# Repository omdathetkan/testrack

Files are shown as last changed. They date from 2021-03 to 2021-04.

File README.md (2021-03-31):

# Introduction
This repository contains design files and documentation for a modular test equipment rack. It was designed internally by Hiber to improve the efficiency around various test setups. It's targetted to the following use cases:
- Hardware bring-up and firmware development
- CI with Hardware in the Loop testing
- Integration testing of large / distributed systems

The key aspects on which it attempts to improve on are:
- Accessibility: Have every piece of hardware available on the network (and thus remotely)
- Portability: Make it easy to move components around or take them home.
- Repeatability: Make sure you always get the same results by having reproducable setups.
- Scaleability: The system should scale from develop desks (at home) ro large scale automated test racks.
- Low-Code: Where possible embedded firmware should be avoided so users not end up testing the test system. 

This work has been inspired by other great projects like these:
- [EasyPhi](http://www.easy-phi.ch/)
- [ARM Hardware Build Farm](https://www.collabora.com/about-us/blog/2013/04/26/collabora-custom-arm-hardware-build-farm/)
- [Raspberry Pi FM Stream Rack](https://medium.com/artica/fm-stream-tech-report-30b23c098bdb)

## License
The design has been made open source hoping that others can benifit from it. There is a lot of potential for adding additional modules (Like a configurable power supply, additional interfaces and various measurement equipment). All designs provided in this repository are released under [Apache 2.0 License](/LICENSE).

## Used Software
Boards have been made in Altium Designer, Mechanical assemblies have been done in CATIA. Neutral exports file formats are provided.

## Status
The Backplane and Breadboard module initial prototypes are finished. The Raspberri Pi Host module still have to be made for the system to start being practical (unless used for Ethernet Only applications). 

# System overview
The system is based on the very commonly used Eurocard Subrack formfactor. It is commonly used by modular test equipment like the PXI chassis and many others. The individual mechanical components are relatively low cost and widely available from multiple vendors. This design is baselined on the Schroff europacPro series and their Plug-In units, but others can be used if preferred.

A typical 19" rack is 3U high and 84HP wide (1 Horizontal Pitch = 5.08mm). In this housing the user can slide in Eurocard size PCBs or Modules with a 4HP wide pitch. The modules can either consist of instrumentation equipment or the Device Under Test itself. A generic backplane PCB provides connectivity and power to modules that are hot-swappable. By splitting the backplane into 3 identical 28HP segments the system can be scaled down to partial racks and benchtop housings.

It is highly recommended to scroll through Schroff's [catalog](https://schroff.nvent.com/sites/g/files/hdkjer281/files/acquiadam/2020-11/06_e_subracks.pdf) to get an idea about the possibilities. For example an 6U enclosure could also be used to support larger modules or double the capacity (or a combination of both).

## Enclosures

### Benchtop
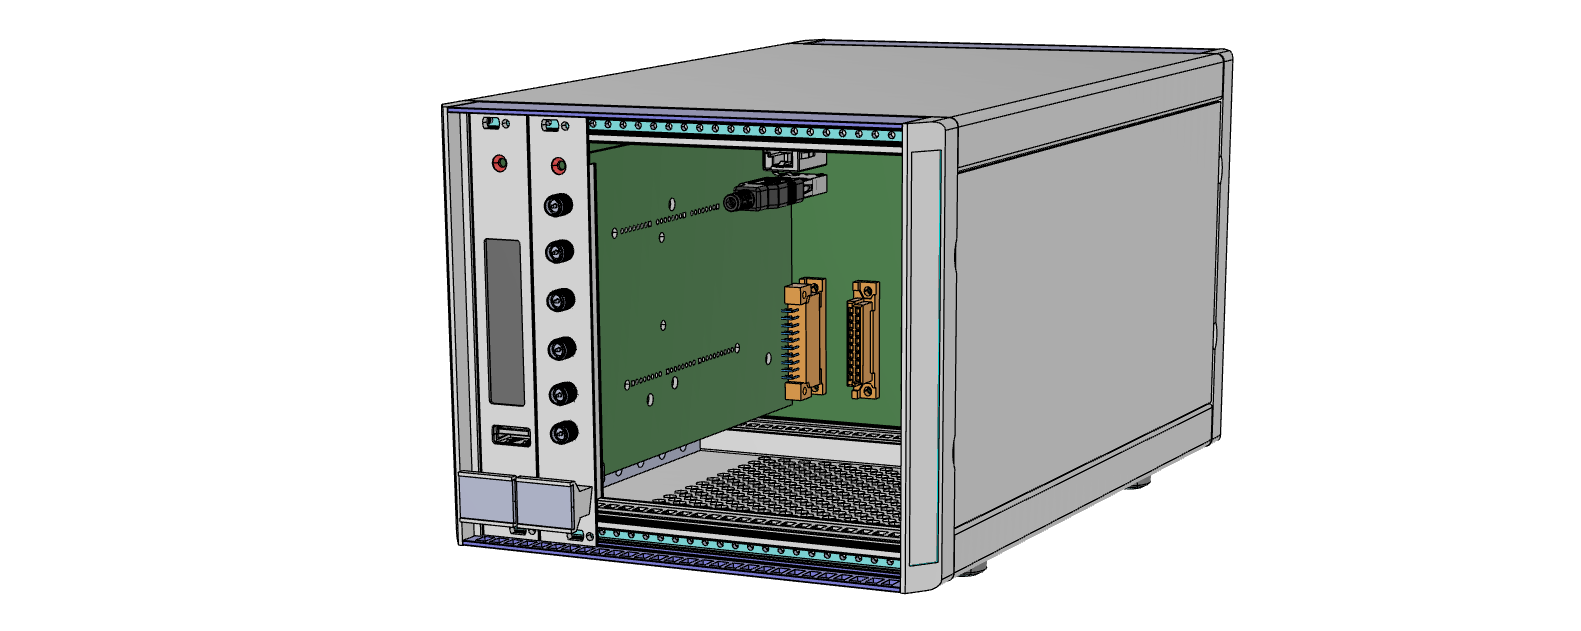
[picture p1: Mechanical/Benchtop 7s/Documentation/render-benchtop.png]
Benchtop Assembly Render


For small setups or engineering workbenches a compact form factor is available. A 28HP housing can house a single backplane with an internal AC power supply. Bill of Material and Assembly instructions can be found in it's [directory](./Mechanical/Benchtop%207s)

### 19" Rack
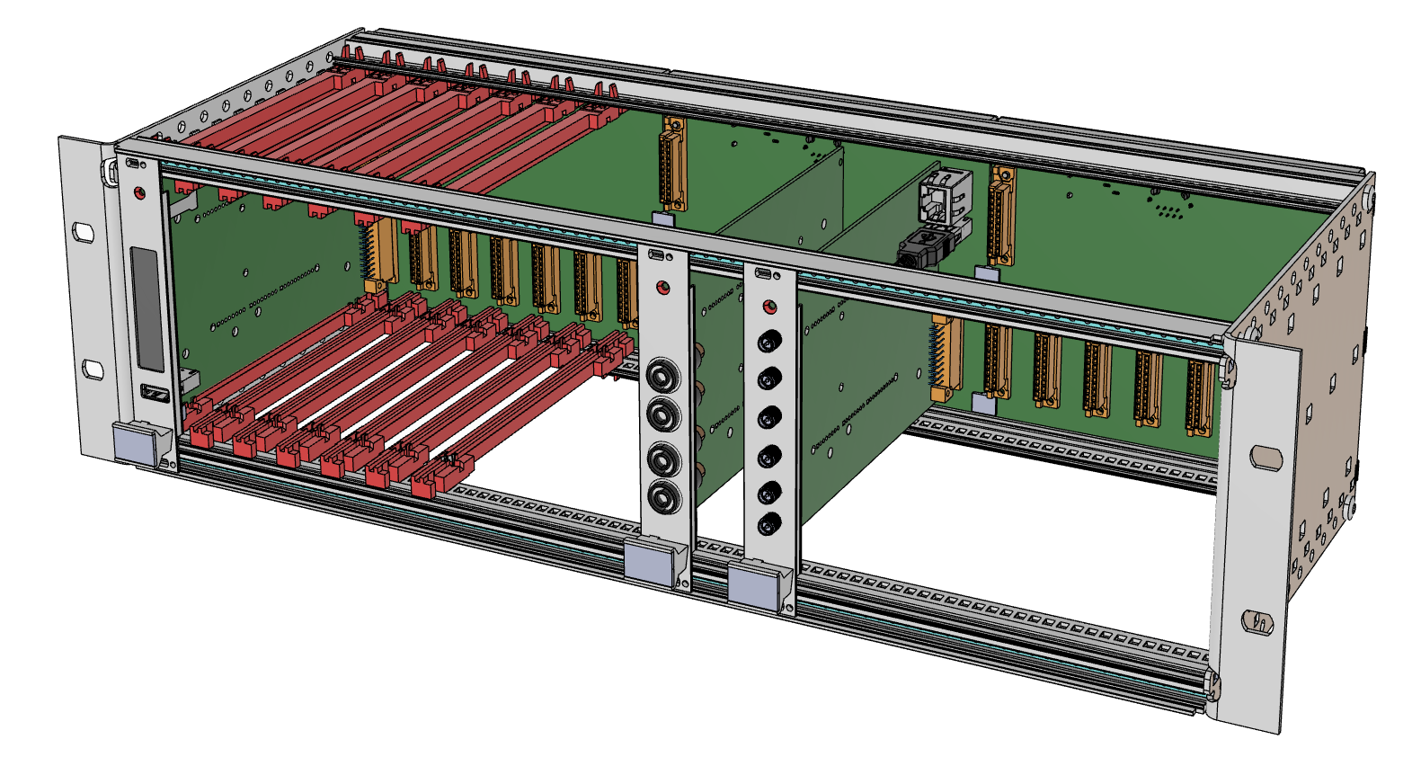
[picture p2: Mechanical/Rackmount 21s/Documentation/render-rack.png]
19" Rack Assembly Render


For larger scale setups a full 19" Rack can hold up to 21 modules. Bill of Material and Assembly instructions can be found in it's [directory](./Mechanical/Rackmount%2021s)

### Stand-alone Adapter
To be Designed... Mostly used for troubleshooting. Similar to [this](http://easy-phi.unige.ch/index.php/products/racks-and-adapter/stand-alone-adapter). PoE? USB-C? Alternatively a 20-pin extension cable could potentially be used?

## Backplane
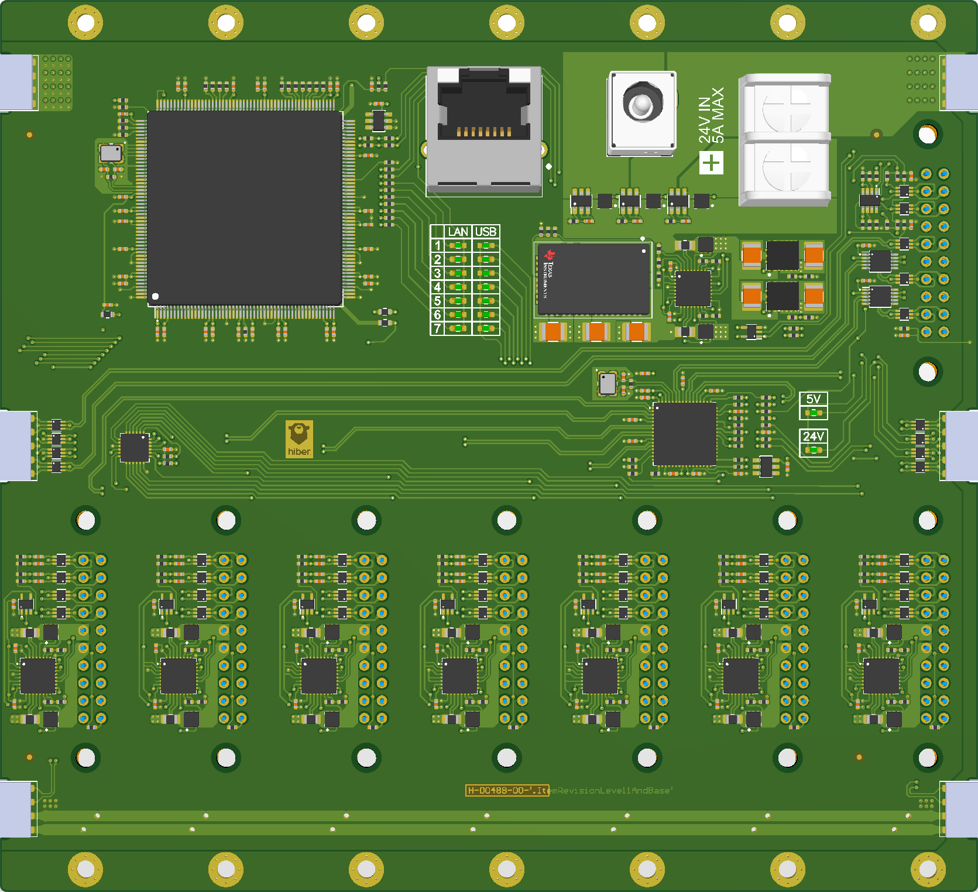
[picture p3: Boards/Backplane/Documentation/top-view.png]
Top view of backplane board


The core of the system is a 3U / 28HP backplane PCB that can be mounted in various mechanical configuations. The main functionality is:
- 24V Powered (5A Max)
- 7 Slots, of which 1 can be used as host (USB+I2C)
- Daisy-chainable up to three boards to fill a full rack
- 24V and 5V power distribution, protection and monitoring to modules (2A Max)
- 100Mbps Ethernet Switch (KSZ8999: 7 Slots + Uplink)
- USB 2.0 Hi-Speed 7-Port Hub Controller (USB2517)
- I2C Mux

More details (including pinouts) and design files can be found in it's [directory](./Boards/Backplane/).

## Modules

### Template
TBD

### CM4 Host
In Progress...

### Generic Carrier
A Generic plug-in card that contains a breakout connector for Ethernet and USB, as well as pads for the various other signals. It contains an EEPROM with UID for identification, and a MCP... port expander that can be used to drive distrete equipment.

It can be used to carry dev boards, boards to test or any other equipment.

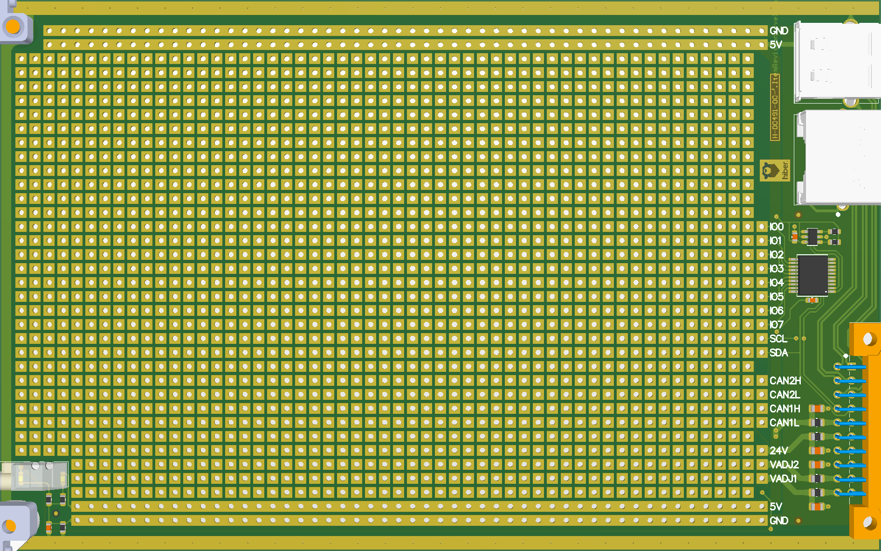
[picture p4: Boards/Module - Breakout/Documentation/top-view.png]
Top view of generic carrier board


Design files can be found in it's [directory](./Boards/Module%20-%20Breakout/).

## Ideas
- 6x Micromod carrier (Using USB2517) for testing wireless netwoks?

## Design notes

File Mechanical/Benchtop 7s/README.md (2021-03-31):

# Benchtop Enclosure
For smaller setups, or engineering workbenches a smaller form factor can be desirable. An 28HP housing can host a single backplane, as well as an internal AC power supply.

19" Rack Render
(TODO: Update render with guides and ESD clips)

The STEP model of the assembly is available [here](./Benchtop%20Assembly.stp)
(TODO: Add STEP Model)

# Bill of Materials

| Qty | Description | Manufacturer | Partnumber |
|-----|---|---|---|
| 1 | RatiopacPRO, Complete Case, Desktop, Unshielded, Front Trim, 3U, 28 HP | Schroff | 24572-001 |
| 14  | Guide Rail Standard Type, Groove Width 2 mm, 160 mm, Red, SPQ 50 | Schroff | 64560-001 |
| 7 | Guide Rail ESD Clip | Schroff | 24560-255 |
| 1 | AC-DC Single output Open frame power supply; output 24Vdc at 5.9A | Meanwell | EPP-200-24 |
| 1 | AC Power Entry Modules 15A WIRE-LEADED | TE | 15SRBX8-R |
| 1 | RJ-45 Ethernet Round Panel Mount Extension Cable - 30cm | Adafruit | 4215 |
| 1 | Connector Housing 3POS 3.96MM | JST | VHR-3N |
| 1 | Connector Housing 6POS 3.96MM | JST | VHR-6N |
| 6 | Pre-Crimped Jumper wire VH Series 16 AWG - 100mm* | JST | ASVHSVH16K102  |
| 4 | A2 s/steel cross pan head screw, M3 x 6mm | RS PRO | 528-738 |
| 14  | A2 s/steel cross pan head screw, M2.5 x 16mm | RS PRO | 914-1484 |
| 1 | Rear Panel with mount for Power supply and Connectors (CNC Machined) | | |
| 1 | Backplane PCB assembly (with protective cover) | | |

# Rear Panel
A customized rear panel is used instead of the one included with the kit. It can be ordered through Frontpanel Designer (US: [Frontpanel Express](https://www.frontpanelexpress.com/), EU: [Schaeffer](https://www.schaeffer-ag.de)).

Design files for Frontpanel Express are included in the [Rear Panel subfolder](./Rear%20Panel/). DXF and STEP files are also included.

# Assembly Instructions

## Rear Panel
- Install Ethernet Extension Cable and fasten ring nut.
- Insert power entry module (snaps into place)
- Mount Power supply on rear panel standoffs using M3-L6 Screws (Allign Line voltage on power entry side)
- Cut power entry wires to [xxx]mm, crimp terminals?
- Insert Pre-crimped wires into 6-way housing, cut to [xxx]mm length and strip around 5mm.

(TODO: Use pre-crimped wires or crimp on Power Entry Leads?)

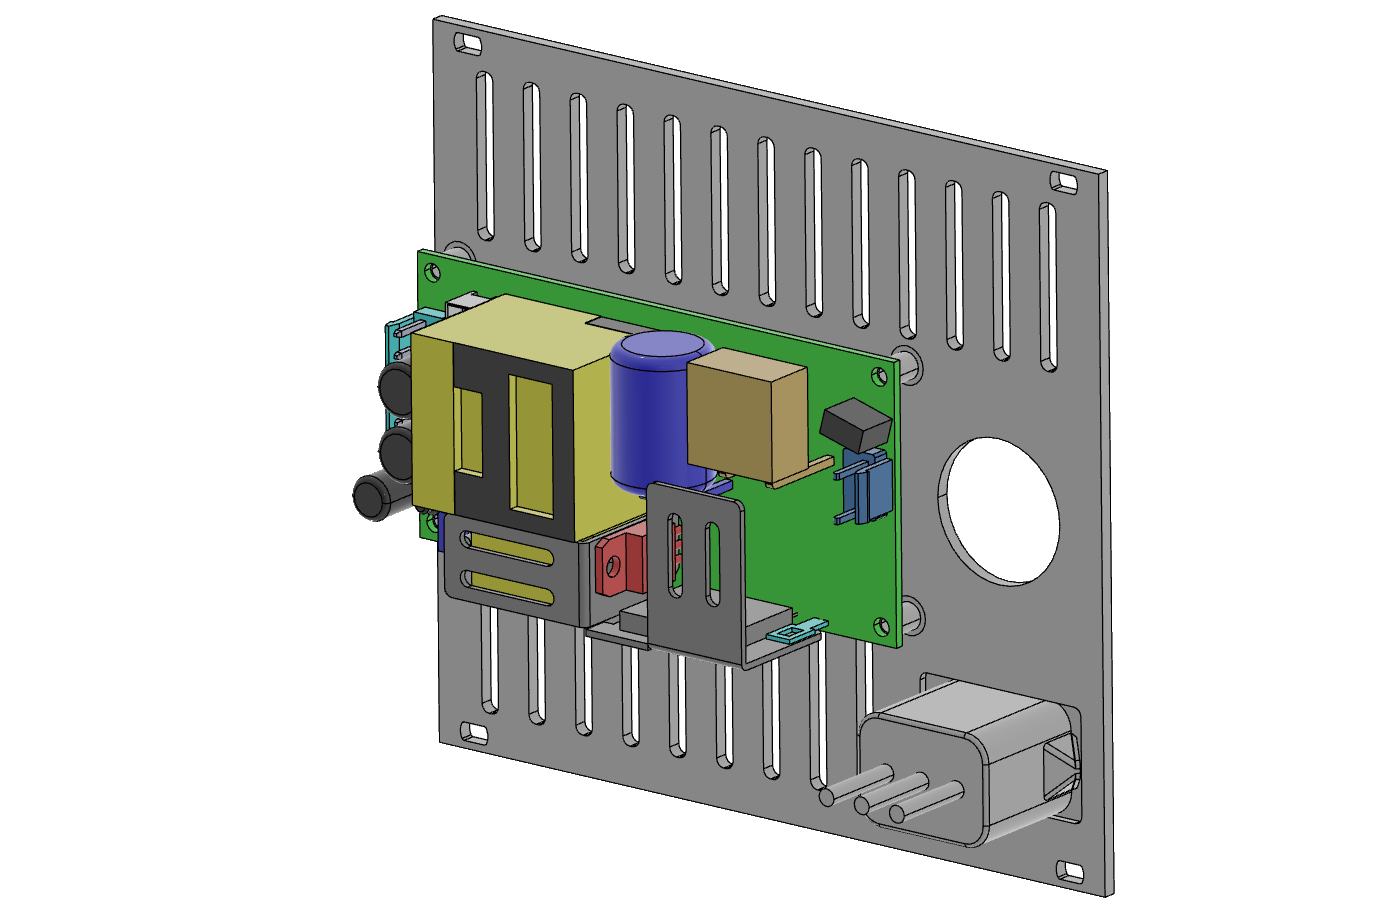
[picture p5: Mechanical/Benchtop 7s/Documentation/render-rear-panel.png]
Rear Panel Render


## Assemble Case Frame
- Partially assembly case frame according to Schroff instructions:

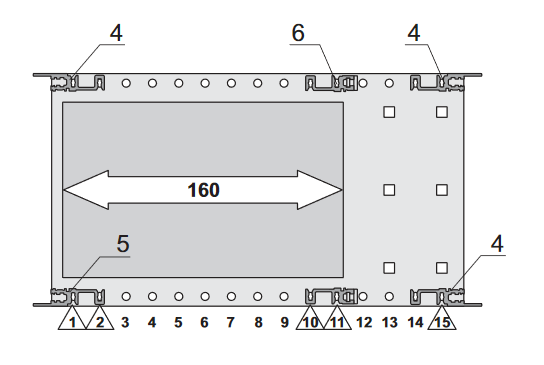
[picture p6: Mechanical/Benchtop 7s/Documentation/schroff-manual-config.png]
Schroff assembly configuration


- Note that it is easier to mount the backplane PCB before placing the rear rails:

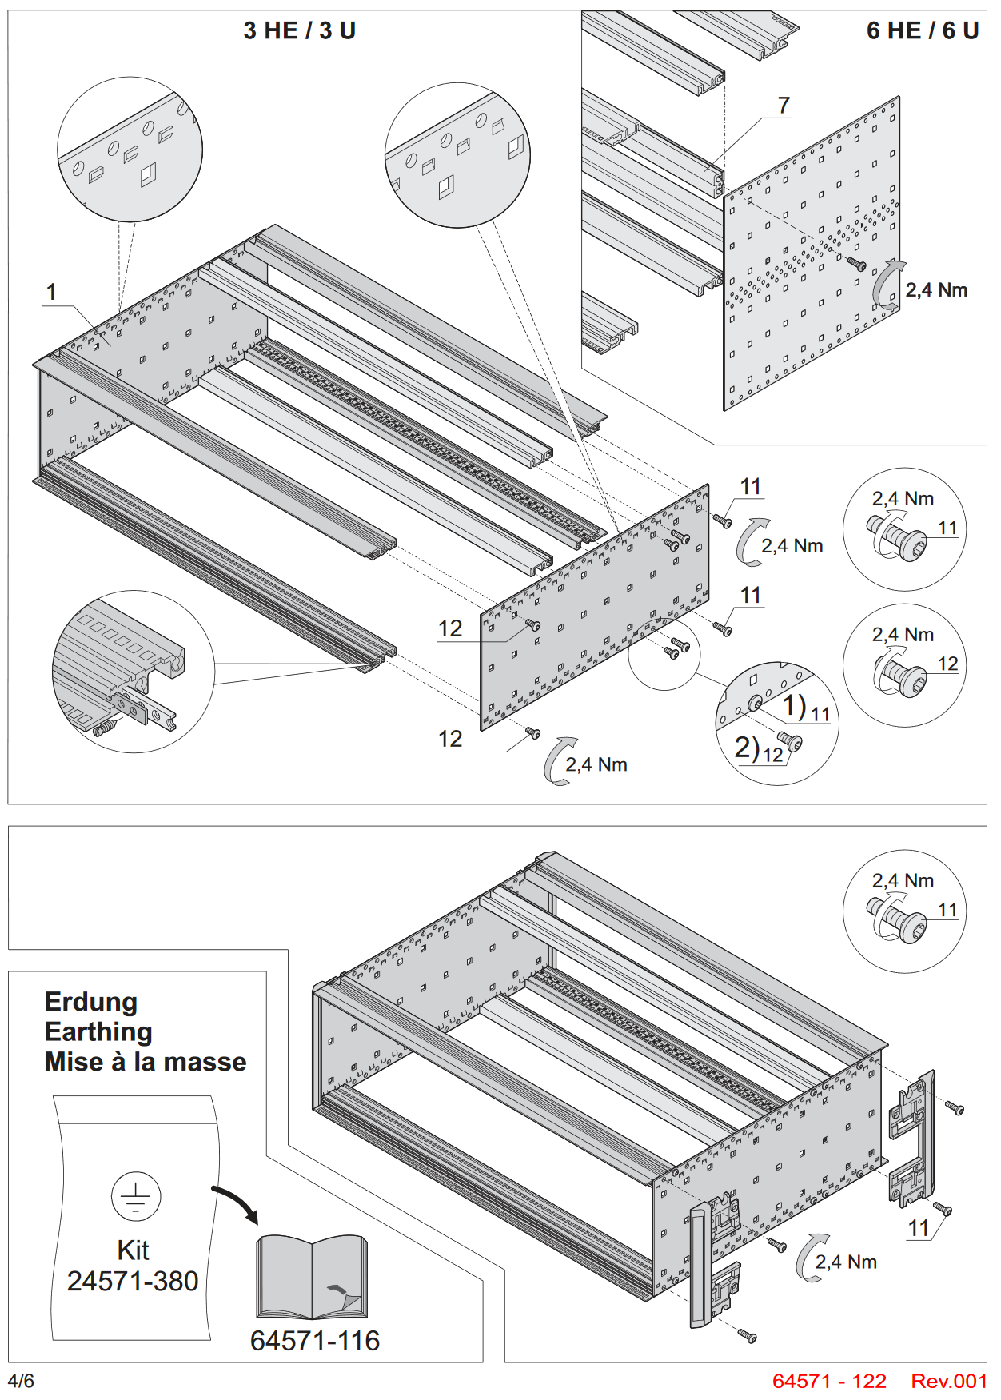
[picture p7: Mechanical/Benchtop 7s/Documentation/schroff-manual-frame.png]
Schroff frame assembly instructions


- Place backplane to frame (Check alignment?) and fasten using M2.5 screws.
- Insert Rails with ESD clips on bottom side with 4HP spacing (2 free holes in between each rail)
- Insert Rails without ESD clips on top side
- Install Ground wiring (TODO)
- Plug Ethernet Cable in
- Connect 24V Leads to wire terminals (TODO)
- Power on, verify functionality
- Snap on outer panels according to Schroff instructions:

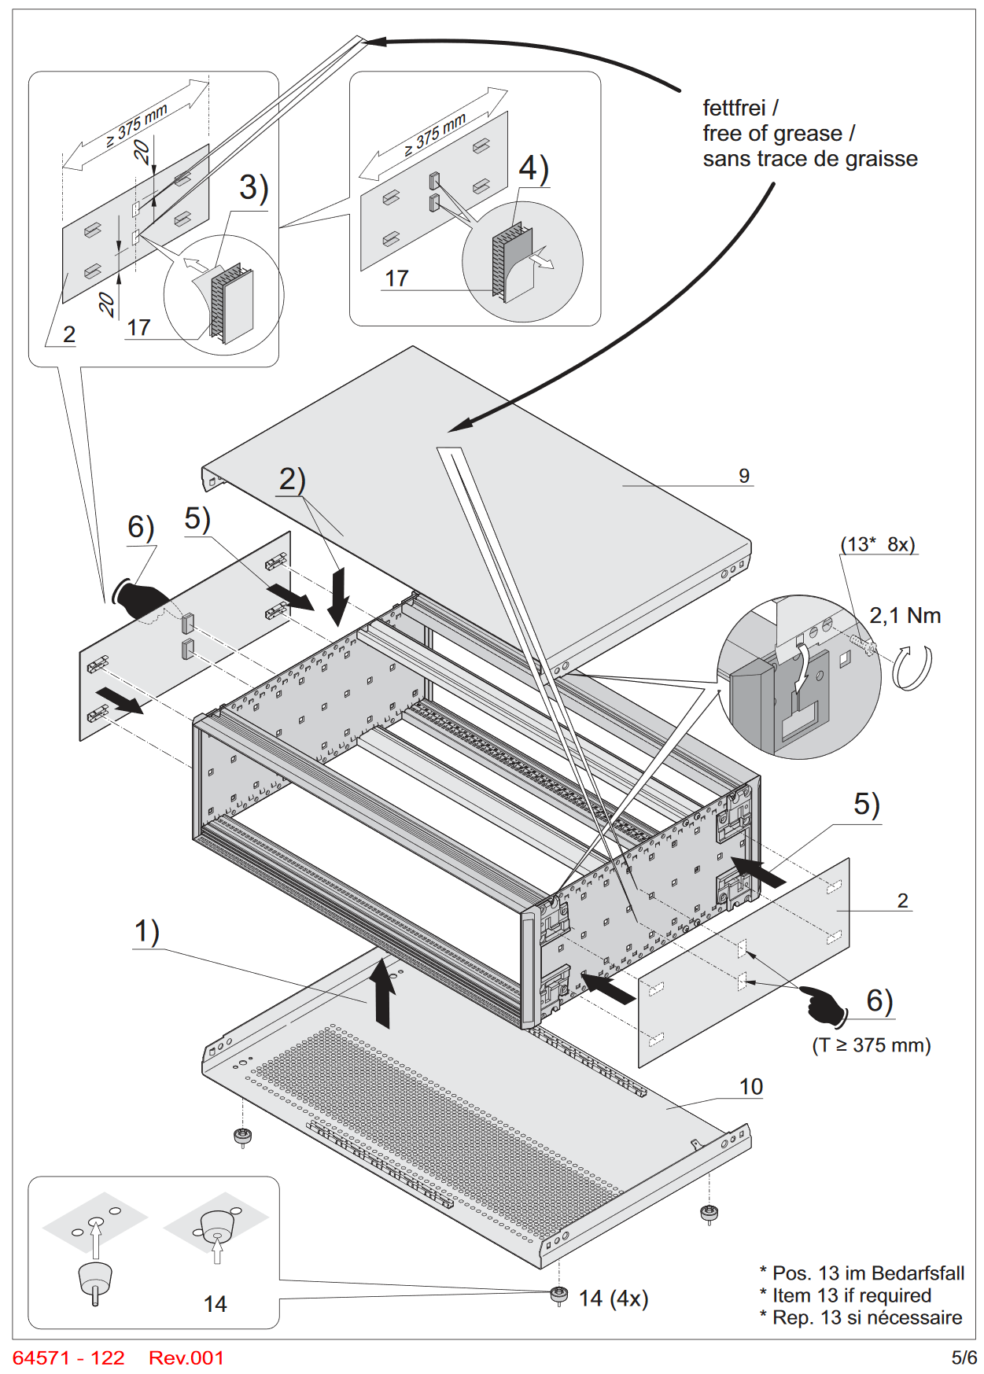
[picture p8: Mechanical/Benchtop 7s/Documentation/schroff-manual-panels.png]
Schroff panel assembly instructions


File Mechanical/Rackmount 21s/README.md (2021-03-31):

# 19" Rack
For larger scale setups a full 19" Rack can hold up to 21 modules. 

19" Rack Render
(TODO: Update render with guides and ESD clips)

The STEP model of the assembly is available [here](./Rack%20Assembly.stp)
(TODO: Add STEP Model)

# Bill of Materials

| Qty | Description | Manufacturer | Partnumber |
|-----|---|---|---|
| 1 | EuropacPRO 19" Subrack Kit for DIN Connector, Retrofit Shielding, 3U | Schroff | 24563-192 |
| 42  | Guide Rail Standard Type, Groove Width 2 mm, 160 mm, Red, SPQ 50 | Schroff | 64560-001 |
| 21  | Guide Rail ESD Clip | Schroff | 24560-255 |
| 42  | A2 s/steel cross pan head screw, M2.5 x 16mm | RS PRO | 914-1484 |
| 4 | CONN SSL BRIDGE 8POS 2MM | AVX | 009159008061916 |
| 2 | CONN SSL BRIDGE 10POS 2MM | AVX | 009159010061916 |
| 3 | Backplane PCB assembly (with protective cover) | | |

# Assembly Instructions

- Assembly frame according to Schroff Instructions

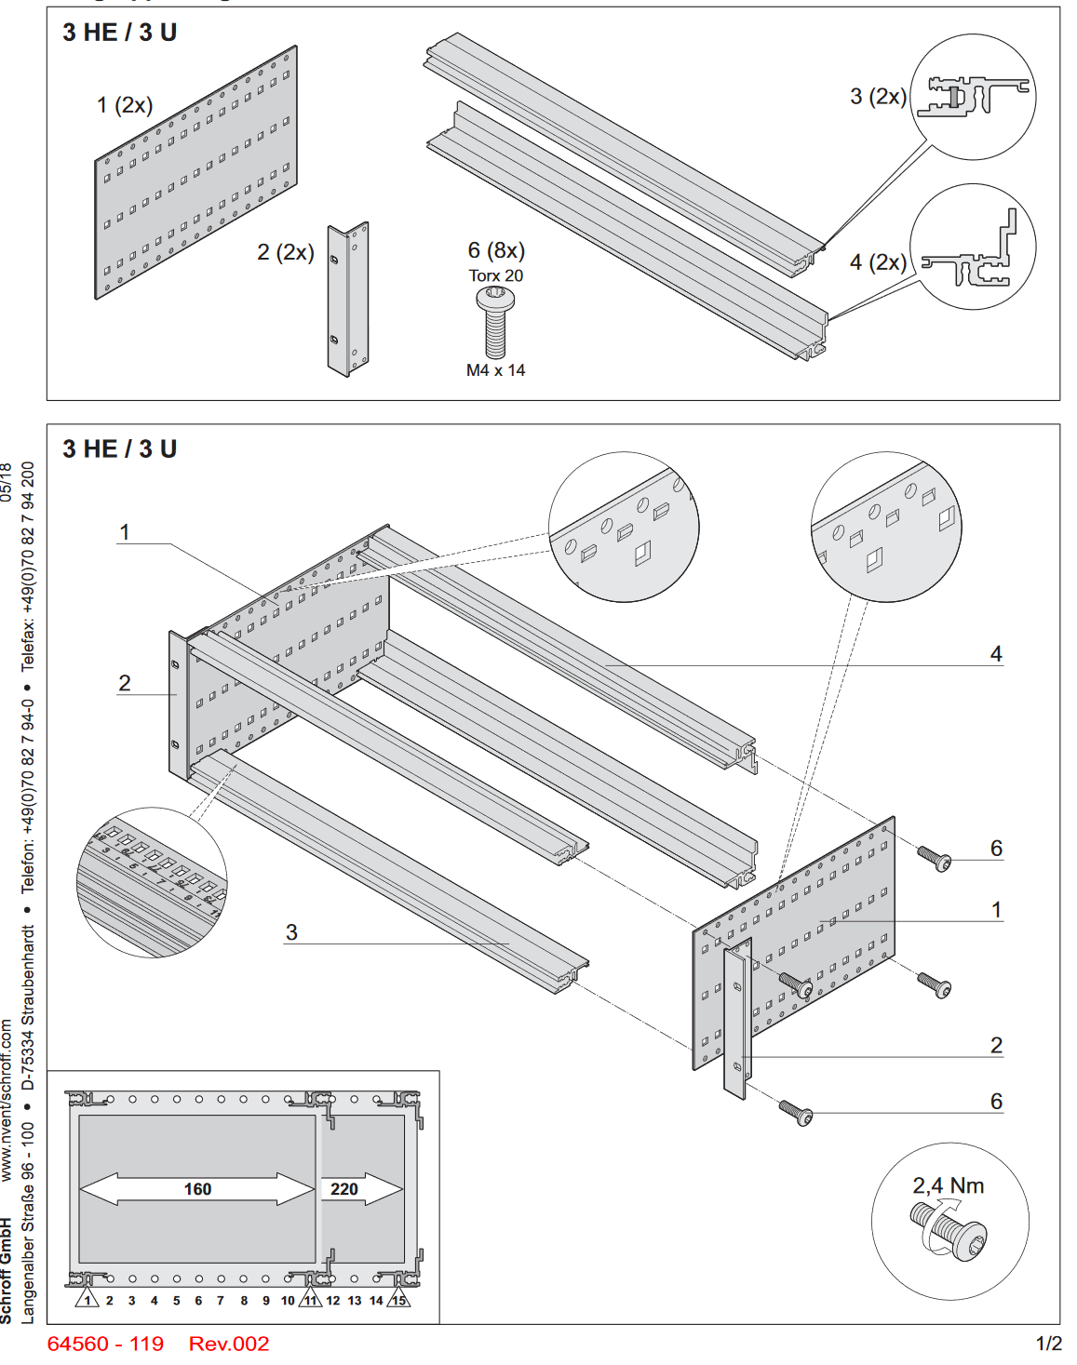
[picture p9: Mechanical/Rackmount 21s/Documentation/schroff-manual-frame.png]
Schroff frame assembly instructions


- Mount Single backplane using M2.5 Screws
- Slide in Bridge Connectors
- Mount Slide in second backplane and fasten.
- Repeat for last backplane

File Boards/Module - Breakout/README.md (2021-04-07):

# Breakout Module
Top view of backplane board
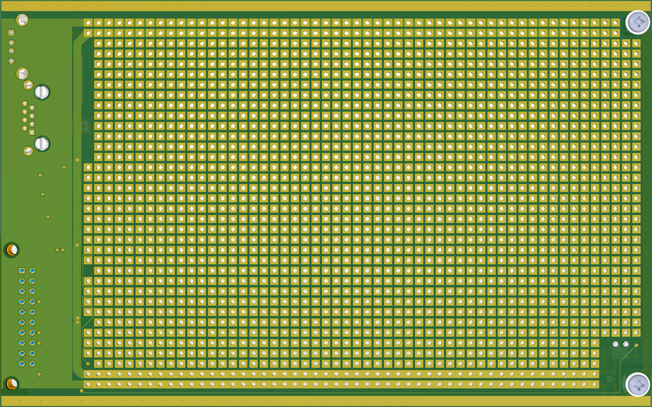
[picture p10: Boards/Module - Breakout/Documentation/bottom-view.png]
Bottom view of backplane board


This module can be used integrate any existing board or other hardware to the system.

One way is by using solderable thread inserts, like the ones from [Wurth](https://www.we-online.com/web/en/electronic_components/produkte_pb/produktinnovationen/smtspacer.php).

For larger boards a (short) Right-Angle usb cable might be needed, for example: Startech Male USB A to Male USB Micro B USB Cable, USB 2.0, 300mm, USB A, USB Micro B UUSBHAUB1LA

To install a board:
- Identify the appropriate standoff height (ideally make sure nothing extends over the frontpanel).
- Attach the spacers to the board and place the board on the desired location.
- Solder down a corner of each spacer and remove the board.
- Strengthen solder joints.
- Re-install board (plug in cables)

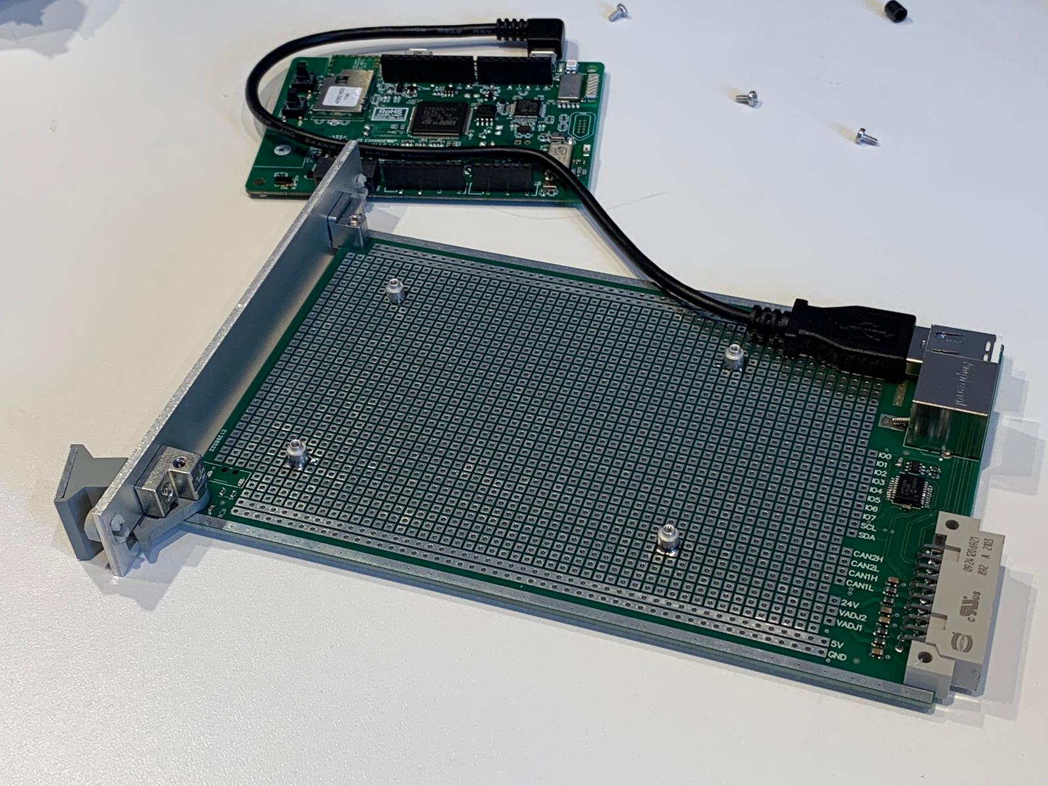
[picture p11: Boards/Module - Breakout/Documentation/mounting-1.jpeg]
Picture of spacers soldered to board


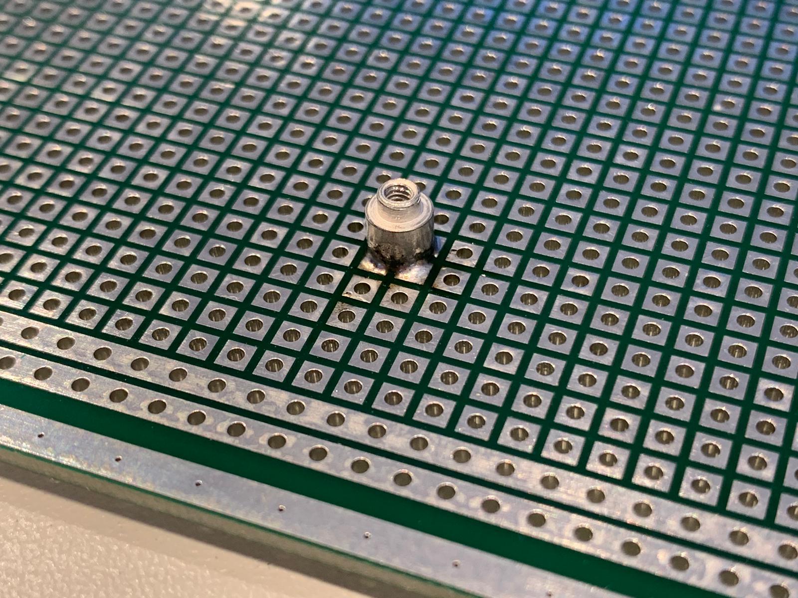
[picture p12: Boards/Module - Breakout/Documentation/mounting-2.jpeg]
Close-up of spacer soldered to board


Picture of board mounted on spacers

nVent-SCHROFF, 3U Plug-in Unit

RS-stocknr.:
    258-2920
Fabrikantnummer:
    20817443
Fabrikant:
    nVent-SCHROFF

# Version History

## A.3
First Release

### Known Issues
- Missing Pin-1 Indicator on U10
- Increase solder mask sliver between ESD Cap/Res
- USB D+/D- Swapped

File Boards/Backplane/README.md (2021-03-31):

# Backplane
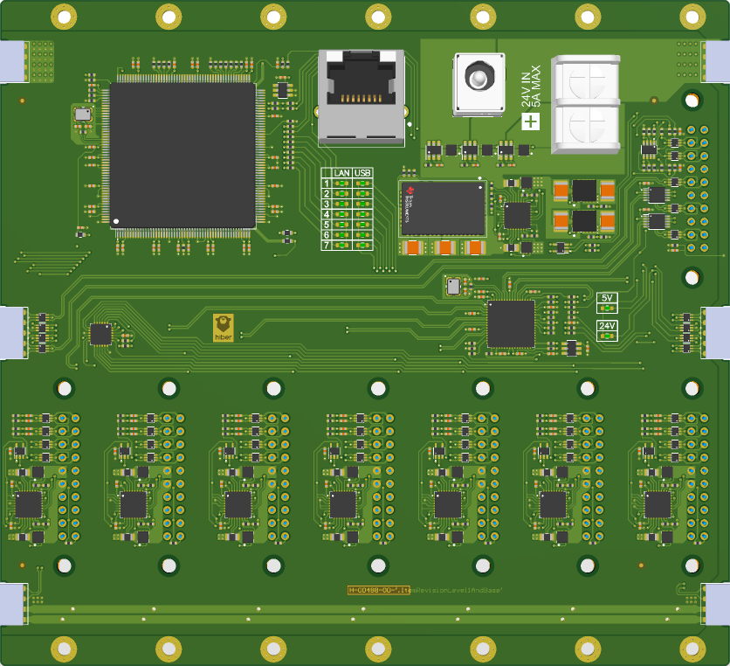
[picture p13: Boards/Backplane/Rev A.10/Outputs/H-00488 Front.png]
Top view of backplane board

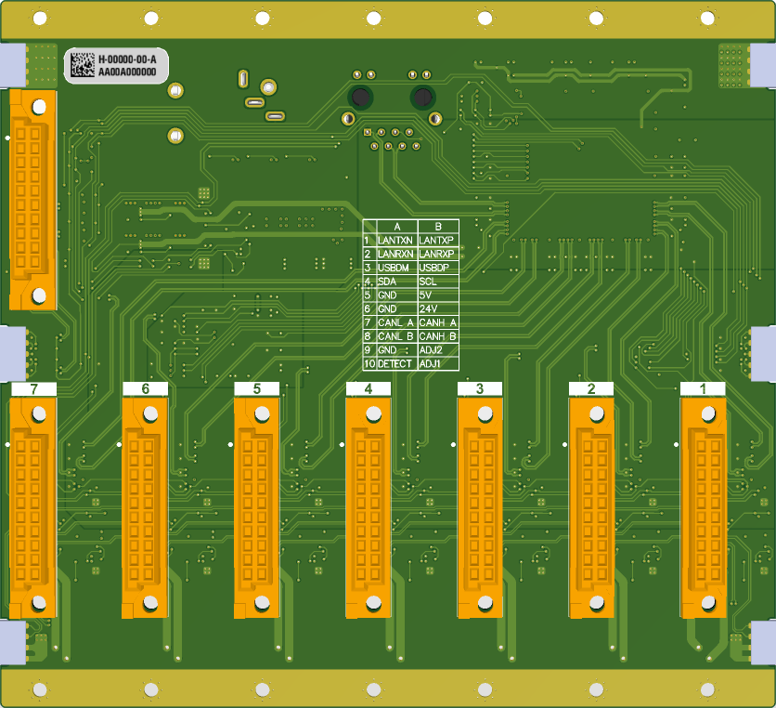
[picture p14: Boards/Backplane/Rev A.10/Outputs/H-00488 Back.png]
Bottom view of backplane board


The core of the system is a 3U / 28HP backplane PCB that can be mounted in various mechanical configuations. The main functionality is:
- 24V Powered (5A Max)
- 7 Slots, of which 1 can be used as host (USB+I2C)
- Daisy-chainable up to three boards to fill a full rack
- 24V and 5V power distribution, protection and monitoring to modules (2A Max)
- 100Mbps Ethernet Switch (KSZ8999: 7 Slots + Uplink)
- USB 2.0 Hi-Speed 7-Port Hub Controller (USB2517)
- I2C Mux (Dedicated channel for each module)
- 2 Additional voltage rails and 2 differential pairs (CAN) - passively connected between slots

Image of backplane pcb topology

It uses [DIN 41612](https://en.wikipedia.org/wiki/DIN_41612) connectors for the plug-in modules, for examaple the [Harting 09241206921](https://b2b.harting.com/ebusiness/nl/DIN-Signal-3B020MS-30C1-2/09241206921), but since it's a standard other vendors are also available.

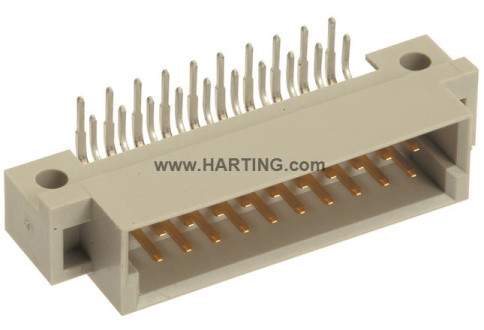
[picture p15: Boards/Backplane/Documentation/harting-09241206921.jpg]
Picture of a Harting 09241206921


Optionally the rear can be covered using 2-layer laser-cut acrylic sheets for protection against bumps and shorts. Details can be found [here](./Protective%20Cover).

Mating Connector for Power Jack: PP3-002B (2.5mm Pin / 5.5mm Diameter)

### Slot Interface
Each slot has a 20-pin connector (3B, Bottom-aligned) connector with the following pinout:

| | A | B |
|----|---|---|
| 1  | LAN RX- | LAN RX+ |
| 2  | LAN TX- | LAN TX+ |
| 3  | USB D-  | USB D+  |
| 4  | SDA | SCL |
| 5  | GND | +5V |
| 6  | GND | +24V |
| 7  | CANA L  | CANA H  |
| 8  | CANB L  | CANB H  |
| 9  | GND | VADJ2 |
| 10 | DETECT  | VADJ1 |

Modules are hot-swappable. By grounding the detect pin is on the plug-in module the Hot-Swap controller will enable power. 
Note that Ethernet is capacitively coupled - use of additonal magnetics might be advised depending on the application.

## Host Interface
There is a special host slot which has a second 20-pin connector which is used for USB-Host and I2C Master functionality. For Ethernet based functionality the use of this is optional.

It has the following pinout:

| | A | B |
|----|---|---|
| 1  | NC | NC |
| 2  | SDA_HOST  | SCL_HOST  |
| 3  | DETECT | RESET_HOST|
| 4  | GND | GND |
| 5  | USB3 D- | USB3 D+ |
| 6  | GND | GND |
| 7  | USB2 D- | USB2 D+ |
| 8  | GND | GND |
| 9  | USB1 D+ | USB1 D+ |
| 10 | GND | GND |

Note that USB 1 is from the backplane itself, USB 2 and 3 are from daisy chained backplanes if present. When there is no host card present, USB 1 and 2 are routed to the daisy chain connector (to be come USB 2 and 3 on the next board).

Image showing USB daisy chain topology

For a typical setup this slot contains something like a Raspberry Pi to control the rest of the system and/or bridge it to the network.

# Version History

## B.X
Scheduled - to fix known issues on version A.10

### Changes
LTC4222 optional? LAN/USB optional?

## A.10
First Release

### Known Issues
- LTC4222 generates INTVCC from VDD2, which is 5V, which is gated by itself, 5V/24V need to be swapped
    - Rework: Bypassed primary 24V Hot Swap controller output with a jumper wire
- I2C Mux messed up pinout ([excel table](./Documentation/rework-reva-i2cmux.md))
    - Rework: Swapped some nets to fix I2CM and I2C0 ([picture](./Documentation/rework-reva-i2cmux.png))
- I2C A0/A1 missing pull-up (or push/pull output (Both NC/NC)
    - Rework: Added A0/A1 pull-up 4k7 ([picture](./Documentation/rework-reva-address-pullup.png))
- Bad US_REF value (Also update table)
    - Rework: Swapped R199/R200
- Edge connector slots are too short and flipped between left/right
    - Rework: Cut material using scalpel
- I2C LTC4222 Address overlap with SLOT2/Main power
    - Rework: Connected PWR_ADR0 to GND
- 24V/5V PGOOD has some issues, might be due to under/overcurrent config
    - *TODO*
- RJ45 Jack LED Polarity is reversed
- Silkscreen indicating upstream/downstram direction is missing
- 24/5V LED silkscreen is swapped
- USB/LAN EEPROMs should be depopulated?
- Wash after hand solder (Eurocircuits)
- Missing EEPROM/Serial chip for identification

### TODO
- Validate power rail stability/noise
- Validate overcurrent protection (board / module level)
- Measure current consumption for USB/LAN
v Test I2C Address Daisy chain
- Validate thermal performance with and without plastic cover (especialy on buck converters)
- Validate hot-swapping behavior
v Validate USB daisy chaning
- Check weird sounds

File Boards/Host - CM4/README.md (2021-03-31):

# Raspberry Pi CM4 Host Module

## Notes

- USB Connector : 2169890001 / KUSBX-SL-CS1N14-B

https://github.com/QWaveSystems/QWAVE_Raspberry-Pi-CM4-Altium-Library

https://datasheets.raspberrypi.org/cm4io/cm4io-datasheet.pdf#page=11
USB2514B-I/M2
FSUSB42MUX

2x CAN-FD

24V-5V?
24V-VLCD

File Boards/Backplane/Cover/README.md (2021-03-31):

# Protective Cover
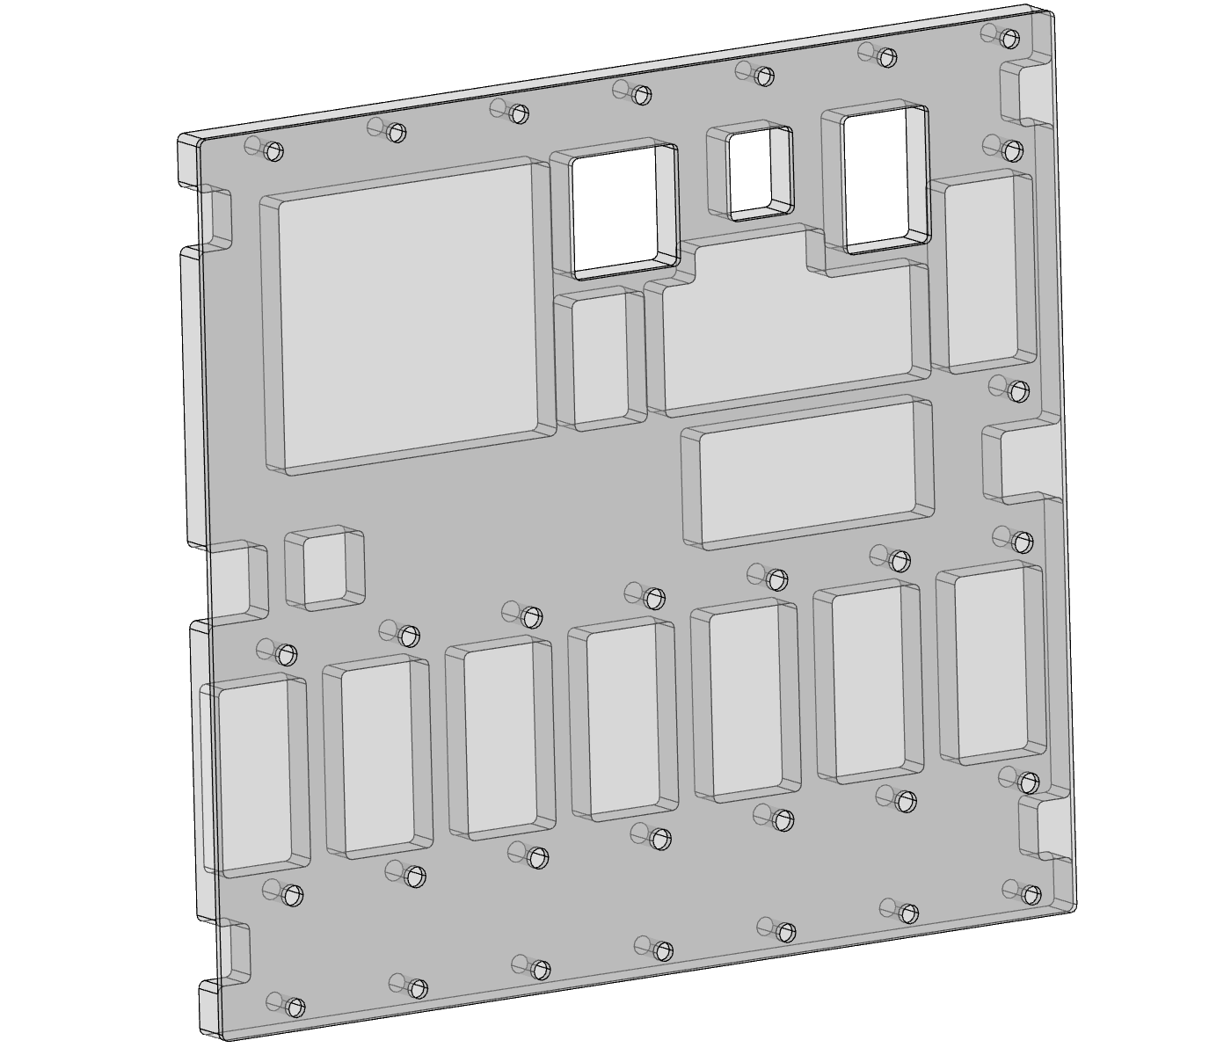
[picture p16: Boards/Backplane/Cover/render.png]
Isometric view of backplane cover render


A Protective cover made of two laser cut acrylic sheets that can be mounted on the back of the backplane board. It provides some extra protection against mechanical abuse or accidental shorts. Design files can be found in this folder.

The 2 layers can be laser cut from many materials. Transparant Acrylic is an option. The spacer needs to be 5mm think to accomodate component height.

# Bill of Materials

| Qty | Description | Manufacturer | Partnumber |
|-----|---|---|---|
| 14  | A2 s/steel cross pan head screw, M2.5 x 12mm | RS PRO | 528-722 |
| 14  | A2 S/Steel Locking Half Nut, DIN 439, M2.5 | RS PRO | 122-4399 |
| 1 | Backplane PCB assembly | | |
| 1 | Protective Spacer | | |
| 1 | Protective Cover | | |

# Assembly Instructions

Note: Removing protective liner on acrylic sheets creates significant charge. Make sure this is dissipated before installation!

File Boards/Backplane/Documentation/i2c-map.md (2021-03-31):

# Board global address nets

A is made from A0 and A1 using N-Fet?

| Board  | A0 | A1 | A |
|---|----|----|-----|
| Left | H  | H  | L |
| Middle | L  | H  | NC  |
| Right  | H  | L  | H |

# I2C Mux - TCA9548

| A2 | A1 | A0 | Address | Binary | Position |
|----|----|----|---|---|---|
| L  | L  | L  | 0x70 | 0b1110000 | Board 0 |
| L  | L  | H  | 0x71 | 0b1110001 | Board 1 |
| L  | H  | L  | 0x72 | 0b1110010 | Board 2 |
| L  | H  | H  | 0x73 | 0b1110011 | |
| H  | L  | L  | 0x74 | 0b1110100 | |
| H  | L  | H  | 0x75 | 0b1110101 | |
| H  | H  | L  | 0x76 | 0b1110110 | |
| H  | H  | H  | 0x77 | 0b1110111 | |

# Hot Swap Controllers - LTC4222

| A2 | A1 | A0 | Address | Binary | Position |
|----|----|----|---|---|---|
| X  | X  | X  | C6 | 0b1100011 | |
| X  | X  | X  | 19 | 0b0001100 | |
| L  | NC | L  | 88 | 0b1000100 | Board 0 - In |
| L  | H  | NC | 8A | 0b1000101 | Board 0 - Slot 1 |
| L  | NC | NC | 8C | 0b1000110 | Board 0 - Slot 2 |
| L  | NC | H  | 8E | 0b1000111 | Board 0 - Slot 3 |
| L  | L  | L  | 98 | 0b1001100 | Board 0 - Slot 4 |
| L  | H  | H  | 9A | 0b1001101 | Board 0 - Slot 5 |
| L  | L  | NC | 9C | 0b1001110 | Board 0 - Slot 6 |
| L  | L  | H  | 9E | 0b1001111 | Board 0 - Slot 7 |
| NC | NC | L  | A8 | 0b1010100 | Board 1 - In |
| NC | H  | NC | AA | 0b1010101 | Board 1 - Slot 1 |
| NC | NC | NC | AC | 0b1010110 | Board 1 - Slot 2 |
| NC | NC | H  | AE | 0b1010111 | Board 1 - Slot 3 |
| NC | L  | L  | B8 | 0b1011100 | Board 1 - Slot 4 |
| NC | H  | H  | BA | 0b1011101 | Board 1 - Slot 5 |
| NC | L  | NC | BC | 0b1011110 | Board 1 - Slot 6 |
| NC | L  | H  | BE | 0b1011111 | Board 1 - Slot 7 |
| H  | NC | L  | C8 | 0b1100100 | Board 1 - In |
| H  | H  | NC | CA | 0b1100101 | Board 1 - Slot 1 |
| H  | NC | NC | CC | 0b1100110 | Board 1 - Slot 2 |
| H  | NC | H  | CE | 0b1100111 | Board 1 - Slot 3 |
| H  | L  | L  | D8 | 0b1101100 | Board 1 - Slot 4 |
| H  | H  | H  | DA | 0b1101101 | Board 1 - Slot 5 |
| H  | L  | NC | DC | 0b1101110 | Board 1 - Slot 6 |
| H  | L  | H  | DE | 0b1101111 | Board 1 - Slot 7 |
| L  | H  | L  | E8 | 0b1110100 | |
| NC | H  | L  | EA | 0b1110101 | |
| H  | H  | L  | EC | 0b1110110 | |

# UID

| A2 | A1 | A0 | Address | Binary | Device |
|----|----|----|---|---|---|
| -  | H  | L  | C8 | 0b1010000 | Board 1 |
| -  | H  | L  | C8 | 0b1010000 | Board 2 |
| -  | H  | L  | C8 | 0b1010000 | Board 3 |

# USB Hub

| A2 | A1 | A0 | Address | Binary | Device |
|----|----|----|---|---|---|
| -  | -  | -  | C6 | 0b1010000 | EEPROM |
| -  | -  | -  | 19 | 0b0101100 | Hub |

# Ethernet Switch

| A2 | A1 | A0 | Address | Binary | Device |
|----|----|----|---|---|---|
| -  | -  | -  | C6 | 0b1010000 | EEPROM |
| -  | -  | -  | 19 | 0b0101100 | Switch |

https://www.tablesgenerator.com/markdown_tables

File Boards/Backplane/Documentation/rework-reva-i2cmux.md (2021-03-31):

| QFN (RGE) | PCB NET | NAME  | TYPE  | DESCRIPTION |
|---|---|---|---|---|
| 1 | SC0 X | SD0 |  I/O  | Serial data 0. Connect to VDPU0(1) through a pull-up resistor |
| 2 | SC1 X | SC0 |  I/O  | Serial clock 0. Connect to VDPU0(1) through a pull-up resistor |
| 3 | SC2 X | SD1 |  I/O  | Serial data 1. Connect to VDPU1(1) through a pull-up resistor |
| 4 | SC3 X | SC1 |  I/O  | Serial clock 1. Connect to VDPU1(1) through a pull-up resistor |
| 5 | SC4 X | SD2 |  I/O  | Serial data 2. Connect to VDPU2(1) through a pull-up resistor |
| 6 | SC5 X | SC2 |  I/O  | Serial clock 2. Connect to VDPU2(1) through a pull-up resistor |
| 7 | SC6 X | SD3 |  I/O  | Serial data 3. Connect to VDPU3(1) through a pull-up resistor |
| 8 | SC7 X | SC3 |  I/O  | Serial clock 3. Connect to VDPU3(1) through a pull-up resistor |
| 9 | GND | GND | — | Ground |
| 10 | SCL X | SD4 |  I/O  | Serial data 4. Connect to VDPU4(1) through a pull-up resistor |
| 11 | SD0 X | SC4 |  I/O  | Serial clock 4. Connect to VDPU4(1) through a pull-up resistor |
| 12 | SD1 X | SD5 |  I/O  | Serial data 5. Connect to VDPU5(1) through a pull-up resistor |
| 13 | SD2 X | SC5 |  I/O  | Serial clock 5. Connect to VDPU5(1) through a pull-up resistor |
| 14 | SD3 X | SD6 |  I/O  | Serial data 6. Connect to VDPU6(1) through a pull-up resistor |
| 15 | SD4 X | SC6 |  I/O  | Serial clock 6. Connect to VDPU6(1) through a pull-up resistor |
| 16 | SD5 X | SD7 |  I/O  | Serial data 7. Connect to VDPU7(1) through a pull-up resistor |
| 17 | SD6 X | SC7 |  I/O  | Serial clock 7. Connect to VDPU7(1) through a pull-up resistor |
| 18 | A2 | A2 | I | Address input 2. Connect directly to VCC or ground |
| 19 | SD7 X | SCL |  I/O  | Serial clock bus. Connect to VDPUM(1) through a pull-up resistor |
| 20 | SDA | SDA |  I/O  | Serial data bus. Connect to VDPUM(1) through a pull-up resistor |
| 21 | VCC | VCC | Power | Supply voltage |
| 22 | A0 | A0 | I | Address input 0. Connect directly to VCC or ground |
| 23 | A1 | A1 | I | Address input 1. Connect directly to VCC or ground |
| 24 | RESET | RESET | I | Active-low reset input. Connect to VCC or VDPUM(1) through a pull-up resistor, if not used |

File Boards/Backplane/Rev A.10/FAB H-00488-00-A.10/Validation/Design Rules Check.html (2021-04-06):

Altium

# Design Rule Verification Report

Date: | | 1-2-2021
Time: | | 20:55:23
Elapsed Time: | | 00:00:15
Filename: | | C:\Users\Joris\AppData\Local\TempReleases\Snapshot\1\H-00488.PcbDoc

Warnings: | | 0
Rule Violations: | | 0

## Summary

Warnings | Count
Total | 0

Rule Violations | Count
Clearance Constraint (Gap=0.15mm) (All),(All) | 0
Clearance Constraint (Gap=0.3mm) (OnLayer('Ground Plane') or OnLayer('Power Plane')),(All) | 0
Short-Circuit Constraint (Allowed=No) (All),(All) | 0
Un-Routed Net Constraint ( (All) ) | 0
Modified Polygon (Allow modified: No), (Allow shelved: No) | 0
Width Constraint (Min=0.15mm) (Max=2mm) (Preferred=0.2mm) (All) | 0
SMD To Corner (Distance=0.1mm) (Not InNet('*SENSE*') And Not InNet('V_24P0') And Not InNet('V_5P0') And Not InNet('V_IN_24P0') And Not InNet('V_REG_5P0')) | 0
SMD Entry (Side = Allowed) (Corner = Not Allowed) (Any Angle = Not Allowed) (Ignore First Corner = Allowed) | 0
Power Plane Connect Rule(Direct Connect )(Expansion=0.175mm) (Conductor Width=0.2mm) (Air Gap=0.2mm) (Entries=4) (All) | 0
Minimum Annular Ring (Minimum=0.174mm) (((ObjectKind = 'Pad') OR (ObjectKind = 'Via')) And (Layer = 'MultiLayer') And (HoleDiameter <= AsMM(0.45))) | 0
Minimum Annular Ring (Minimum=0.174mm) (((ObjectKind = 'Pad') OR (ObjectKind = 'Via')) And (Layer = 'MultiLayer') And (HoleDiameter > AsMM(0.45))) | 0
Hole Size Constraint (Min=0.25mm) (Max=3.5mm) (All) | 0
Hole To Hole Clearance (Gap=0.35mm) (All),(All) | 0
Hole To Hole Clearance (Gap=0.2mm) (Not PadIsPlated),(Not PadIsPlated) | 0
Minimum Solder Mask Sliver (Gap=0.08mm) (All),(All) | 0
Silk To Solder Mask (Clearance=0.1mm) (IsPad),(All) | 0
Silk to Silk (Clearance=0.2mm) (All),(All) | 0
Net Antennae (Tolerance=0mm) (All) | 0
Board Clearance Constraint (Gap=0mm) (Not OnSilkscreen) | 0
Room SLOT1 (Bounding Region = (21.48mm, 68.45mm, 41.8mm, 110.36mm) (InComponentClass('SLOT1')) | 0
Room I2C (Bounding Region = (32.2mm, 112.795mm, 49.1mm, 120.695mm) (InComponentClass('I2C')) | 0
Room MASTER (Bounding Region = (139.3mm, 122.72mm, 172.5mm, 166.995mm) (InComponentClass('MASTER')) | 0
Room POWER (Bounding Region = (97.3mm, 114.995mm, 142.1mm, 156.475mm) (InComponentClass('POWER')) | 0
Room CONNECTORS (Bounding Region = (81.7mm, 150.095mm, 143.6mm, 172.495mm) (InComponentClass('CONNECTORS')) | 0
Room USB (Bounding Region = (90.1mm, 111.995mm, 138.1mm, 149.395mm) (InComponentClass('USB')) | 0
Room LAN (Bounding Region = (22.9mm, 96.395mm, 148.9mm, 171.595mm) (InComponentClass('LAN')) | 0
Room DOWNSTREAM (Bounding Region = (14.825mm, 55.75mm, 33.6mm, 175.75mm) (InComponentClass('DOWNSTREAM')) | 0
Room ADDR (Bounding Region = (142.4mm, 147.195mm, 157.8mm, 161.495mm) (InComponentClass('ADDR')) | 0
Room SLOT3 (Bounding Region = (62.12mm, 68.45mm, 82.44mm, 110.36mm) (InComponentClass('SLOT3')) | 0
Room SLOT2 (Bounding Region = (41.8mm, 68.45mm, 62.12mm, 110.36mm) (InComponentClass('SLOT2')) | 0
Room SLOT6 (Bounding Region = (123.08mm, 68.45mm, 143.4mm, 110.36mm) (InComponentClass('SLOT6')) | 0
Room SLOT4 (Bounding Region = (82.44mm, 68.45mm, 102.76mm, 110.36mm) (InComponentClass('SLOT4')) | 0
Room SLOT7 (Bounding Region = (143.4mm, 68.45mm, 163.72mm, 110.36mm) (InComponentClass('SLOT7')) | 0
Room UPSTREAM (Bounding Region = (151.6mm, 55.75mm, 170.075mm, 175.75mm) (InComponentClass('UPSTREAM')) | 0
Room SLOT5 (Bounding Region = (102.76mm, 68.45mm, 123.08mm, 110.36mm) (InComponentClass('SLOT5')) | 0
Height Constraint (Min=0mm) (Max=25mm) (Prefered=12.5mm) (All) | 0
Total | 0

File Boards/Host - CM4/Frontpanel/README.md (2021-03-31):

# Frontpanel for ELW2106AA with USB-C

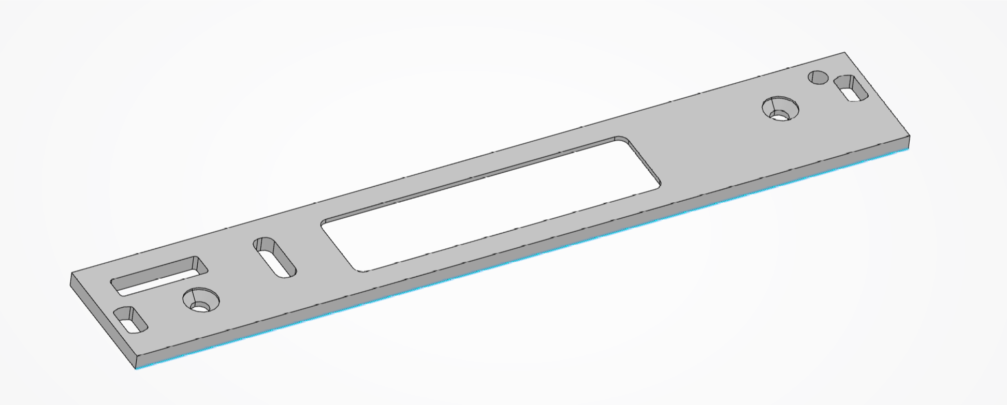
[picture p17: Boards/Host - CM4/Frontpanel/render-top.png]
Isometric view of frontpanel

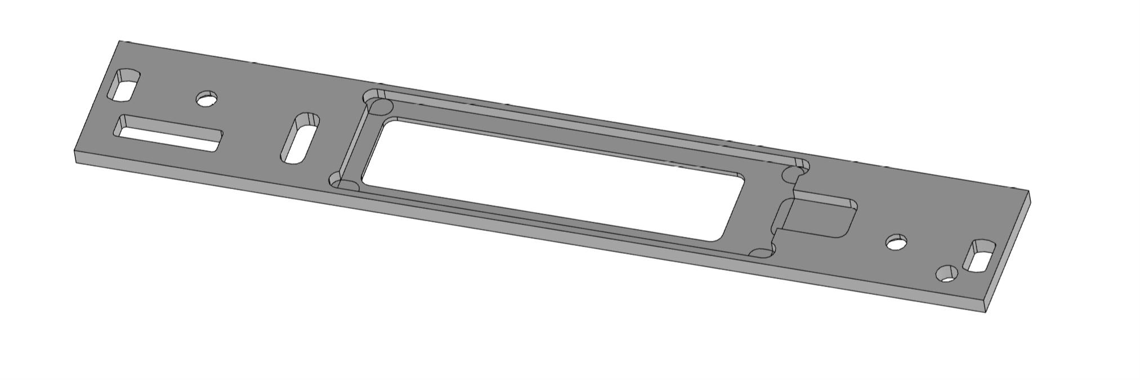
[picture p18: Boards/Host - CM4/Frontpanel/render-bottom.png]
Isometric view of frontpanel


LCD: [ELW2106AA](https://nl.mouser.com/datasheet/2/921/Futaba-04-14-2020-ELW2106AA_E_SHORT-1830779.pdf)
USB-C Connector: [Molex 2169890001](https://www.molex.com/molex/products/part-detail/io_connectors/2169890001) / [Kycon KUSBX-SL-CS1N14-B](http://www.kycon.com/Pub_Eng_Draw/KUSBX-SL-CS1N14-B.pdf)

Can be ordered through Front Panel Express, approx price 30 Euro

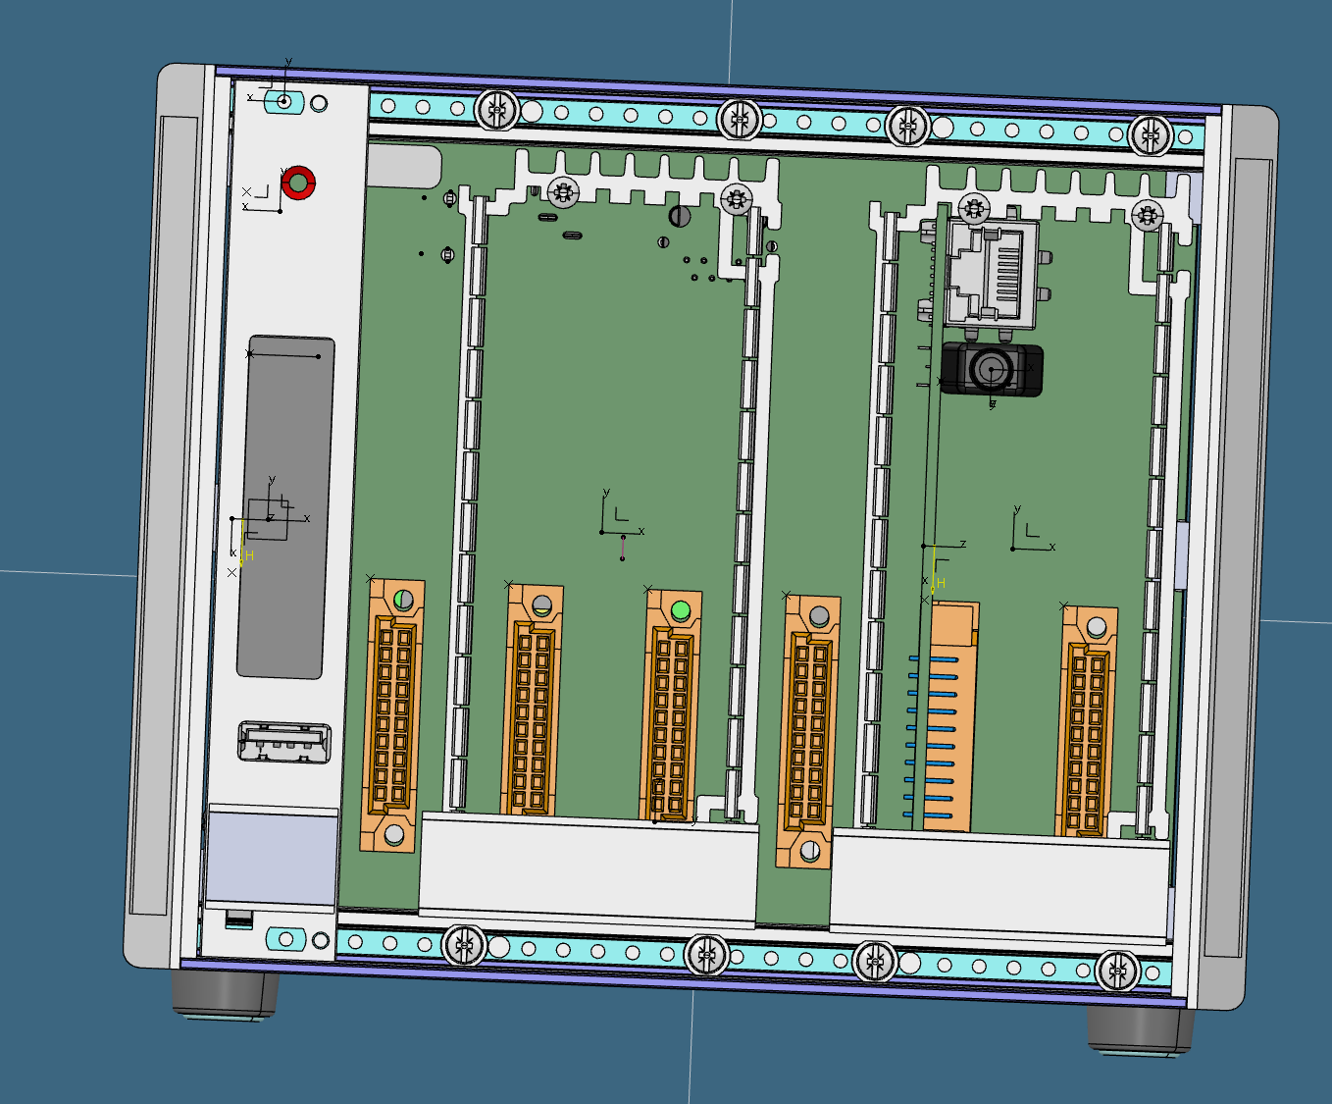
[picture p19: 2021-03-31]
Mechanical/Shielded Module 2s/Crappy Render.png

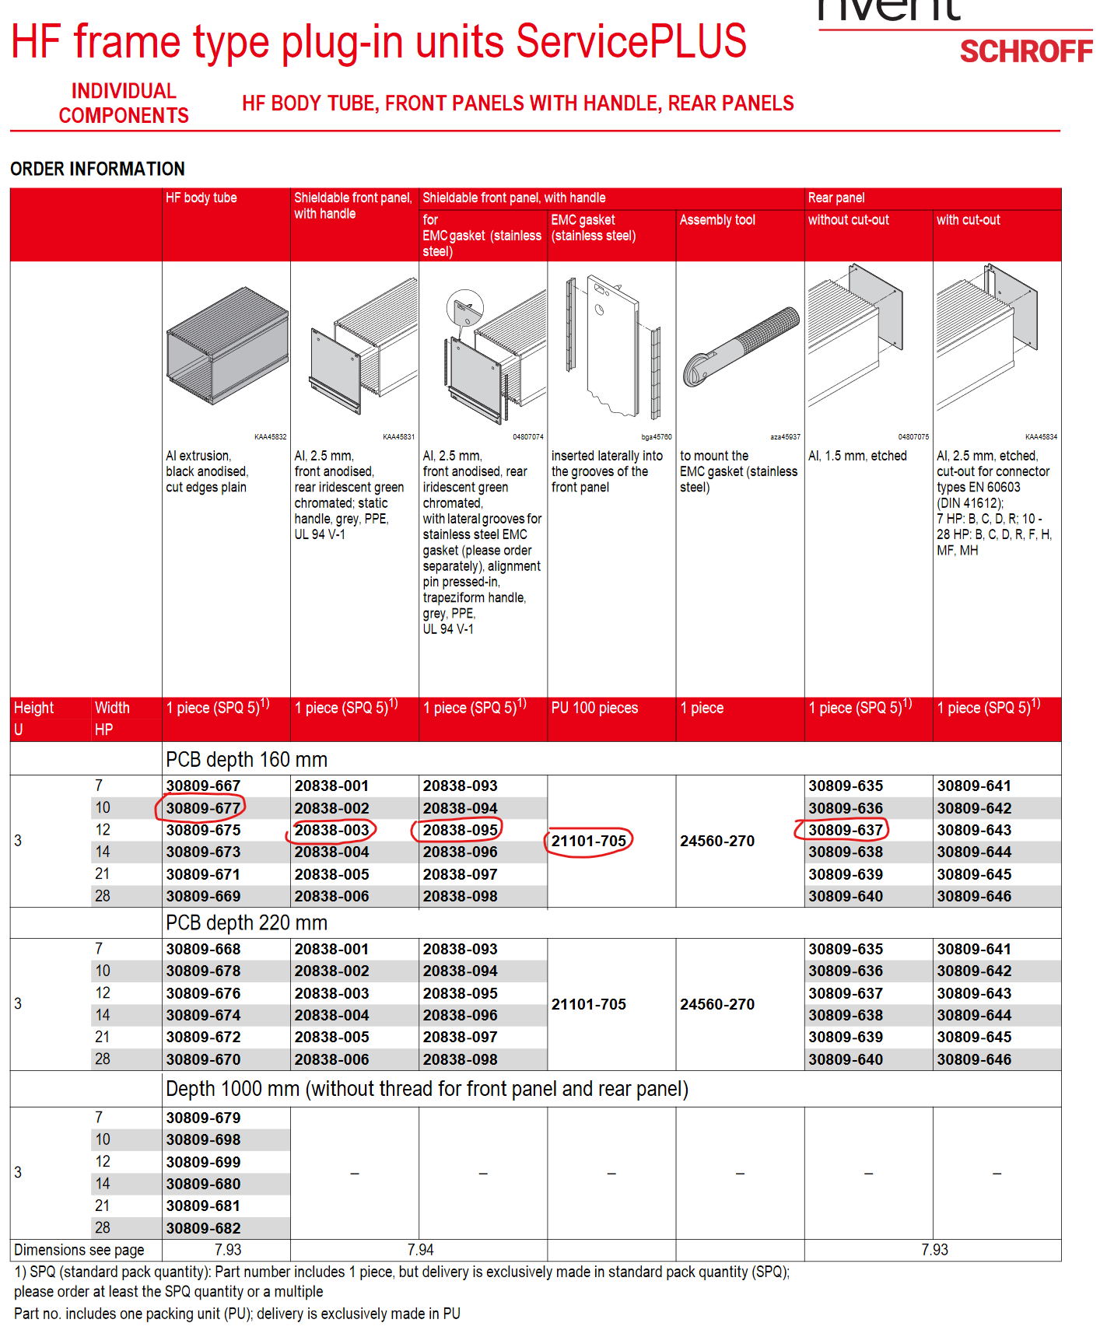
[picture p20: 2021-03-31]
Mechanical/Shielded Module 2s/Partnumbers.png

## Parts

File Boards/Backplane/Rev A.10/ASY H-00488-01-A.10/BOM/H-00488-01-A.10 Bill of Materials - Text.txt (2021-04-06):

Line #	Quantity	Designator	Name	Description	Manufacturer Part Number 1	Manufacturer 1

"204"	"99"	"C100, C101, C102, C103, C104, C105, C106, C107, C108, C109, C110, C111, C112, C113, C114, C115, C116, C117, C118, C119, C120, C121, C122, C123, C124, C125, C126, C127, C128, C129, C130, C131, C132, C135_1, C135_2, C135_3, C135_4, C135_5, C135_6, C135_7, C136_1, C136_2, C136_3, C136_4, C136_5, C136_6, C136_7, C137_1, C137_2, C137_3, C137_4, C137_5, C137_6, C137_7, C138_1, C138_2, C138_3, C138_4, C138_5, C138_6, C138_7, C139_1, C139_2, C139_3, C139_4, C139_5, C139_6, C139_7, C140_1, C140_2, C140_3, C140_4, C140_5, C140_6, C140_7, C141_1, C141_2, C141_3, C141_4, C141_5, C141_6, C141_7, C143, C144, C146, C149, C150, C151, C152, C153, C154, C157, C158, C159, C160, C161, C172, C173, C174"	"C0402C104K8RACTU"	"CAP Standard 0402 (1005) 100,0nF 10V X7R (Standard)"	"C0402C104K8RACTU"	"KEMET"
""	"4"	"C133, C134, C155, C156"	"C0402C180J5GACTU"	"CAP Standard 0402 (1005) 18,0pF 50V C0G (Standard)"	"C0402C180J5GACTU"	"KEMET"
"202"	"4"	"C142, C145, C147, C148"	"C0402C105K4PACTU"	"CAP Standard 0402 (1005) 1,0uF 16V X5R (Standard)"	"C0402C105K4PACTU"	"KEMET"
"201"	"3"	"C162, C163, C164"	"C1210C106K5RACTU"	"CAP Standard 1210 (3225) 10,0uF 50V X7R (Standard)"	"C1210C106K5RACTU"	"KEMET"
""	"3"	"C165, C167, C169"	"C0402C223K5RACTU"	"CAP Standard 0402 (1005) 22,0nF 50V X7R (Standard)"	"C0402C223K5RACTU"	"KEMET"
"203"	"4"	"C166, C168, C170, C171"	"C1210C476M8RACTU"	"CAP Standard 1210 (3225) 47,0uF 10V X7R (Standard)"	"C1210C476M8RACTU"	"KEMET"
"301"	"16"	"D100, D101, D102, D103, D104, D105, D106, D119, D120, D121, D122, D123, D124, D125, D131, D132"	"SML-E12P8W"	"LED Green Diffused 0603 SMD"	"SML-E12P8WT86"	"Rohm"
"302"	"41"	"D107, D108, D109, D110, D111_1, D111_2, D111_3, D111_4, D111_5, D111_6, D111_7, D112_1, D112_2, D112_3, D112_4, D112_5, D112_6, D112_7, D113_1, D113_2, D113_3, D113_4, D113_5, D113_6, D113_7, D114_1, D114_2, D114_3, D114_4, D114_5, D114_6, D114_7, D115, D116, D117, D118, D126, D127, D128, D129, D130"	"USBLC6-2P6"	"TVS DIODE 5.25VWM 17VC SOT666"	"USBLC6-2P6"	"STMicroelectronics"
"806"	"8"	"J103_1, J103_2, J103_3, J103_4, J103_5, J103_6, J103_7, J107"	"09242206824"	"Board Euro Connector"	"09242206824"	"HARTING Technology"
"802"	"1"	"J108"	"74990101241"	"Datacom Transformer"	"74990101241"	"Wurth Electronics"
"801"	"1"	"J109"	"38700-7502"	"Barrier Strip Terminal Block, 1 Row(s), 1 Deck(s)"	"38700-7502"	"Molex"
"803"	"1"	"J110"	"PJ-090BH"	"Circular DC Power Connector"	"PJ-090BH"	"CUI"
"401"	"3"	"L100, L101, L102"	"BLM18PG121SN1D"	"IND, Automotive, Chip Ferrite Bead, Power Lines, 0603, 120R, 2A"	"BLM18PG121SN1D"	"Murata"
"100"	"1"	"MP100"	"LABEL-190x65"	"Label Placeholder 0.75" x 0.25" (Zebra 10015764)"	""	""
"100"	"1"	"PCB100"	"TITLE-BLOCK"	"Title Block and PCB BOM Line Item"	""	""
"601"	"19"	"Q100_1, Q100_2, Q100_3, Q100_4, Q100_5, Q100_6, Q100_7, Q101_1, Q101_2, Q101_3, Q101_4, Q101_5, Q101_6, Q101_7, Q102, Q103, Q104, Q105, Q106"	"BUK7D25-40EX"	"BUK7D25 Series 40V Surface-Mounted N-channel Trench MOSFET - SOT1118"	"BUK7D25-40EX"	"Nexperia"
""	"45"	"R100, R102, R104, R105, R106, R107, R108, R109, R110, R111, R115, R116, R117, R118, R119, R120, R121, R122, R123, R124, R125, R126, R127, R128, R129, R144_1, R144_2, R144_3, R144_4, R144_5, R144_6, R144_7, R147, R148, R149, R152, R153, R158, R159, R171, R172, R179, R180, R191, R192"	"CRCW04021K20FKED"	"RES Standard Thick Film 0402 1K20 ±1% 0,063W"	"CRCW04021K20FKED"	"Vishay"
""	"10"	"R101, R143_1, R143_2, R143_3, R143_4, R143_5, R143_6, R143_7, R177, R193"	"CRCW040220K0FKED"	"RES Standard Thick Film 0402 20K0 ±1% 0,063W"	"CRCW040220K0FKED"	"Vishay"
"104"	"28"	"R112, R113, R114, R140_1, R140_2, R140_3, R140_4, R140_5, R140_6, R140_7, R150, R155, R156, R157, R160, R161, R169, R170, R181, R182, R186, R189, R194, R195, R196, R198, R199, R201"	"CRCW040210K0FKED"	"RES Standard Thick Film 0402 10K0 ±1% 0,063W"	"CRCW040210K0FKED"	"Vishay"
"102"	"2"	"R130, R165"	"CRCW04021M00FKED"	"RES Standard Thick Film 0402 1M00 ±1% 0,063W"	"CRCW04021M00FKED"	"Vishay"
"103"	"1"	"R134"	"CRCW04023K00FKED"	"RES Standard Thick Film 0402 3K00 ±1% 0,063W"	"CRCW04023K00FKED"	"Vishay"
"106"	"38"	"R135_1, R135_2, R135_3, R135_4, R135_5, R135_6, R135_7, R136_1, R136_2, R136_3, R136_4, R136_5, R136_6, R136_7, R137_1, R137_2, R137_3, R137_4, R137_5, R137_6, R137_7, R138_1, R138_2, R138_3, R138_4, R138_5, R138_6, R138_7, R145_1, R145_2, R145_3, R145_4, R145_5, R145_6, R145_7, R178, R183, R185"	"CRCW040247R0FKED"	"RES Standard Thick Film 0402 47R0 ±1% 0,063W"	"CRCW040247R0FKED"	"Vishay"
"109"	"14"	"R139_1, R139_2, R139_3, R139_4, R139_5, R139_6, R139_7, R142_1, R142_2, R142_3, R142_4, R142_5, R142_6, R142_7"	"WSL0805R0250FEA18"	"RES Power Metal Strip 0805 0R025 ±1% 0,125W"	"WSL0805R0250FEA18"	"Vishay Dale"
""	"13"	"R141_1, R141_2, R141_3, R141_4, R141_5, R141_6, R141_7, R167, R168, R173, R174, R187, R190"	"CRCW04023K90FKED"	"RES Standard Thick Film 0402 3K90 ±1% 0,063W"	"CRCW04023K90FKED"	"Vishay"
"108"	"1"	"R146"	"CRCW04020000Z0ED"	"RES Standard Thick Film 0402 0R00 ±1% 0,063W"	"CRCW04020000Z0ED"	"Vishay"
"105"	"1"	"R166"	"CRCW040212K0FKED"	"RES Standard Thick Film 0402 12K0 ±1% 0,063W"	"CRCW040212K0FKED"	"Vishay"
"110"	"2"	"R175, R188"	"WSLP0805R0100FEA"	"RES Power Metal Strip 0805 0R01 ±1% 0,5W"	"WSLP0805R0100FEA"	"Vishay"
""	"1"	"R176"	"CRCW0402200KFKED"	"RES Standard Thick Film 0402 200K ±1% 0,063W"	"CRCW0402200KFKED"	"Vishay"
""	"3"	"R184, R197, R200"	"CRCW04022K20FKED"	"RES Standard Thick Film 0402 2K20 ±1% 0,063W"	"CRCW04022K20FKED"	"Vishay"
"701"	"1"	"U100"	"KSZ8999I"	"LAN Switching Circuit, PQFP208"	"KSZ8999I"	"Microchip"
"706"	"2"	"U101, U105"	"24AA025E64T-I/OT"	"EEPROM, 256X8, Serial, CMOS, PDSO5"	"24AA025E64T-I/OT"	"Microchip"
"711"	"8"	"U102_1, U102_2, U102_3, U102_4, U102_5, U102_6, U102_7, U109"	"LTC4222IUH#PBF"	"Power Supply Support Circuit, Adjustable, 2 Channel, CMOS, PQCC32"	"LTC4222IUH#PBF"	"Analog Devices / Linear Technology"
"704"	"8"	"U103_1, U103_2, U103_3, U103_4, U103_5, U103_6, U103_7, U116"	"SN74LVC1G125DCKR"	"Bus Driver, LVC/LCX/Z Series, 1-Func, 1-Bit, True Output, CMOS, PDSO5"	"SN74LVC1G125DCKR"	"Texas Instruments"
"705"	"1"	"U104"	"USB2517I-JZX"	"USB Bus Controller, CMOS"	"USB2517I-JZX"	"Microchip"
"707"	"2"	"U106, U107"	"FSUSB42MUX"	"IC USB SWITCH DPDT 10MSOP"	"FSUSB42MUX"	"ON Semiconductor / Fairchild"
"703"	"1"	"U108"	"TCA9548AMRGER"	"Multiplexer, 9548 Series, 1-Func, 1 Line Input, 8 Line Output, True Output, PQCC24"	"TCA9548AMRGER"	"Texas Instruments"
"709"	"3"	"U110, U112, U114"	"LM5050Q1MK-1/NOPB"	"Half Bridge Based MOSFET Driver, PDSO6"	"LM5050Q1MK-1/NOPB"	"Texas Instruments"
"708"	"2"	"U111, U113"	"TPSM84209RKHR"	"Switching Regulator, 2.5A, 923kHz Switching Freq-Max, PQCC9"	"TPSM84209RKHR"	"Texas Instruments"
""	"1"	"U115"	"LMZM33606RLXR"	"Switching Regulator, 6A, 2200kHz Switching Freq-Max, PQMA41"	"LMZM33606RLXR"	"Texas Instruments"
"712"	"1"	"U117"	"TLV7022DDFR"	"Micropower small size comparator (dual, open-drain output) 8-SOT-23-THIN -40 to 125"	"TLV7022DDFR"	"Texas Instruments"
""	"1"	"Y100"	"TSX-3225 25.0000MF10P-C0"	"Crystal 25MHz ±10ppm (Tol) ±10ppm (Stability) 18pF FUND 40Ohm 4-Pin SMD T/R"	"TSX-3225 25.0000MF10P-C0"	"Epson"
""	"1"	"Y101"	"TSX-322524.0000MF15X-AC3"	"Parallel - Fundamental Quartz Crystal, 24MHz Nom"	"TSX-322524.0000MF15X-AC3"	"Epson"

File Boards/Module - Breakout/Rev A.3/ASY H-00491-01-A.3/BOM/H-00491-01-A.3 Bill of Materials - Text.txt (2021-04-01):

Line #	Quantity	Designator	Name	Description	Manufacturer Part Number 1	Manufacturer 1

"106"	"4"	"C1, C2, C4, C5"	"C0805C474K5RACTU"	"CAP Standard 0805 (2012) 470,0nF 50V X7R (Standard)"	"C0805C474K5RACTU"	"KEMET"
"104"	"1"	"C3"	"C0603W102KDRACAUTO"	"CAP Automotive 0603 (1608) 1,0nF 1kV X7R (ArcShield with Flexible Termination)"	"C0603W102KDRACAUTO"	"KEMET"
"105"	"2"	"C10, C11"	"C0603C104K5RACTU"	"CAP Standard 0603 (1608) 100,0nF 50V X7R (Standard)"	"C0603C104K5RACTU"	"KEMET"
"113"	"2"	"D10, D11"	"SML-E12M8W"	"LED Yellowish green Diffused 0603 SMD"	"SML-E12M8WT86"	"Rohm"
"109"	"1"	"J10"	"67643-3910"	"USB Connector, 4 Contact(s), Female, Right Angle, Solder Terminal, Locking, Receptacle"	"67643-3910"	"Molex"
"108"	"1"	"J11"	"RJHSE5E80"	"Modular Connectors / Ethernet Connectors High Speed RJ w/no LEDs or Shield"	"RJHSE5E80"	"Amphenol Commercial"
"110"	"4"	"L1, L2, L3, L4"	"BLM21SP700SH1D"	"IND, Automotive, Chip Ferrite Bead, Power Lines, 0805, 70R, 6A"	"BLM21SP700SH1D"	"Murata"
"100"	"1"	"MH1"	"EUROCARD_160X100"	"Eurocard board outline 100x160mm"	""	""
"102"	"1"	"MP10"	"20817-443"	"SCHROFF         20817-443             MODULE, PLUG-IN, 3U, 4HP"	"20817-443"	"Pentair Schroff"
"101"	"1"	"MP11"	"5151094F"	"Optical Pipe"	"515-1094F"	"Dialight"
"107"	"1"	"P1"	"09241206921"	"Headers and Edge Type Connector"	"09241206921"	"HARTING Technology"
"103"	"1"	"PCB10"	"TITLE-BLOCK"	"Title Block and PCB BOM Line Item"	""	""
"114"	"1"	"R1"	"TNPW060310K0BEEA"	"RES High Stability Thin Film 0603 10K0 ±0.1% 0,1W"	"TNPW060310K0BEEA"	"Vishay Dale"
"115"	"4"	"R10, R11, R12, R13"	"CRCW06034K70FKEA"	"RES Standard Thick Film 0603 4K70 ±1% 0,1W"	"CRCW06034K70FKEA"	"Vishay"
"112"	"1"	"U10"	"MCP23008-E/SS"	"Parallel I/O Port, 8-Bit, 8 I/O, CMOS, PDSO20"	"MCP23008-E/SS"	"Microchip"
"111"	"1"	"U11"	"24AA025E64T-I/OT"	"EEPROM, 256X8, Serial, CMOS, PDSO5"	"24AA025E64T-I/OT"	"Microchip"

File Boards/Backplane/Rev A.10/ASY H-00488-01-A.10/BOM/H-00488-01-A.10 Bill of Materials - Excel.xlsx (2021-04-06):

Line # | Hiber Part Number | Quantity | Designator | Name | Description | Manufacturer 1 | Manufacturer Part Number 1 | Supplier 1 | Supplier Part Number 1
 |  | 1 | R176 | CRCW0402200KFKED | RES Standard Thick Film 0402 200K ±1% 0,063W | Vishay | CRCW0402200KFKED | Future Electronics | 3377678
 |  | 1 | U115 | LMZM33606RLXR | Switching Regulator, 6A, 2200kHz Switching Freq-Max, PQMA41 | Texas Instruments | LMZM33606RLXR | Arrow Electronics | LMZM33606RLXR
 |  | 1 | Y100 | TSX-3225 25.0000MF10P-C0 | Crystal 25MHz ±10ppm (Tol) ±10ppm (Stability) 18pF FUND 40Ohm 4-Pin SMD T/R | Epson | TSX-3225 25.0000MF10P-C0 | Digi-Key | SER4211DKR-ND
 |  | 1 | Y101 | TSX-322524.0000MF15X-AC3 | Parallel - Fundamental Quartz Crystal, 24MHz Nom | Epson | TSX-322524.0000MF15X-AC3 | Digi-Key | SER3635DKR-ND
 |  | 3 | C165, C167, C169 | C0402C223K5RACTU | CAP Standard 0402 (1005) 22,0nF 50V X7R (Standard) | KEMET | C0402C223K5RACTU | Avnet | 86K0563
 |  | 3 | R184, R197, R200 | CRCW04022K20FKED | RES Standard Thick Film 0402 2K20 ±1% 0,063W | Vishay | CRCW04022K20FKED | Arrow Electronics | CRCW04022K20FKED
 |  | 4 | C133, C134, C155, C156 | C0402C180J5GACTU | CAP Standard 0402 (1005) 18,0pF 50V C0G (Standard) | KEMET | C0402C180J5GACTU | Arrow Electronics | C0402C180J5GACTU
 |  | 10 | R101, R143_1, R143_2, R143_3, R143_4, R143_5, R143_6, R143_7, R177, R193 | CRCW040220K0FKED | RES Standard Thick Film 0402 20K0 ±1% 0,063W | Vishay | CRCW040220K0FKED | Avnet | 52K6818
 |  | 13 | R141_1, R141_2, R141_3, R141_4, R141_5, R141_6, R141_7, R167, R168, R173, R174, R187, R190 | CRCW04023K90FKED | RES Standard Thick Film 0402 3K90 ±1% 0,063W | Vishay | CRCW04023K90FKED | Digi-Key | 541-3.90KLDKR-ND
 |  | 45 | R100, R102, R104, R105, R106, R107, R108, R109, R110, R111, R115, R116, R117, R118, R119, R120, R121, R122, R123, R124, R125, R126, R127, R128, R129, R144_1, R144_2, R144_3, R144_4, R144_5, R144_6, R144_7, R147, R148, R149, R152, R153, R158, R159, R171, R172, R179, R180, R191, R192 | CRCW04021K20FKED | RES Standard Thick Film 0402 1K20 ±1% 0,063W | Vishay | CRCW04021K20FKED | Newark | 89M6589
100 |  | 1 | MP100 | LABEL-190x65 | Label Placeholder 0.75" x 0.25" (Zebra 10015764)
100 |  | 1 | PCB100 | TITLE-BLOCK | Title Block and PCB BOM Line Item
102 |  | 2 | R130, R165 | CRCW04021M00FKED | RES Standard Thick Film 0402 1M00 ±1% 0,063W | Vishay | CRCW04021M00FKED | Future Electronics | 1032901
103 |  | 1 | R134 | CRCW04023K00FKED | RES Standard Thick Film 0402 3K00 ±1% 0,063W | Vishay | CRCW04023K00FKED | Newark | 52K6934
104 |  | 28 | R112, R113, R114, R140_1, R140_2, R140_3, R140_4, R140_5, R140_6, R140_7, R150, R155, R156, R157, R160, R161, R169, R170, R181, R182, R186, R189, R194, R195, R196, R198, R199, R201 | CRCW040210K0FKED | RES Standard Thick Film 0402 10K0 ±1% 0,063W | Vishay | CRCW040210K0FKED | Digi-Key | 541-10.0KLCT-ND
105 |  | 1 | R166 | CRCW040212K0FKED | RES Standard Thick Film 0402 12K0 ±1% 0,063W | Vishay | CRCW040212K0FKED | Newark | 52K6646
106 |  | 38 | R135_1, R135_2, R135_3, R135_4, R135_5, R135_6, R135_7, R136_1, R136_2, R136_3, R136_4, R136_5, R136_6, R136_7, R137_1, R137_2, R137_3, R137_4, R137_5, R137_6, R137_7, R138_1, R138_2, R138_3, R138_4, R138_5, R138_6, R138_7, R145_1, R145_2, R145_3, R145_4, R145_5, R145_6, R145_7, R178, R183, R185 | CRCW040247R0FKED | RES Standard Thick Film 0402 47R0 ±1% 0,063W | Vishay | CRCW040247R0FKED | Newark | 72M6794
108 |  | 1 | R146 | CRCW04020000Z0ED | RES Standard Thick Film 0402 0R00 ±1% 0,063W | Vishay | CRCW04020000Z0ED | Future Electronics | 1095116
109 |  | 14 | R139_1, R139_2, R139_3, R139_4, R139_5, R139_6, R139_7, R142_1, R142_2, R142_3, R142_4, R142_5, R142_6, R142_7 | WSL0805R0250FEA18 | RES Power Metal Strip 0805 0R025 ±1% 0,125W | Vishay Dale | WSL0805R0250FEA18 | RSComponents | 6836066P
110 |  | 2 | R175, R188 | WSLP0805R0100FEA | RES Power Metal Strip 0805 0R01 ±1% 0,5W | Vishay | WSLP0805R0100FEA
201 |  | 3 | C162, C163, C164 | C1210C106K5RACTU | CAP Standard 1210 (3225) 10,0uF 50V X7R (Standard) | KEMET | C1210C106K5RACTU | Mouser | 80-C1210C106K5R
202 |  | 4 | C142, C145, C147, C148 | C0402C105K4PACTU | CAP Standard 0402 (1005) 1,0uF 16V X5R (Standard) | KEMET | C0402C105K4PACTU | Mouser | 80-C0402C105K4P
203 |  | 4 | C166, C168, C170, C171 | C1210C476M8RACTU | CAP Standard 1210 (3225) 47,0uF 10V X7R (Standard) | KEMET | C1210C476M8RACTU | Allied Electronics | 70747455
204 |  | 99 | C100, C101, C102, C103, C104, C105, C106, C107, C108, C109, C110, C111, C112, C113, C114, C115, C116, C117, C118, C119, C120, C121, C122, C123, C124, C125, C126, C127, C128, C129, C130, C131, C132, C135_1, C135_2, C135_3, C135_4, C135_5, C135_6, C135_7, C136_1, C136_2, C136_3, C136_4, C136_5, C136_6, C136_7, C137_1, C137_2, C137_3, C137_4, C137_5, C137_6, C137_7, C138_1, C138_2, C138_3, C138_4, C138_5, C138_6, C138_7, C139_1, C139_2, C139_3, C139_4, C139_5, C139_6, C139_7, C140_1, C140_2, C140_3, C140_4, C140_5, C140_6, C140_7, C141_1, C141_2, C141_3, C141_4, C141_5, C141_6, C141_7, C143, C144, C146, C149, C150, C151, C152, C153, C154, C157, C158, C159, C160, C161, C172, C173, C174 | C0402C104K8RACTU | CAP Standard 0402 (1005) 100,0nF 10V X7R (Standard) | KEMET | C0402C104K8RACTU | Newark | 14N2167
301 |  | 16 | D100, D101, D102, D103, D104, D105, D106, D119, D120, D121, D122, D123, D124, D125, D131, D132 | SML-E12P8W | LED Green Diffused 0603 SMD | Rohm | SML-E12P8WT86 | Newark | 18AC7716
302 |  | 41 | D107, D108, D109, D110, D111_1, D111_2, D111_3, D111_4, D111_5, D111_6, D111_7, D112_1, D112_2, D112_3, D112_4, D112_5, D112_6, D112_7, D113_1, D113_2, D113_3, D113_4, D113_5, D113_6, D113_7, D114_1, D114_2, D114_3, D114_4, D114_5, D114_6, D114_7, D115, D116, D117, D118, D126, D127, D128, D129, D130 | USBLC6-2P6 | TVS DIODE 5.25VWM 17VC SOT666 | STMicroelectronics | USBLC6-2P6 | Mouser | 511-USBLC6-2P6
401 |  | 3 | L100, L101, L102 | BLM18PG121SN1D | IND, Automotive, Chip Ferrite Bead, Power Lines, 0603, 120R, 2A | Murata | BLM18PG121SN1D | Future Electronics | 4072850
601 |  | 19 | Q100_1, Q100_2, Q100_3, Q100_4, Q100_5, Q100_6, Q100_7, Q101_1, Q101_2, Q101_3, Q101_4, Q101_5, Q101_6, Q101_7, Q102, Q103, Q104, Q105, Q106 | BUK7D25-40EX | BUK7D25 Series 40V Surface-Mounted N-channel Trench MOSFET - SOT1118 | Nexperia | BUK7D25-40EX | Arrow Electronics | BUK7D25-40EX
701 |  | 1 | U100 | KSZ8999I | LAN Switching Circuit, PQFP208 | Microchip | KSZ8999I | Arrow Electronics | KSZ8999I
703 |  | 1 | U108 | TCA9548AMRGER | Multiplexer, 9548 Series, 1-Func, 1 Line Input, 8 Line Output, True Output, PQCC24 | Texas Instruments | TCA9548AMRGER | Arrow Electronics | TCA9548AMRGER
704 |  | 8 | U103_1, U103_2, U103_3, U103_4, U103_5, U103_6, U103_7, U116 | SN74LVC1G125DCKR | Bus Driver, LVC/LCX/Z Series, 1-Func, 1-Bit, True Output, CMOS, PDSO5 | Texas Instruments | SN74LVC1G125DCKR | Newark | 76C4082
705 |  | 1 | U104 | USB2517I-JZX | USB Bus Controller, CMOS | Microchip | USB2517I-JZX | RSComponents | 7729474
706 |  | 2 | U101, U105 | 24AA025E64T-I/OT | EEPROM, 256X8, Serial, CMOS, PDSO5 | Microchip | 24AA025E64T-I/OT | Avnet | 99W1951
707 |  | 2 | U106, U107 | FSUSB42MUX | IC USB SWITCH DPDT 10MSOP | ON Semiconductor / Fairchild | FSUSB42MUX | Arrow Electronics | FSUSB42MUX
708 |  | 2 | U111, U113 | TPSM84209RKHR | Switching Regulator, 2.5A, 923kHz Switching Freq-Max, PQCC9 | Texas Instruments | TPSM84209RKHR | Mouser | 595-TPSM84209RKHR
709 |  | 3 | U110, U112, U114 | LM5050Q1MK-1/NOPB | Half Bridge Based MOSFET Driver, PDSO6 | Texas Instruments | LM5050Q1MK-1/NOPB | Digi-Key | 296-40232-6-ND
711 |  | 8 | U102_1, U102_2, U102_3, U102_4, U102_5, U102_6, U102_7, U109 | LTC4222IUH#PBF | Power Supply Support Circuit, Adjustable, 2 Channel, CMOS, PQCC32 | Analog Devices / Linear Technology | LTC4222IUH#PBF | Digi-Key | LTC4222IUH#PBF-ND
712 |  | 1 | U117 | TLV7022DDFR | Micropower small size comparator (dual, open-drain output) 8-SOT-23-THIN -40 to 125 | Texas Instruments | TLV7022DDFR
801 |  | 1 | J109 | 38700-7502 | Barrier Strip Terminal Block, 1 Row(s), 1 Deck(s) | Molex | 38700-7502 | Newark | 01AH1076
802 |  | 1 | J108 | 74990101241 | Datacom Transformer | Wurth Electronics | 74990101241 | Digi-Key | 732-10834-ND
803 |  | 1 | J110 | PJ-090BH | Circular DC Power Connector | CUI | PJ-090BH | Arrow Electronics | PJ-090BH
806 |  | 8 | J103_1, J103_2, J103_3, J103_4, J103_5, J103_6, J103_7, J107 | 09242206824 | Board Euro Connector | HARTING Technology | 09242206824 | Mouser | 617-09-24-220-6824

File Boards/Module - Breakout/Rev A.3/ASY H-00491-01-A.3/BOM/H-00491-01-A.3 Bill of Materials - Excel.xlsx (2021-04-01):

Line # | Hiber Part Number | Quantity | Designator | Name | Description | Manufacturer 1 | Manufacturer Part Number 1 | Supplier 1 | Supplier Part Number 1
100 |  | 1 | MH1 | EUROCARD_160X100 | Eurocard board outline 100x160mm
101 |  | 1 | MP11 | 5151094F | Optical Pipe | Dialight | 515-1094F | Future Electronics | 9415605
102 |  | 1 | MP10 | 20817-443 | SCHROFF 20817-443 MODULE, PLUG-IN, 3U, 4HP | Pentair Schroff | 20817-443 | Digi-Key | 1439-1052-ND
103 |  | 1 | PCB10 | TITLE-BLOCK | Title Block and PCB BOM Line Item
104 |  | 1 | C3 | C0603W102KDRACAUTO | CAP Automotive 0603 (1608) 1,0nF 1kV X7R (ArcShield with Flexible Termination) | KEMET | C0603W102KDRACAUTO | Mouser | 80-C0603W102KDRAUTO
105 |  | 2 | C10, C11 | C0603C104K5RACTU | CAP Standard 0603 (1608) 100,0nF 50V X7R (Standard) | KEMET | C0603C104K5RACTU | Digi-Key | 399-5089-6-ND
106 |  | 4 | C1, C2, C4, C5 | C0805C474K5RACTU | CAP Standard 0805 (2012) 470,0nF 50V X7R (Standard) | KEMET | C0805C474K5RACTU | Allied Electronics | 70095622
107 |  | 1 | P1 | 09241206921 | Headers and Edge Type Connector | HARTING Technology | 09241206921 | Arrow Electronics | 09241206921
108 |  | 1 | J11 | RJHSE5E80 | Modular Connectors / Ethernet Connectors High Speed RJ w/no LEDs or Shield | Amphenol Commercial | RJHSE5E80 | Digi-Key | RJHSE5E80-ND
109 |  | 1 | J10 | 67643-3910 | USB Connector, 4 Contact(s), Female, Right Angle, Solder Terminal, Locking, Receptacle | Molex | 67643-3910 | Arrow Electronics | 67643-3910
110 |  | 4 | L1, L2, L3, L4 | BLM21SP700SH1D | IND, Automotive, Chip Ferrite Bead, Power Lines, 0805, 70R, 6A | Murata | BLM21SP700SH1D | Arrow Electronics | BLM21SP700SH1D
111 |  | 1 | U11 | 24AA025E64T-I/OT | EEPROM, 256X8, Serial, CMOS, PDSO5 | Microchip | 24AA025E64T-I/OT | Avnet | 99W1951
112 |  | 1 | U10 | MCP23008-E/SS | Parallel I/O Port, 8-Bit, 8 I/O, CMOS, PDSO20 | Microchip | MCP23008-E/SS | Arrow Electronics | MCP23008-E/SS
113 |  | 2 | D10, D11 | SML-E12M8W | LED Yellowish green Diffused 0603 SMD | Rohm | SML-E12M8WT86 | Digi-Key | 511-1584-1-ND
114 |  | 1 | R1 | TNPW060310K0BEEA | RES High Stability Thin Film 0603 10K0 ±0.1% 0,1W | Vishay Dale | TNPW060310K0BEEA | Future Electronics | 1060209
115 |  | 4 | R10, R11, R12, R13 | CRCW06034K70FKEA | RES Standard Thick Film 0603 4K70 ±1% 0,1W | Vishay | CRCW06034K70FKEA | Mouser | 71-CRCW0603-4.7K-E3

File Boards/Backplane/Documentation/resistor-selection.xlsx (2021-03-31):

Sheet: Sheet1 (2)
 |  |  |  |  |  | Nominal | 24 | V
x | c | R3 | 3400 | Ohm
y | b | R2 | 33272.48908 | Ohm |  | R3 | 14.7 | K
z | a | R1 | 750 | Ohm |  | Vref | 1.235 | V | 1145
 |  |  |  |  |  | UVTH(RISING) | 1.235 | V
 |  |  |  |  |  | OVTH(FALLING) | 1.145 | V
 |  |  |  |  |  | VOV(OFF) | 11.000 | V
 |  |  |  |  |  | VOV(ON) | 12.000 | V | ??
 |  |  |  |  |  | R2 | 0.17
 |  |  |  | VFB(RISING) | 1.235 V
 |  |  |  | VFB(FALLING) | 1.145 V
 |  |  |  | R1 | 140.00 K |  | 200.00 K
 |  |  |  | R2 | 3.32 K |  | 1.20 K
 |  |  |  | R3 | 14.70 K |  | 10.00 K
 |  |  |  | VOV(ON) | 13.28 V |  | 26.08 V
 |  |  |  | VOV(OFF) | 12.31 V |  | 24.18 V
 |  |  |  | VUV(OFF) | 10.83 V | 1.48 | 23.29 V | 0.89
 |  |  |  | VUV(ON) | 10.04 V |  | 21.59 V
 |  |  |  | Vin | 12.000 V
 |  |  |  | UV | 1.368 V | 1
 |  |  |  | OV | 1.116 V | 0
 |  |  |  |  |  |  |  | 2.2
 |  |  |  |  |  |  |  | 3.9
 |  |  |  |  |  |  |  | 1.2
 |  |  |  |  |  |  |  | 10
 |  |  |  |  |  |  |  | 3
 |  |  |  |  |  |  |  | 12
 |  |  |  |  |  |  |  | 20

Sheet: Sheet1
 |  |  |  |  |  | Nominal | 24 | V
x | c | R3 | 3400 | Ohm
y | b | R2 | 33272.48908 | Ohm |  | R3 | 14.7 | K
z | a | R1 | 750 | Ohm |  | Vref | 1.235 | V | 1145
 |  |  |  |  |  | UVTH(RISING) | 1.235 | V
 |  |  |  |  |  | OVTH(FALLING) | 1.145 | V
 |  |  |  |  |  | VOV(OFF) | 11.000 | V
 |  |  |  |  |  | VOV(ON) | 12.000 | V | ??
 |  |  |  |  |  | R2 | 0.17
 |  |  |  | Vin | 11 |  |  | 24 |  | 26 |  | 22
 |  |  |  | R1 | 140 |  |  | 200 |  | 200 |  | 200
 |  |  |  | R2 | 3.32 |  |  | 3 |  | 3 |  | 3
 |  |  |  | R3 | 14.7 |  |  | 12 |  | 12 |  | 12
 |  |  |  | UV | 1.254398177 | 1 |  | 1.674418605 | 0 | 1.813953488 | 0 | 1.534883721 | 0
 |  |  |  | OV | 1.023288191 | 0 |  | 1.339534884 | 0 | 1.451162791 | 0 | 1.227906977 | 0
 |  |  |  |  |  |  |  | 2.2
 |  |  |  |  |  |  |  | 3.9
 |  |  |  |  |  |  |  | 1.2
 |  |  |  |  |  |  |  | 10
 |  |  |  |  |  |  |  | 3
 |  |  |  |  |  |  |  | 12
 |  |  |  |  |  |  |  | 20

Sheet: Sheet3
R7 | 20 | K
R8 | 1.2 | K
FBTH(RISING) | 1.235 | V | CONFIG, EN, FB, ON, OV and UV Input Threshold
VPWERGD(UP) | 21.81833333 | V
Target | 23 | V | 2.2 | Buck FB
 |  |  | 3.9 | Buck FB
R7 | 10 | K | 1.2 | PGOOD FB + Generic pull
R8 | 3.9 | K | 10
FBTH(RISING) | 1.235 | V | 3 | Ethernet switch ISET
VPWERGD(UP) | 4.401666667 | V | 12 | USB RBIias
Target | 4.7 | V | 20 | 5V FB (2x)
From Example 12V?????
R7 | 10.2 | K
R8 | 3.57 | K
FBTH(RISING) | 1.235 | V
VPWERGD(UP) | 4.763571429 | V
From Example 3.3V?????
R7 | 4.99 | K
R8 | 3.57 | K
FBTH(RISING) | 1.235 | V
VPWERGD(UP) | 2.961232493 | V
Vin | 5 | V
Rtop | 10
Rbot | 2.2
Vout | 0.9016393443

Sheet: Sheet1 (3)
VPWRGD(UP) = 11.6V
 | FBth | 1.255 |  | FBth | 1.255 |  | FBth | 1.255
 | Vpwrgd | 11.6 | V | Vpwrgd | 23.5 | V | Vpwrgd | 4.45 | V
 | R8 | 3.57 | K | R8 | 3 | K | R8 | 4.7 | K
 | R7 | 29.42760956 | K | R7 | 53.1752988 | K | R7 | 11.96533865 | K
 |  |  |  |  |  | Generic | 1K
 |  |  |  |  |  |  | 10K
 |  |  |  |  |  | Ethernet ISET | 3K
 |  |  |  |  |  | USB ISET | 12K
 |  |  |  |  |  | ID Comperator

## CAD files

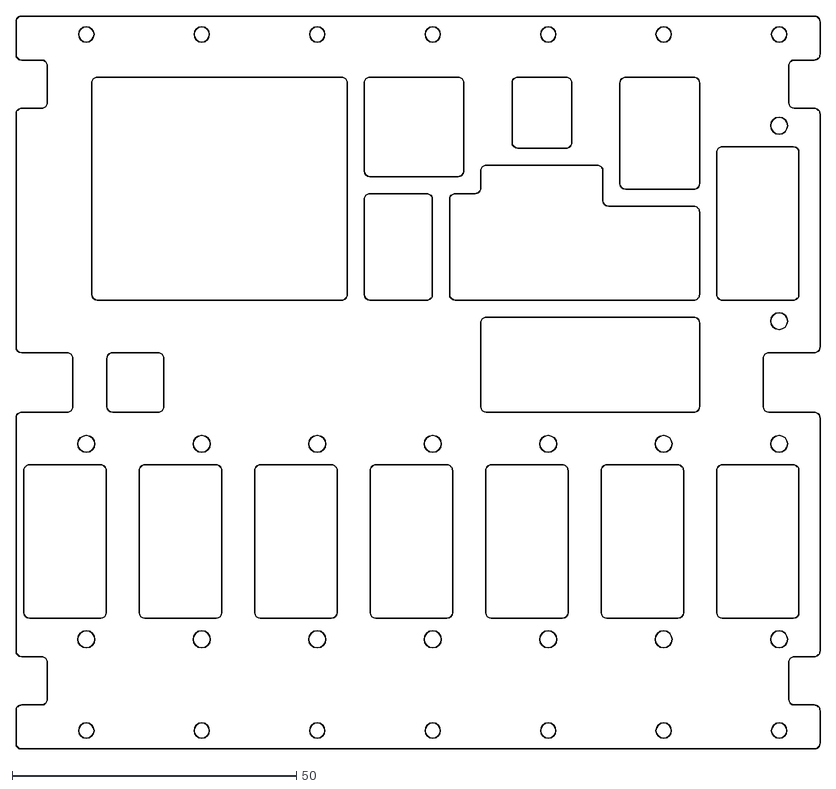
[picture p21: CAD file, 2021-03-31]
Boards/Backplane/Cover/spacer.dxf
141.5 x 129.0

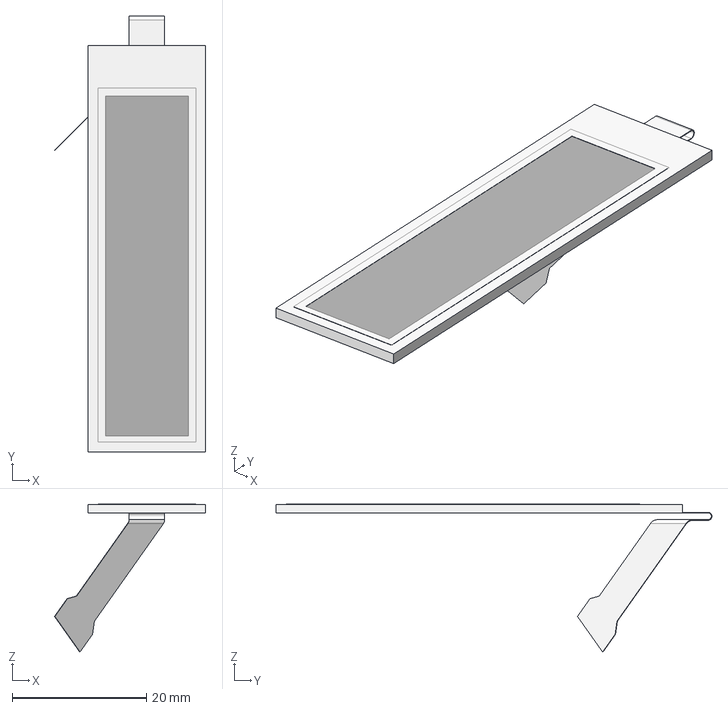
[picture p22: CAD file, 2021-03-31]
Boards/Host - CM4/ELW2106AA A.1.stp
22.5 x 65.0 x 22.1 mm

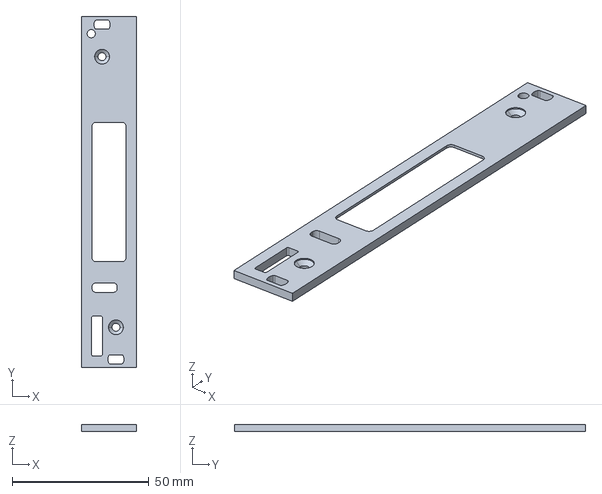
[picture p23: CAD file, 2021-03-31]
Boards/Host - CM4/Frontpanel/Front Panel ELW2106AA.stp
20.0 x 128.4 x 2.50 mm

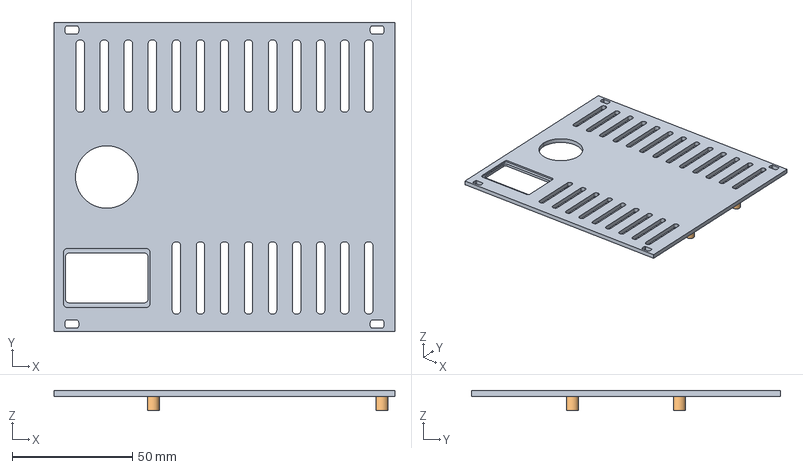
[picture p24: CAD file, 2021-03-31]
Mechanical/Benchtop 7s/Rear Panel/Rear Panel.stp
141.9 x 128.4 x 8.50 mm

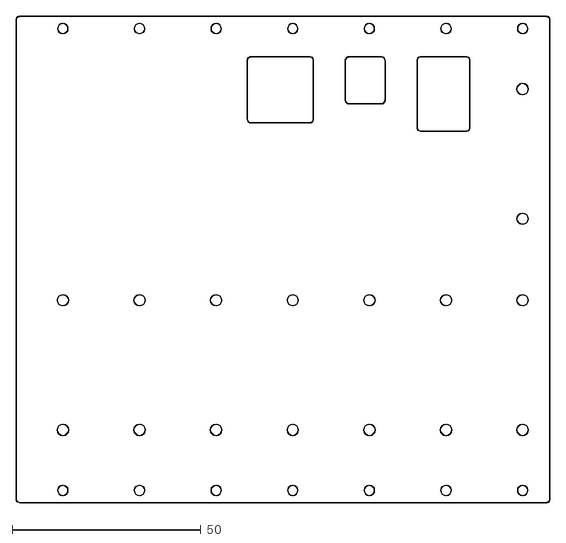
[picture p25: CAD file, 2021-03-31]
Boards/Backplane/Cover/cover.dxf
141.5 x 129.0

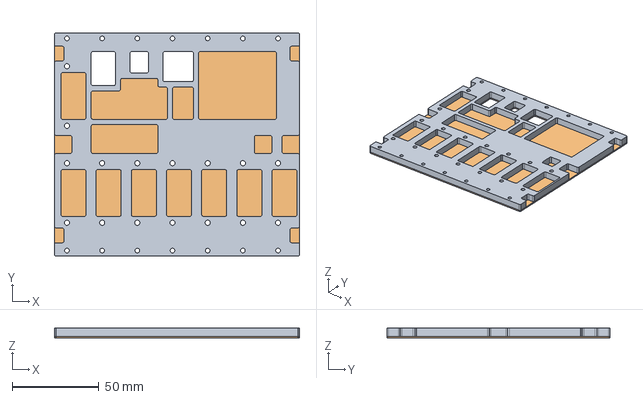
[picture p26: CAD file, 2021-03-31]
Boards/Backplane/Cover/cover-spacer.stp
141.5 x 129.0 x 6.00 mm

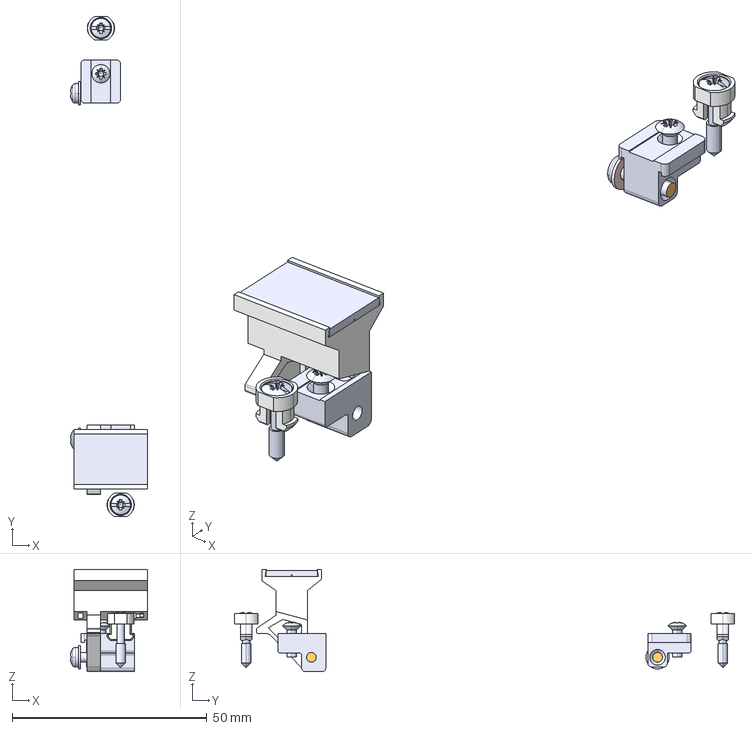
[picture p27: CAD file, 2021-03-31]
Boards/Module - Template/Front Pael/20817443 Hardware Only.stp
19.8 x 128.4 x 26.3 mm

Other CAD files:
Boards/Host - CM4/Frontpanel/Front Panel ELW2106AA.dxf
Mechanical/Benchtop 7s/Rear Panel/Rear Panel.dxf

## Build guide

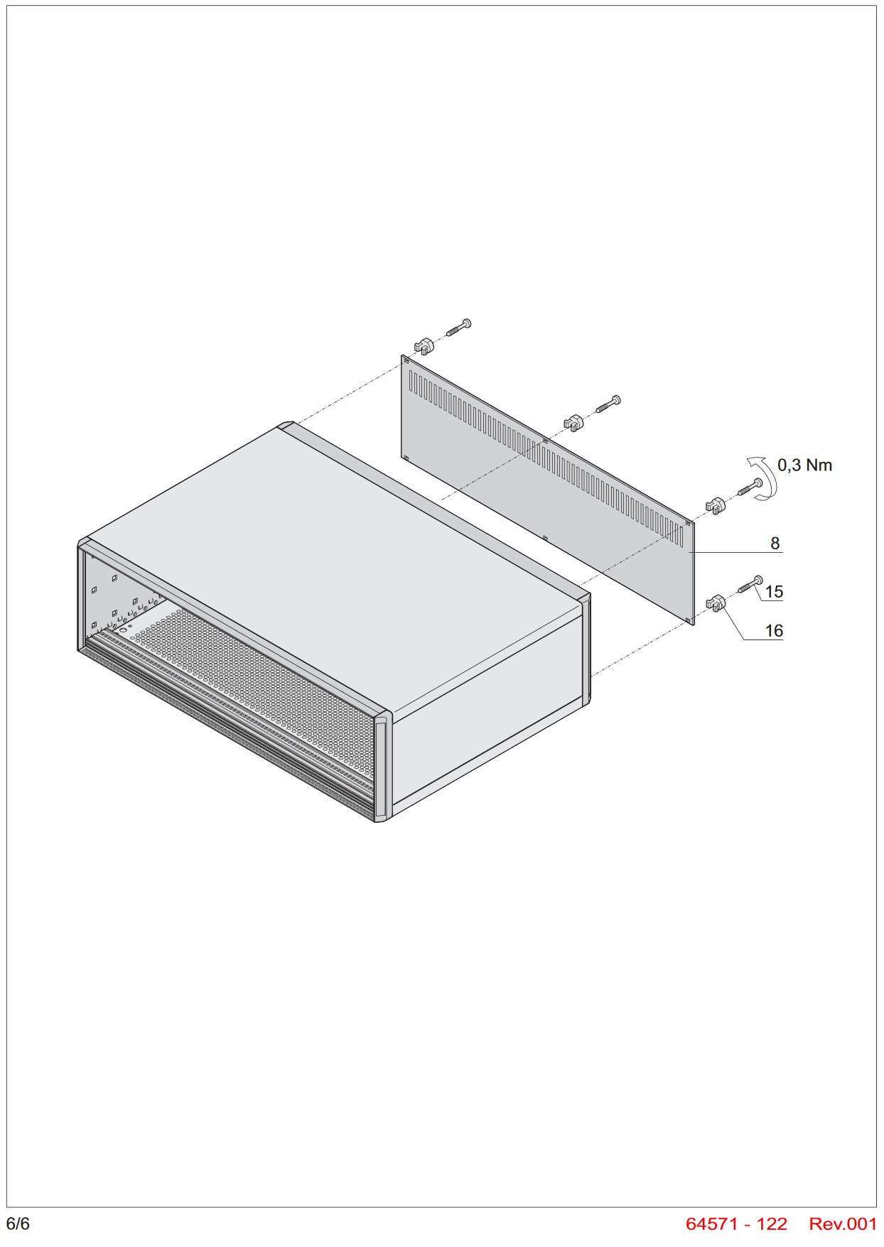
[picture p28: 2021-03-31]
Mechanical/Benchtop 7s/Documentation/schroff-manual-rear.png

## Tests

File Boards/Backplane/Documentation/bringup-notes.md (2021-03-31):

    Power up board
        Current draw 5ma @ 24V
        V_IN_24P0 is present
        No power on V_2P1, V_3P3, V_24P0, V_REG_5P0 
        Turned out LTC4222 creates power from VDD2 which is 5V
        5V not working, investigate
        5V buck 24V input not working because it is gated by LTC
        Hot wired primary 24V switch, board seems to board (with some parks), needs around 300mA for startup, needs design change :warning: 
        Current draw 100mA @ 24V
        Power rails seem stable. Pgood leds inverted? :warning: 
    Test USB Host
        Create USB host harness (make sure A3 is connected to ground)
        “USB device not recognized” - Device descriptor request failed
        V_USB_1P8 stable, V_USB_PLL_1P8 is 0V 
        Lifted EEPROM(U105) SDA/SCL pins
        RESET_N = 3.3V
        Compare schematic against evb2517sch.pdf
        Flipped D+/D-, now obviously works
        TODO: revert SCL/SDA? Depopulate on PCB? :warning: 
    Test LAN switch
        Plug in port 8 to laptop, no response
        Magjack led polarity reversed on footprint :warning: 
    Hot Swap Controllers
        INTVCC is ok
        Outputs are note enabled → enable was not connected
        All good
    Daisy chain
        Slots are too short :warning: 
        Middle slot is shifted :warning: 
        Add arrow master/slave silkscreen :warning: 
        For 3 boards 650ma is needed to power up, 300mA nominal
    Misc
        Add project name to silkscreen
        Airflow? Check heat on power supply etc
 
TODO:
- Create labels.....

Enable USB:
/boot/config.txt: add
dtoverlay=dwc2,dr_mode=host

https://pinout.xyz/pinout/i2c#
python example

pi@raspberrypi:~ $ lsusb
Bus 001 Device 004: ID 0424:2517 Standard Microsystems Corp. Hub
Bus 001 Device 003: ID 0424:2517 Standard Microsystems Corp. Hub
Bus 001 Device 002: ID 0424:2514 Standard Microsystems Corp. USB 2.0 Hub
Bus 001 Device 001: ID 1d6b:0002 Linux Foundation 2.0 root hub

i2cset -y 1 0x73 0x01
i2cset -y 1 0x72 0x01
i2cset -y 1 0x70 0x01

pi@raspberrypi:~ $ i2cdetect -y 1
     0  1  2  3  4  5  6  7  8  9  a  b  c  d  e  f
00:          -- -- -- -- -- -- -- -- -- -- -- -- --
10: -- -- -- -- -- -- -- -- -- -- -- -- -- -- -- --
20: -- -- -- -- -- -- -- -- -- -- -- -- -- -- -- --
30: -- -- -- -- -- -- -- -- -- -- -- -- -- -- -- --
40: -- -- -- -- 44 45 46 47 -- -- -- -- 4c 4d 4e 4f
50: -- -- -- -- 54 55 56 57 -- -- -- -- 5c 5d 5e 5f
60: -- -- -- 63 64 65 66 67 -- -- -- -- 6c 6d 6e 6f
70: 70 -- 72 73 -- -- -- --

Note: 0x63 = Call All LTC

----------
M0-- [44] X     21.594V      0.100A / X      5.094V      0.000A
M1-- [64] X     21.844V      0.000A / X      5.094V      0.000A
M2-- [54] X     21.844V      0.413A / X      5.031V      0.306A

S1-1 [45] -      0.000V      0.000A / -      0.000V      0.000A
S1-2 [46] -      0.000V      0.000A / -      0.000V      0.000A
S1-3 [47] -      0.000V      0.000A / -      0.000V      0.000A
S1-4 [4c] -      0.000V      0.000A / -      0.000V      0.000A
S1-5 [4d] -      0.000V      0.000A / -      0.000V      0.000A
S1-6 [4e] -      0.000V      0.000A / -      0.000V      0.000A
S1-7 [4f] -      0.000V      0.000A / -      0.000V      0.000A

S2-1 [65] -      0.000V      0.000A / -      0.000V      0.000A
S2-2 [66] -      0.000V      0.000A / -      0.000V      0.000A
S2-3 [67] -      0.000V      0.000A / -      0.000V      0.000A
S2-4 [6c] -      0.000V      0.000A / -      0.000V      0.000A
S2-5 [6d] X      5.062V      0.000A / X     21.781V      0.003A (Niels Radio test board)
S2-6 [6e] -      0.000V      0.000A / -      0.000V      0.000A
S2-7 [6f] -      0.000V      0.000A / -      0.000V      0.000A

S3-1 [55] -      0.000V      0.000A / -      0.000V      0.000A
S3-2 [56] -      0.000V      0.000A / -      0.000V      0.000A
S3-3 [57] -      0.000V      0.000A / -      0.000V      0.000A
S3-4 [5c] -      0.000V      0.000A / -      0.000V      0.000A
S3-5 [5d] -      0.000V      0.000A / -      0.000V      0.000A
S3-6 [5e] -      0.000V      0.000A / -      0.000V      0.000A
S3-7 [5f] X      5.031V      0.250A / X     21.844V      0.000A (PI)

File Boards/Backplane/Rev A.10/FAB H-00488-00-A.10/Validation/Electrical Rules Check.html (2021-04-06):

Altium

# Electrical Rule Check Report

Date: | | 1-2-2021
Time: | | 20:55:06
Filename: | | C:\Users\Joris\AppData\Local\TempReleases\Snapshot\1\Fabrication\Validation\Electrical Rules Check.html

Class | Document | Message
Error | H-00488 - Card Slot.SchDoc | Net NetNT125_2_1 has only one pin (Pin NT125-1)
Error | H-00488 - Card Slot.SchDoc | Net NetNT125_3_1 has only one pin (Pin NT125-1)
Error | H-00488 - Card Slot.SchDoc | Net NetNT126_1_1 has only one pin (Pin NT126-1)
Error | H-00488 - Card Slot.SchDoc | Net NetNT126_2_1 has only one pin (Pin NT126-1)
Error | H-00488 - Card Slot.SchDoc | Net NetNT126_6_1 has only one pin (Pin NT126-1)
Error | H-00488 - Ethernet Switch.SchDoc | Net NetU100_96 contains floating input pins (Pin U100-96)
Error | H-00488 - Ethernet Switch.SchDoc | Net NetU100_97 contains floating input pins (Pin U100-97)
Error | H-00488 - Ethernet Switch.SchDoc | Net NetU100_98 contains floating input pins (Pin U100-98)
Error | H-00488 - Ethernet Switch.SchDoc | Net NetU100_99 contains floating input pins (Pin U100-99)
Error | H-00488 - Ethernet Switch.SchDoc | Net NetU100_100 contains floating input pins (Pin U100-100)
Error | H-00488 - Ethernet Switch.SchDoc | Net NetU100_101 contains floating input pins (Pin U100-101)
Error | H-00488 - Power.SchDoc | Net NetU109_18 contains floating input pins (Pin U109-18)
Error | H-00488 - Power.SchDoc | Net NetU109_23 contains floating input pins (Pin U109-23)
Error | H-00488 - Power.SchDoc | Net NetU115_18 contains floating input pins (Pin U115-18)
Error | H-00488 - Power.SchDoc | Net PWR_EN_2P1 has only one pin (Pin U113-9)
Error | H-00488 - Power.SchDoc | Net PWR_EN_3P3 has only one pin (Pin U111-9)
Error | H-00488 - Power.SchDoc | Net PWR_LM_VCC has only one pin (Pin U115-9)
Error | H-00488 - Power.SchDoc | NetC162_2 contains Power Pin and Output Port objects (Pin U111-2, Pin U113-2, Port V_24P0).
Error | H-00488 - Power.SchDoc | NetC166_1 contains Power Pin and Output Port objects (Pin U111-3, Port V_3P3).
Error | H-00488 - Power.SchDoc | NetC168_1 contains Power Pin and Output Port objects (Pin U113-3, Port V_2P1).
Error | H-00488 - Card Slot.SchDoc | NetD111_1_5 contains Power Pin and Input Port objects (Pin U102-30, Port 5V).
Error | H-00488 - Card Slot.SchDoc | NetD111_2_5 contains Power Pin and Input Port objects (Pin U102-30, Port 5V).
Error | H-00488 - Card Slot.SchDoc | NetD111_3_5 contains Power Pin and Input Port objects (Pin U102-30, Port 5V).
Error | H-00488 - Card Slot.SchDoc | NetD111_4_5 contains Power Pin and Input Port objects (Pin U102-30, Port 5V).
Error | H-00488 - Card Slot.SchDoc | NetD111_5_5 contains Power Pin and Input Port objects (Pin U102-30, Port 5V).
Error | H-00488 - Card Slot.SchDoc | NetD111_6_5 contains Power Pin and Input Port objects (Pin U102-30, Port 5V).
Error | H-00488 - Card Slot.SchDoc | NetD111_7_5 contains Power Pin and Input Port objects (Pin U102-30, Port 5V).
Error | H-00488 - Connectors.SchDoc | NetJ110_1 contains Power Pin and Output Port objects (Pin J110-1, Port V_IN1_24P0).
Error | H-00488 - Card Slot.SchDoc | NetR142_1_2 contains Power Pin and Input Port objects (Pin U102-11, Port 24V).
Error | H-00488 - Card Slot.SchDoc | NetR142_2_2 contains Power Pin and Input Port objects (Pin U102-11, Port 24V).
Error | H-00488 - Card Slot.SchDoc | NetR142_3_2 contains Power Pin and Input Port objects (Pin U102-11, Port 24V).
Error | H-00488 - Card Slot.SchDoc | NetR142_4_2 contains Power Pin and Input Port objects (Pin U102-11, Port 24V).
Error | H-00488 - Card Slot.SchDoc | NetR142_5_2 contains Power Pin and Input Port objects (Pin U102-11, Port 24V).
Error | H-00488 - Card Slot.SchDoc | NetR142_6_2 contains Power Pin and Input Port objects (Pin U102-11, Port 24V).
Error | H-00488 - Card Slot.SchDoc | NetR142_7_2 contains Power Pin and Input Port objects (Pin U102-11, Port 24V).
Error | H-00488 - I2C Mux.SchDoc | V_3P3 contains Power Pin and Input Port objects (Pin U108-21, Port V_3P3).
Error | H-00488 - I2C Address.SchDoc | V_5P0 contains Power Pin and Input Port objects (Pin U117-8, Port V_5P0).
Error | H-00488 - Card Slot.SchDoc | V_INTVCC_3P3_1 contains Power Pin and Output Port objects (Pin U102-3, Pin U103-5, Port INTVCC).
Error | H-00488 - Card Slot.SchDoc | V_INTVCC_3P3_2 contains Power Pin and Output Port objects (Pin U102-3, Pin U103-5, Port INTVCC).
Error | H-00488 - Card Slot.SchDoc | V_INTVCC_3P3_3 contains Power Pin and Output Port objects (Pin U102-3, Pin U103-5, Port INTVCC).
Error | H-00488 - Card Slot.SchDoc | V_INTVCC_3P3_4 contains Power Pin and Output Port objects (Pin U102-3, Pin U103-5, Port INTVCC).
Error | H-00488 - Card Slot.SchDoc | V_INTVCC_3P3_5 contains Power Pin and Output Port objects (Pin U102-3, Pin U103-5, Port INTVCC).
Error | H-00488 - Card Slot.SchDoc | V_INTVCC_3P3_6 contains Power Pin and Output Port objects (Pin U102-3, Pin U103-5, Port INTVCC).
Error | H-00488 - Card Slot.SchDoc | V_INTVCC_3P3_7 contains Power Pin and Output Port objects (Pin U102-3, Pin U103-5, Port INTVCC).
Warning | H-00488 - Ethernet Switch.SchDoc | GND contains Input Pin and Unspecified Port objects (Pin U100-68, Pin U100-69, Pin U100-70, Pin U100-71, Pin U100-162, Pin U100-163, Pin U100-168, Pin U100-169, Pin U100-190, Pin U100-191, Pin U100-192, Pin U100-193, Pin U101-4, Pin U101-5, Port GND).
Warning | H-00488 - USB Hub.SchDoc | GND contains Input Pin and Unspecified Port objects (Pin U105-4, Pin U105-5, Port GND).
Warning | H-00488 - Card Slot Master.SchDoc | GND contains Input Pin and Unspecified Port objects (Pin U106-10, Pin U107-10, Port GND).
Warning | H-00488 - I2C Mux.SchDoc | GND contains Input Pin and Unspecified Port objects (Pin U108-18, Port GND).
Warning | H-00488 - Power.SchDoc | GND contains Input Pin and Unspecified Port objects (Pin U115-19, Port GND).

Warning

H-00488 - Top.SchDoc

GND contains Input Sheet Entry and Unspecified Sheet Entry objects (Sheet Entry SLOT4-A0(Input), Sheet Entry SLOT4-A1(Input), Sheet Entry SLOT6-A1(Input), Sheet Entry SLOT7-A1(Input), Sheet Entry ADDR-GND(Passive), Sheet Entry CONNECTORS-GND(Passive), Sheet Entry DOWNSTREAM-GND(Passive), Sheet Entry I2C-GND(Passive), Sheet Entry LAN-GND(Passive), Sheet Entry MASTER-GND(Passive), Sheet Entry POWER-GND(Passive), Sheet Entry SLOT1-GND(Passive), Sheet Entry SLOT2-GND(Passive), Sheet Entry SLOT3-GND(Passive), Sheet Entry SLOT4-GND(Passive), Sheet Entry SLOT5-GND(Passive), Sheet Entry SLOT6-GND(Passive), Sheet Entry SLOT7-GND(Passive), Sheet Entry UPSTREAM-GND(Passive), Sheet Entry USB-GND(Passive)).
Warning | H-00488 - Connectors Upstream.SchDoc | Multiple Harness Types on harness I2C_BACKPLANE, I2C_MASTER
Warning | H-00488 - Card Slot.SchDoc | Net ADR0_1 has no driving source (Pin NT126-2, Pin U102-5)
Warning | H-00488 - Card Slot.SchDoc | Net ADR0_2 has no driving source (Pin NT126-2, Pin U102-5)
Warning | H-00488 - Card Slot.SchDoc | Net ADR0_3 has no driving source (Pin NT126-2, Pin U102-5)
Warning | H-00488 - Card Slot.SchDoc | Net ADR0_4 has no driving source (Pin NT126-2, Pin U102-5)
Warning | H-00488 - Card Slot.SchDoc | Net ADR0_5 has no driving source (Pin NT126-2, Pin U102-5)
Warning | H-00488 - Card Slot.SchDoc | Net ADR0_6 has no driving source (Pin NT126-2, Pin U102-5)
Warning | H-00488 - Card Slot.SchDoc | Net ADR0_7 has no driving source (Pin NT126-2, Pin U102-5)
Warning | H-00488 - Card Slot.SchDoc | Net ADR1_1 has no driving source (Pin NT125-2, Pin U102-6)
Warning | H-00488 - Card Slot.SchDoc | Net ADR1_2 has no driving source (Pin NT125-2, Pin U102-6)
Warning | H-00488 - Card Slot.SchDoc | Net ADR1_3 has no driving source (Pin NT125-2, Pin U102-6)
Warning | H-00488 - Card Slot.SchDoc | Net ADR1_4 has no driving source (Pin NT125-2, Pin U102-6)
Warning | H-00488 - Card Slot.SchDoc | Net ADR1_5 has no driving source (Pin NT125-2, Pin U102-6)
Warning | H-00488 - Card Slot.SchDoc | Net ADR1_6 has no driving source (Pin NT125-2, Pin U102-6)
Warning | H-00488 - Card Slot.SchDoc | Net ADR1_7 has no driving source (Pin NT125-2, Pin U102-6)
Warning | H-00488 - Card Slot.SchDoc | Net CONFIG_1 has no driving source (Pin NT124-2, Pin U102-2)
Warning | H-00488 - Card Slot.SchDoc | Net CONFIG_2 has no driving source (Pin NT124-2, Pin U102-2)
Warning | H-00488 - Card Slot.SchDoc | Net CONFIG_3 has no driving source (Pin NT124-2, Pin U102-2)
Warning | H-00488 - Card Slot.SchDoc | Net CONFIG_4 has no driving source (Pin NT124-2, Pin U102-2)
Warning | H-00488 - Card Slot.SchDoc | Net CONFIG_5 has no driving source (Pin NT124-2, Pin U102-2)
Warning | H-00488 - Card Slot.SchDoc | Net CONFIG_6 has no driving source (Pin NT124-2, Pin U102-2)
Warning | H-00488 - Card Slot.SchDoc | Net CONFIG_7 has no driving source (Pin NT124-2, Pin U102-2)
Warning | H-00488 - I2C Address.SchDoc | Net DS_REF has no driving source (Pin R199-1, Pin R200-2, Pin U117-6)
Warning | H-00488 - Card Slot.SchDoc | Net EN_1 has no driving source (Pin R145-1, Pin U102-17, Pin U102-24)
Warning | H-00488 - Card Slot.SchDoc | Net EN_2 has no driving source (Pin R145-1, Pin U102-17, Pin U102-24)
Warning | H-00488 - Card Slot.SchDoc | Net EN_3 has no driving source (Pin R145-1, Pin U102-17, Pin U102-24)
Warning | H-00488 - Card Slot.SchDoc | Net EN_4 has no driving source (Pin R145-1, Pin U102-17, Pin U102-24)
Warning | H-00488 - Card Slot.SchDoc | Net EN_5 has no driving source (Pin R145-1, Pin U102-17, Pin U102-24)
Warning | H-00488 - Card Slot.SchDoc | Net EN_6 has no driving source (Pin R145-1, Pin U102-17, Pin U102-24)
Warning | H-00488 - Card Slot.SchDoc | Net EN_7 has no driving source (Pin R145-1, Pin U102-17, Pin U102-24)
Warning | H-00488 - Card Slot Master.SchDoc | Net ENABLE has no driving source (Pin C157-1, Pin R172-2, Pin U106-2, Pin U107-2)
Warning | H-00488 - Card Slot.SchDoc | Net FB1_1 has no driving source (Pin R140-2, Pin R141-1, Pin U102-26)
Warning | H-00488 - Card Slot.SchDoc | Net FB1_2 has no driving source (Pin R140-2, Pin R141-1, Pin U102-26)
Warning | H-00488 - Card Slot.SchDoc | Net FB1_3 has no driving source (Pin R140-2, Pin R141-1, Pin U102-26)
Warning | H-00488 - Card Slot.SchDoc | Net FB1_4 has no driving source (Pin R140-2, Pin R141-1, Pin U102-26)
Warning | H-00488 - Card Slot.SchDoc | Net FB1_5 has no driving source (Pin R140-2, Pin R141-1, Pin U102-26)
Warning | H-00488 - Card Slot.SchDoc | Net FB1_6 has no driving source (Pin R140-2, Pin R141-1, Pin U102-26)
Warning | H-00488 - Card Slot.SchDoc | Net FB1_7 has no driving source (Pin R140-2, Pin R141-1, Pin U102-26)
Warning | H-00488 - Card Slot.SchDoc | Net FB2_1 has no driving source (Pin R143-2, Pin R144-1, Pin U102-15)
Warning | H-00488 - Card Slot.SchDoc | Net FB2_2 has no driving source (Pin R143-2, Pin R144-1, Pin U102-15)
Warning | H-00488 - Card Slot.SchDoc | Net FB2_3 has no driving source (Pin R143-2, Pin R144-1, Pin U102-15)
Warning | H-00488 - Card Slot.SchDoc | Net FB2_4 has no driving source (Pin R143-2, Pin R144-1, Pin U102-15)
Warning | H-00488 - Card Slot.SchDoc | Net FB2_5 has no driving source (Pin R143-2, Pin R144-1, Pin U102-15)
Warning | H-00488 - Card Slot.SchDoc | Net FB2_6 has no driving source (Pin R143-2, Pin R144-1, Pin U102-15)
Warning | H-00488 - Card Slot.SchDoc | Net FB2_7 has no driving source (Pin R143-2, Pin R144-1, Pin U102-15)
Warning | H-00488 - Top.SchDoc | Net I2C0.RESET has no driving source (Pin C158-1, Pin D108-6, Pin D116-4, Pin R133-1, Pin R164-1, Pin R171-2, Pin U108-24)
Warning | H-00488 - Top.SchDoc | Net I2C.ID-DN has no driving source (Pin D116-6, Pin R196-2, Pin U117-3)
Warning | H-00488 - Top.SchDoc | Net I2C.ID-UP has no driving source (Pin D108-4, Pin R198-1, Pin U117-5)
Warning | H-00488 - Top.SchDoc | Net LAN1.RX_N has no driving source (Pin C138-1, Pin R138-1, Pin U100-197)
Warning | H-00488 - Top.SchDoc | Net LAN1.RX_P has no driving source (Pin C137-1, Pin R137-1, Pin U100-196)
Warning | H-00488 - Top.SchDoc | Net LAN2.RX_N has no driving source (Pin C138-1, Pin R138-1, Pin U100-207)
Warning | H-00488 - Top.SchDoc | Net LAN2.RX_P has no driving source (Pin C137-1, Pin R137-1, Pin U100-206)
Warning | H-00488 - Top.SchDoc | Net LAN3.RX_N has no driving source (Pin C138-1, Pin R138-1, Pin U100-6)
Warning | H-00488 - Top.SchDoc | Net LAN3.RX_P has no driving source (Pin C137-1, Pin R137-1, Pin U100-5)
Warning | H-00488 - Top.SchDoc | Net LAN4.RX_N has no driving source (Pin C138-1, Pin R138-1, Pin U100-23)
Warning | H-00488 - Top.SchDoc | Net LAN4.RX_P has no driving source (Pin C137-1, Pin R137-1, Pin U100-22)
Warning | H-00488 - Top.SchDoc | Net LAN5.RX_N has no driving source (Pin C138-1, Pin R138-1, Pin U100-31)
Warning | H-00488 - Top.SchDoc | Net LAN5.RX_P has no driving source (Pin C137-1, Pin R137-1, Pin U100-30)
Warning | H-00488 - Top.SchDoc | Net LAN6.RX_N has no driving source (Pin C138-1, Pin R138-1, Pin U100-48)
Warning | H-00488 - Top.SchDoc | Net LAN6.RX_P has no driving source (Pin C137-1, Pin R137-1, Pin U100-47)
Warning | H-00488 - Top.SchDoc | Net LAN7.RX_N has no driving source (Pin C138-1, Pin R138-1, Pin U100-55)
Warning | H-00488 - Top.SchDoc | Net LAN7.RX_P has no driving source (Pin C137-1, Pin R137-1, Pin U100-54)
Warning | H-00488 - Top.SchDoc | Net LAN8.RX_N has no driving source (Pin J108-6, Pin U100-65)
Warning | H-00488 - Top.SchDoc | Net LAN8.RX_P has no driving source (Pin J108-4, Pin U100-64)
Warning | H-00488 - Ethernet Switch.SchDoc | Net LAN_AUTOMDIX has no driving source (Pin R104-2, Pin U100-87)
Warning | H-00488 - Ethernet Switch.SchDoc | Net LAN_BIST has no driving source (Pin NT101-2, Pin U100-109)
Warning | H-00488 - Ethernet Switch.SchDoc | Net LAN_EN1P has no driving source (Pin NT111-2, Pin U100-91)
Warning | H-00488 - Ethernet Switch.SchDoc | Net LAN_IO_SWM has no driving source (Pin NT100-2, Pin U100-156)
Warning | H-00488 - Ethernet Switch.SchDoc | Net LAN_MODESEL0 has no driving source (Pin NT117-2, Pin U100-167)
Warning | H-00488 - Ethernet Switch.SchDoc | Net LAN_MODESEL1 has no driving source (Pin NT116-2, Pin U100-166)
Warning | H-00488 - Ethernet Switch.SchDoc | Net LAN_MODESEL2 has no driving source (Pin NT115-2, Pin U100-165)
Warning | H-00488 - Ethernet Switch.SchDoc | Net LAN_MODESEL3 has no driving source (Pin NT114-2, Pin U100-164)
Warning | H-00488 - Ethernet Switch.SchDoc | Net LAN_PRSV has no driving source (Pin NT109-2, Pin U100-170)
Warning | H-00488 - Ethernet Switch.SchDoc | Net LAN_RLPBK has no driving source (Pin NT102-2, Pin U100-82)
Warning | H-00488 - Ethernet Switch.SchDoc | Net LAN_RST has no driving source (Pin C132-1, Pin R114-2, Pin R133-2, Pin U100-110)
Warning | H-00488 - Ethernet Switch.SchDoc | Net LAN_X1 has no driving source (Pin C133-1, Pin R130-1, Pin U100-176, Pin Y100-1)
Warning | H-00488 - Power.SchDoc | Net NetR182_2 has no driving source (Pin R182-2, Pin R184-1, Pin U111-1)
Warning | H-00488 - Power.SchDoc | Net NetR186_2 has no driving source (Pin R186-2, Pin R187-1, Pin U113-1)
Warning | H-00488 - Ethernet Switch.SchDoc | Net NetU100_96 has no driving source (Pin U100-96)
Warning | H-00488 - Ethernet Switch.SchDoc | Net NetU100_97 has no driving source (Pin U100-97)
Warning | H-00488 - Ethernet Switch.SchDoc | Net NetU100_98 has no driving source (Pin U100-98)
Warning | H-00488 - Ethernet Switch.SchDoc | Net NetU100_99 has no driving source (Pin U100-99)
Warning | H-00488 - Ethernet Switch.SchDoc | Net NetU100_100 has no driving source (Pin U100-100)
Warning | H-00488 - Ethernet Switch.SchDoc | Net NetU100_101 has no driving source (Pin U100-101)
Warning | H-00488 - Power.SchDoc | Net NetU109_18 has no driving source (Pin U109-18)
Warning | H-00488 - Power.SchDoc | Net NetU109_23 has no driving source (Pin U109-23)
Warning | H-00488 - Power.SchDoc | Net NetU115_18 has no driving source (Pin U115-18)
Warning | H-00488 - Card Slot.SchDoc | Net ON_1 has no driving source (Pin NT122-2, Pin U102-22)
Warning | H-00488 - Card Slot.SchDoc | Net ON_2 has no driving source (Pin NT122-2, Pin U102-22)
Warning | H-00488 - Card Slot.SchDoc | Net ON_3 has no driving source (Pin NT122-2, Pin U102-22)
Warning | H-00488 - Card Slot.SchDoc | Net ON_4 has no driving source (Pin NT122-2, Pin U102-22)
Warning | H-00488 - Card Slot.SchDoc | Net ON_5 has no driving source (Pin NT122-2, Pin U102-22)
Warning | H-00488 - Card Slot.SchDoc | Net ON_6 has no driving source (Pin NT122-2, Pin U102-22)
Warning | H-00488 - Card Slot.SchDoc | Net ON_7 has no driving source (Pin NT122-2, Pin U102-22)
Warning | H-00488 - Card Slot.SchDoc | Net OV1_1 has no driving source (Pin NT119-2, Pin U102-32)
Warning | H-00488 - Card Slot.SchDoc | Net OV1_2 has no driving source (Pin NT119-2, Pin U102-32)
Warning | H-00488 - Card Slot.SchDoc | Net OV1_3 has no driving source (Pin NT119-2, Pin U102-32)
Warning | H-00488 - Card Slot.SchDoc | Net OV1_4 has no driving source (Pin NT119-2, Pin U102-32)
Warning | H-00488 - Card Slot.SchDoc | Net OV1_5 has no driving source (Pin NT119-2, Pin U102-32)
Warning | H-00488 - Card Slot.SchDoc | Net OV1_6 has no driving source (Pin NT119-2, Pin U102-32)
Warning | H-00488 - Card Slot.SchDoc | Net OV1_7 has no driving source (Pin NT119-2, Pin U102-32)
Warning | H-00488 - Card Slot.SchDoc | Net OV2_1 has no driving source (Pin NT121-2, Pin U102-9)
Warning | H-00488 - Card Slot.SchDoc | Net OV2_2 has no driving source (Pin NT121-2, Pin U102-9)
Warning | H-00488 - Card Slot.SchDoc | Net OV2_3 has no driving source (Pin NT121-2, Pin U102-9)
Warning | H-00488 - Card Slot.SchDoc | Net OV2_4 has no driving source (Pin NT121-2, Pin U102-9)
Warning | H-00488 - Card Slot.SchDoc | Net OV2_5 has no driving source (Pin NT121-2, Pin U102-9)
Warning | H-00488 - Card Slot.SchDoc | Net OV2_6 has no driving source (Pin NT121-2, Pin U102-9)
Warning | H-00488 - Card Slot.SchDoc | Net OV2_7 has no driving source (Pin NT121-2, Pin U102-9)
Warning | H-00488 - Power.SchDoc | Net PWR_ADR0 has no driving source (Pin NT137-2, Pin U109-5)
Warning | H-00488 - Power.SchDoc | Net PWR_ADR1 has no driving source (Pin NT136-2, Pin U109-6)
Warning | H-00488 - Power.SchDoc | Net PWR_CONFIG has no driving source (Pin NT135-2, Pin U109-2)
Warning | H-00488 - Power.SchDoc | Net PWR_EN1 has no driving source (Pin NT132-1, Pin U109-24)
Warning | H-00488 - Power.SchDoc | Net PWR_EN2 has no driving source (Pin NT134-1, Pin U109-17)
Warning | H-00488 - Power.SchDoc | Net PWR_EN_2P1 has no driving source (Pin U113-9)
Warning | H-00488 - Power.SchDoc | Net PWR_EN_3P3 has no driving source (Pin U111-9)
Warning | H-00488 - Power.SchDoc | Net PWR_FB1 has no driving source (Pin R177-2, Pin R180-1, Pin U109-26)
Warning | H-00488 - Power.SchDoc | Net PWR_FB2 has no driving source (Pin R189-2, Pin R190-1, Pin U109-15)
Warning | H-00488 - Power.SchDoc | Net PWR_ON has no driving source (Pin NT131-2, Pin U109-22)
Warning | H-00488 - Power.SchDoc | Net PWR_OV1 has no driving source (Pin R179-2, Pin R181-1, Pin U109-32)
Warning | H-00488 - Power.SchDoc | Net PWR_OV2 has no driving source (Pin NT130-2, Pin U109-9)
Warning | H-00488 - Power.SchDoc | Net PWR_SENSE1 has no driving source (Pin Q102-1, Pin Q102-2, Pin Q102-5, Pin Q102-6, Pin Q102-7, Pin R175-1, Pin U109-29)
Warning | H-00488 - Power.SchDoc | Net PWR_SENSE2 has no driving source (Pin Q106-1, Pin Q106-2, Pin Q106-5, Pin Q106-6, Pin Q106-7, Pin R188-1, Pin U109-12)
Warning | H-00488 - Power.SchDoc | Net PWR_SS has no driving source (Pin C173-1, Pin U109-1)
Warning | H-00488 - Power.SchDoc | Net PWR_TIMER has no driving source (Pin NT133-2, Pin U109-8)
Warning | H-00488 - Power.SchDoc | Net PWR_UV1 has no driving source (Pin R176-2, Pin R179-1, Pin U109-31)
Warning | H-00488 - Power.SchDoc | Net PWR_UV2 has no driving source (Pin NT129-2, Pin U109-10)
Warning | H-00488 - Card Slot.SchDoc | Net SENSE1_1 has no driving source (Pin Q100-1, Pin Q100-2, Pin Q100-5, Pin Q100-6, Pin Q100-7, Pin R139-1, Pin U102-29)
Warning | H-00488 - Card Slot.SchDoc | Net SENSE1_2 has no driving source (Pin Q100-1, Pin Q100-2, Pin Q100-5, Pin Q100-6, Pin Q100-7, Pin R139-1, Pin U102-29)
Warning | H-00488 - Card Slot.SchDoc | Net SENSE1_3 has no driving source (Pin Q100-1, Pin Q100-2, Pin Q100-5, Pin Q100-6, Pin Q100-7, Pin R139-1, Pin U102-29)
Warning | H-00488 - Card Slot.SchDoc | Net SENSE1_4 has no driving source (Pin Q100-1, Pin Q100-2, Pin Q100-5, Pin Q100-6, Pin Q100-7, Pin R139-1, Pin U102-29)
Warning | H-00488 - Card Slot.SchDoc | Net SENSE1_5 has no driving source (Pin Q100-1, Pin Q100-2, Pin Q100-5, Pin Q100-6, Pin Q100-7, Pin R139-1, Pin U102-29)
Warning | H-00488 - Card Slot.SchDoc | Net SENSE1_6 has no driving source (Pin Q100-1, Pin Q100-2, Pin Q100-5, Pin Q100-6, Pin Q100-7, Pin R139-1, Pin U102-29)
Warning | H-00488 - Card Slot.SchDoc | Net SENSE1_7 has no driving source (Pin Q100-1, Pin Q100-2, Pin Q100-5, Pin Q100-6, Pin Q100-7, Pin R139-1, Pin U102-29)
Warning | H-00488 - Card Slot.SchDoc | Net SENSE2_1 has no driving source (Pin Q101-1, Pin Q101-2, Pin Q101-5, Pin Q101-6, Pin Q101-7, Pin R142-1, Pin U102-12)
Warning | H-00488 - Card Slot.SchDoc | Net SENSE2_2 has no driving source (Pin Q101-1, Pin Q101-2, Pin Q101-5, Pin Q101-6, Pin Q101-7, Pin R142-1, Pin U102-12)
Warning | H-00488 - Card Slot.SchDoc | Net SENSE2_3 has no driving source (Pin Q101-1, Pin Q101-2, Pin Q101-5, Pin Q101-6, Pin Q101-7, Pin R142-1, Pin U102-12)
Warning | H-00488 - Card Slot.SchDoc | Net SENSE2_4 has no driving source (Pin Q101-1, Pin Q101-2, Pin Q101-5, Pin Q101-6, Pin Q101-7, Pin R142-1, Pin U102-12)
Warning | H-00488 - Card Slot.SchDoc | Net SENSE2_5 has no driving source (Pin Q101-1, Pin Q101-2, Pin Q101-5, Pin Q101-6, Pin Q101-7, Pin R142-1, Pin U102-12)
Warning | H-00488 - Card Slot.SchDoc | Net SENSE2_6 has no driving source (Pin Q101-1, Pin Q101-2, Pin Q101-5, Pin Q101-6, Pin Q101-7, Pin R142-1, Pin U102-12)
Warning | H-00488 - Card Slot.SchDoc | Net SENSE2_7 has no driving source (Pin Q101-1, Pin Q101-2, Pin Q101-5, Pin Q101-6, Pin Q101-7, Pin R142-1, Pin U102-12)
Warning | H-00488 - Card Slot.SchDoc | Net SS_1 has no driving source (Pin C141-1, Pin U102-1)
Warning | H-00488 - Card Slot.SchDoc | Net SS_2 has no driving source (Pin C141-1, Pin U102-1)
Warning | H-00488 - Card Slot.SchDoc | Net SS_3 has no driving source (Pin C141-1, Pin U102-1)
Warning | H-00488 - Card Slot.SchDoc | Net SS_4 has no driving source (Pin C141-1, Pin U102-1)
Warning | H-00488 - Card Slot.SchDoc | Net SS_5 has no driving source (Pin C141-1, Pin U102-1)
Warning | H-00488 - Card Slot.SchDoc | Net SS_6 has no driving source (Pin C141-1, Pin U102-1)
Warning | H-00488 - Card Slot.SchDoc | Net SS_7 has no driving source (Pin C141-1, Pin U102-1)
Warning | H-00488 - Card Slot.SchDoc | Net TIMER_1 has no driving source (Pin NT123-2, Pin U102-8)
Warning | H-00488 - Card Slot.SchDoc | Net TIMER_2 has no driving source (Pin NT123-2, Pin U102-8)
Warning | H-00488 - Card Slot.SchDoc | Net TIMER_3 has no driving source (Pin NT123-2, Pin U102-8)
Warning | H-00488 - Card Slot.SchDoc | Net TIMER_4 has no driving source (Pin NT123-2, Pin U102-8)
Warning | H-00488 - Card Slot.SchDoc | Net TIMER_5 has no driving source (Pin NT123-2, Pin U102-8)
Warning | H-00488 - Card Slot.SchDoc | Net TIMER_6 has no driving source (Pin NT123-2, Pin U102-8)
Warning | H-00488 - Card Slot.SchDoc | Net TIMER_7 has no driving source (Pin NT123-2, Pin U102-8)
Warning | H-00488 - I2C Address.SchDoc | Net US_REF has no driving source (Pin R195-1, Pin R197-2, Pin U117-2)
Warning | H-00488 - USB Hub.SchDoc | Net USB_RESET has no driving source (Pin C154-1, Pin R161-2, Pin R164-2, Pin U104-43)
Warning | H-00488 - USB Hub.SchDoc | Net USB_SUSP has no driving source (Pin R160-2, Pin U104-45)
Warning | H-00488 - USB Hub.SchDoc | Net USB_XTAL1 has no driving source (Pin C155-1, Pin R165-1, Pin U104-61, Pin Y101-3)
Warning | H-00488 - Card Slot.SchDoc | Net UV1_1 has no driving source (Pin NT118-2, Pin U102-31)
Warning | H-00488 - Card Slot.SchDoc | Net UV1_2 has no driving source (Pin NT118-2, Pin U102-31)
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

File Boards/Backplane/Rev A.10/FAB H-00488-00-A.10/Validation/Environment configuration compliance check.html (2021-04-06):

Altium

# Environment compilance report for Project H-00488.PrjPcb

Date: | | 1-2-2021
Time: | | 20:55:00

## Schematic documents

File | Status | Details
C:\Users\Joris\AppData\Local\TempReleases\Snapshot\1\Schematics\H-00488 - Top.SchDoc | Check passed | Item uses correct schematic template
C:\Users\Joris\AppData\Local\TempReleases\Snapshot\1\Schematics\H-00488 - Release Checklist.SchDoc | Check passed | Item uses correct schematic template
C:\Users\Joris\AppData\Local\TempReleases\Snapshot\1\Schematics\H-00488 - Power.SchDoc | Check passed | Item uses correct schematic template
C:\Users\Joris\AppData\Local\TempReleases\Snapshot\1\Schematics\H-00488 - I2C Address.SchDoc | Check passed | Item uses correct schematic template
C:\Users\Joris\AppData\Local\TempReleases\Snapshot\1\Schematics\H-00488 - I2C Mux.SchDoc | Check passed | Item uses correct schematic template
C:\Users\Joris\AppData\Local\TempReleases\Snapshot\1\Schematics\H-00488 - Ethernet Switch.SchDoc | Check passed | Item uses correct schematic template
C:\Users\Joris\AppData\Local\TempReleases\Snapshot\1\Schematics\H-00488 - USB Hub.SchDoc | Check passed | Item uses correct schematic template
C:\Users\Joris\AppData\Local\TempReleases\Snapshot\1\Schematics\H-00488 - Card Slot.SchDoc | Check passed | Item uses correct schematic template
C:\Users\Joris\AppData\Local\TempReleases\Snapshot\1\Schematics\H-00488 - Card Slot Master.SchDoc | Check passed | Item uses correct schematic template
C:\Users\Joris\AppData\Local\TempReleases\Snapshot\1\Schematics\H-00488 - Connectors.SchDoc | Check passed | Item uses correct schematic template
C:\Users\Joris\AppData\Local\TempReleases\Snapshot\1\Schematics\H-00488 - Connectors Upstream.SchDoc | Check passed | Item uses correct schematic template
C:\Users\Joris\AppData\Local\TempReleases\Snapshot\1\Schematics\H-00488 - Connectors Downstream.SchDoc | Check passed | Item uses correct schematic template

Back to top

## Parts

Document | Part | Status | Description
H-00488 - Top.SchDoc | C0402C104K8RACTU(C174) | Check passed | Part comes from a server
H-00488 - Top.SchDoc | FIDUCIAL(FID100) | Check passed | Part comes from a server
H-00488 - Top.SchDoc | FIDUCIAL(FID101) | Check passed | Part comes from a server
H-00488 - Top.SchDoc | FIDUCIAL(FID102) | Check passed | Part comes from a server
H-00488 - Top.SchDoc | FIDUCIAL(FID103) | Check passed | Part comes from a server
H-00488 - Top.SchDoc | LOGO-HIBER(G100) | Check passed | Part comes from a server
H-00488 - Top.SchDoc | HIBER-PARTNUMBER(G101) | Check passed | Part comes from a server
H-00488 - Top.SchDoc | MOUNTING-HOLE(MH100) | Check passed | Part comes from a server
H-00488 - Top.SchDoc | MOUNTING-HOLE(MH101) | Check passed | Part comes from a server
H-00488 - Top.SchDoc | MOUNTING-HOLE(MH102) | Check passed | Part comes from a server
H-00488 - Top.SchDoc | MOUNTING-HOLE(MH103) | Check passed | Part comes from a server
H-00488 - Top.SchDoc | MOUNTING-HOLE(MH104) | Check passed | Part comes from a server
H-00488 - Top.SchDoc | MOUNTING-HOLE(MH105) | Check passed | Part comes from a server
H-00488 - Top.SchDoc | MOUNTING-HOLE(MH106) | Check passed | Part comes from a server
H-00488 - Top.SchDoc | MOUNTING-HOLE(MH107) | Check passed | Part comes from a server
H-00488 - Top.SchDoc | MOUNTING-HOLE(MH108) | Check passed | Part comes from a server
H-00488 - Top.SchDoc | MOUNTING-HOLE(MH109) | Check passed | Part comes from a server
H-00488 - Top.SchDoc | MOUNTING-HOLE(MH110) | Check passed | Part comes from a server
H-00488 - Top.SchDoc | MOUNTING-HOLE(MH111) | Check passed | Part comes from a server
H-00488 - Top.SchDoc | MOUNTING-HOLE(MH112) | Check passed | Part comes from a server
H-00488 - Top.SchDoc | MOUNTING-HOLE(MH113) | Check passed | Part comes from a server
H-00488 - Top.SchDoc | LABEL-190x65(MP100) | Check passed | Part comes from a server
H-00488 - Top.SchDoc | TITLE-BLOCK(PCB100) | Check passed | Part comes from a server
H-00488 - Top.SchDoc | CRCW040210K0FKED(R201) | Check passed | Part comes from a server
H-00488 - Power.SchDoc | C1210C106K5RACTU(C162) | Check passed | Part comes from a server
H-00488 - Power.SchDoc | C1210C106K5RACTU(C163) | Check passed | Part comes from a server
H-00488 - Power.SchDoc | C1210C106K5RACTU(C164) | Check passed | Part comes from a server
H-00488 - Power.SchDoc | C0402C223K5RACTU(C165) | Check passed | Part comes from a server
H-00488 - Power.SchDoc | C1210C476M8RACTU(C166) | Check passed | Part comes from a server
H-00488 - Power.SchDoc | C0402C223K5RACTU(C167) | Check passed | Part comes from a server
H-00488 - Power.SchDoc | C1210C476M8RACTU(C168) | Check passed | Part comes from a server
H-00488 - Power.SchDoc | C0402C223K5RACTU(C169) | Check passed | Part comes from a server
H-00488 - Power.SchDoc | C1210C476M8RACTU(C170) | Check passed | Part comes from a server
H-00488 - Power.SchDoc | C1210C476M8RACTU(C171) | Check passed | Part comes from a server
H-00488 - Power.SchDoc | C0402C104K8RACTU(C172) | Check passed | Part comes from a server
H-00488 - Power.SchDoc | C0402C104K8RACTU(C173) | Check passed | Part comes from a server
H-00488 - Power.SchDoc | SML-E12P8W(D131) | Check passed | Part comes from a server
H-00488 - Power.SchDoc | SML-E12P8W(D132) | Check passed | Part comes from a server
H-00488 - Power.SchDoc | NET-TIE(NT129) | Check passed | Part comes from a server
H-00488 - Power.SchDoc | NET-TIE(NT130) | Check passed | Part comes from a server
H-00488 - Power.SchDoc | NET-TIE(NT131) | Check passed | Part comes from a server
H-00488 - Power.SchDoc | NET-TIE(NT132) | Check passed | Part comes from a server
H-00488 - Power.SchDoc | NET-TIE(NT133) | Check passed | Part comes from a server
H-00488 - Power.SchDoc | NET-TIE(NT134) | Check passed | Part comes from a server
H-00488 - Power.SchDoc | NET-TIE(NT135) | Check passed | Part comes from a server
H-00488 - Power.SchDoc | NET-TIE(NT136) | Check passed | Part comes from a server
H-00488 - Power.SchDoc | NET-TIE(NT137) | Check passed | Part comes from a server
H-00488 - Power.SchDoc | BUK7D25-40EX(Q102) | Check passed | Part comes from a server
H-00488 - Power.SchDoc | BUK7D25-40EX(Q103) | Check passed | Part comes from a server
H-00488 - Power.SchDoc | BUK7D25-40EX(Q104) | Check passed | Part comes from a server
H-00488 - Power.SchDoc | BUK7D25-40EX(Q105) | Check passed | Part comes from a server
H-00488 - Power.SchDoc | BUK7D25-40EX(Q106) | Check passed | Part comes from a server
H-00488 - Power.SchDoc | CRCW040220K0FKED(R101) | Check passed | Part comes from a server
H-00488 - Power.SchDoc | WSLP0805R0100FEA(R175) | Check passed | Part comes from a server
H-00488 - Power.SchDoc | CRCW0402200KFKED(R176) | Check passed | Part comes from a server
H-00488 - Power.SchDoc | CRCW040220K0FKED(R177) | Check passed | Part comes from a server
H-00488 - Power.SchDoc | CRCW040247R0FKED(R178) | Check passed | Part comes from a server
H-00488 - Power.SchDoc | CRCW04021K20FKED(R179) | Check passed | Part comes from a server
H-00488 - Power.SchDoc | CRCW04021K20FKED(R180) | Check passed | Part comes from a server
H-00488 - Power.SchDoc | CRCW040210K0FKED(R181) | Check passed | Part comes from a server
H-00488 - Power.SchDoc | CRCW040210K0FKED(R182) | Check passed | Part comes from a server
H-00488 - Power.SchDoc | CRCW040247R0FKED(R183) | Check passed | Part comes from a server
H-00488 - Power.SchDoc | CRCW04022K20FKED(R184) | Check passed | Part comes from a server
H-00488 - Power.SchDoc | CRCW040247R0FKED(R185) | Check passed | Part comes from a server
H-00488 - Power.SchDoc | CRCW040210K0FKED(R186) | Check passed | Part comes from a server
H-00488 - Power.SchDoc | CRCW04023K90FKED(R187) | Check passed | Part comes from a server
H-00488 - Power.SchDoc | WSLP0805R0100FEA(R188) | Check passed | Part comes from a server
H-00488 - Power.SchDoc | CRCW040210K0FKED(R189) | Check passed | Part comes from a server
H-00488 - Power.SchDoc | CRCW04023K90FKED(R190) | Check passed | Part comes from a server
H-00488 - Power.SchDoc | CRCW04021K20FKED(R191) | Check passed | Part comes from a server
H-00488 - Power.SchDoc | CRCW04021K20FKED(R192) | Check passed | Part comes from a server
H-00488 - Power.SchDoc | CRCW040220K0FKED(R193) | Check passed | Part comes from a server
H-00488 - Power.SchDoc | CRCW040210K0FKED(R194) | Check passed | Part comes from a server
H-00488 - Power.SchDoc | LTC4222IUH#PBF(U109) | Check passed | Part comes from a server
H-00488 - Power.SchDoc | LTC4222IUH#PBF(U109) | Check passed | Part comes from a server
H-00488 - Power.SchDoc | LTC4222IUH#PBF(U109) | Check passed | Part comes from a server
H-00488 - Power.SchDoc | LM5050Q1MK-1/NOPB(U110) | Check passed | Part comes from a server
H-00488 - Power.SchDoc | TPSM84209RKHR(U111) | Check passed | Part comes from a server
H-00488 - Power.SchDoc | LM5050Q1MK-1/NOPB(U112) | Check passed | Part comes from a server
H-00488 - Power.SchDoc | TPSM84209RKHR(U113) | Check passed | Part comes from a server
H-00488 - Power.SchDoc | LM5050Q1MK-1/NOPB(U114) | Check passed | Part comes from a server
H-00488 - Power.SchDoc | LMZM33606RLXR(U115) | Check passed | Part comes from a server
H-00488 - Power.SchDoc | SN74LVC1G125DCKR(U116) | Check passed | Part comes from a server
H-00488 - Power.SchDoc | SN74LVC1G125DCKR(U116) | Check passed | Part comes from a server
H-00488 - I2C Address.SchDoc | CRCW040210K0FKED(R195) | Check passed | Part comes from a server
H-00488 - I2C Address.SchDoc | CRCW040210K0FKED(R196) | Check passed | Part comes from a server
H-00488 - I2C Address.SchDoc | CRCW04022K20FKED(R197) | Check passed | Part comes from a server
H-00488 - I2C Address.SchDoc | CRCW040210K0FKED(R198) | Check passed | Part comes from a server
H-00488 - I2C Address.SchDoc | CRCW040210K0FKED(R199) | Check passed | Part comes from a server
H-00488 - I2C Address.SchDoc | CRCW04022K20FKED(R200) | Check passed | Part comes from a server
H-00488 - I2C Address.SchDoc | TLV7022DDFR(U117) | Check passed | Part comes from a server
H-00488 - I2C Address.SchDoc | TLV7022DDFR(U117) | Check passed | Part comes from a server
H-00488 - I2C Address.SchDoc | TLV7022DDFR(U117) | Check passed | Part comes from a server
H-00488 - I2C Mux.SchDoc | C0402C104K8RACTU(C161) | Check passed | Part comes from a server
H-00488 - I2C Mux.SchDoc | CRCW04023K90FKED(R173) | Check passed | Part comes from a server
H-00488 - I2C Mux.SchDoc | CRCW04023K90FKED(R174) | Check passed | Part comes from a server
H-00488 - I2C Mux.SchDoc | TCA9548AMRGER(U108) | Check passed | Part comes from a server
H-00488 - Ethernet Switch.SchDoc | C0402C104K8RACTU(C100) | Check passed | Part comes from a server
H-00488 - Ethernet Switch.SchDoc | C0402C104K8RACTU(C101) | Check passed | Part comes from a server
H-00488 - Ethernet Switch.SchDoc | C0402C104K8RACTU(C102) | Check passed | Part comes from a server
H-00488 - Ethernet Switch.SchDoc | C0402C104K8RACTU(C103) | Check passed | Part comes from a server
H-00488 - Ethernet Switch.SchDoc | C0402C104K8RACTU(C104) | Check passed | Part comes from a server
H-00488 - Ethernet Switch.SchDoc | C0402C104K8RACTU(C105) | Check passed | Part comes from a server
H-00488 - Ethernet Switch.SchDoc | C0402C104K8RACTU(C106) | Check passed | Part comes from a server
H-00488 - Ethernet Switch.SchDoc | C0402C104K8RACTU(C107) | Check passed | Part comes from a server
H-00488 - Ethernet Switch.SchDoc | C0402C104K8RACTU(C108) | Check passed | Part comes from a server
H-00488 - Ethernet Switch.SchDoc | C0402C104K8RACTU(C109) | Check passed | Part comes from a server
H-00488 - Ethernet Switch.SchDoc | C0402C104K8RACTU(C110) | Check passed | Part comes from a server
H-00488 - Ethernet Switch.SchDoc | C0402C104K8RACTU(C111) | Check passed | Part comes from a server
H-00488 - Ethernet Switch.SchDoc | C0402C104K8RACTU(C112) | Check passed | Part comes from a server
H-00488 - Ethernet Switch.SchDoc | C0402C104K8RACTU(C113) | Check passed | Part comes from a server
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

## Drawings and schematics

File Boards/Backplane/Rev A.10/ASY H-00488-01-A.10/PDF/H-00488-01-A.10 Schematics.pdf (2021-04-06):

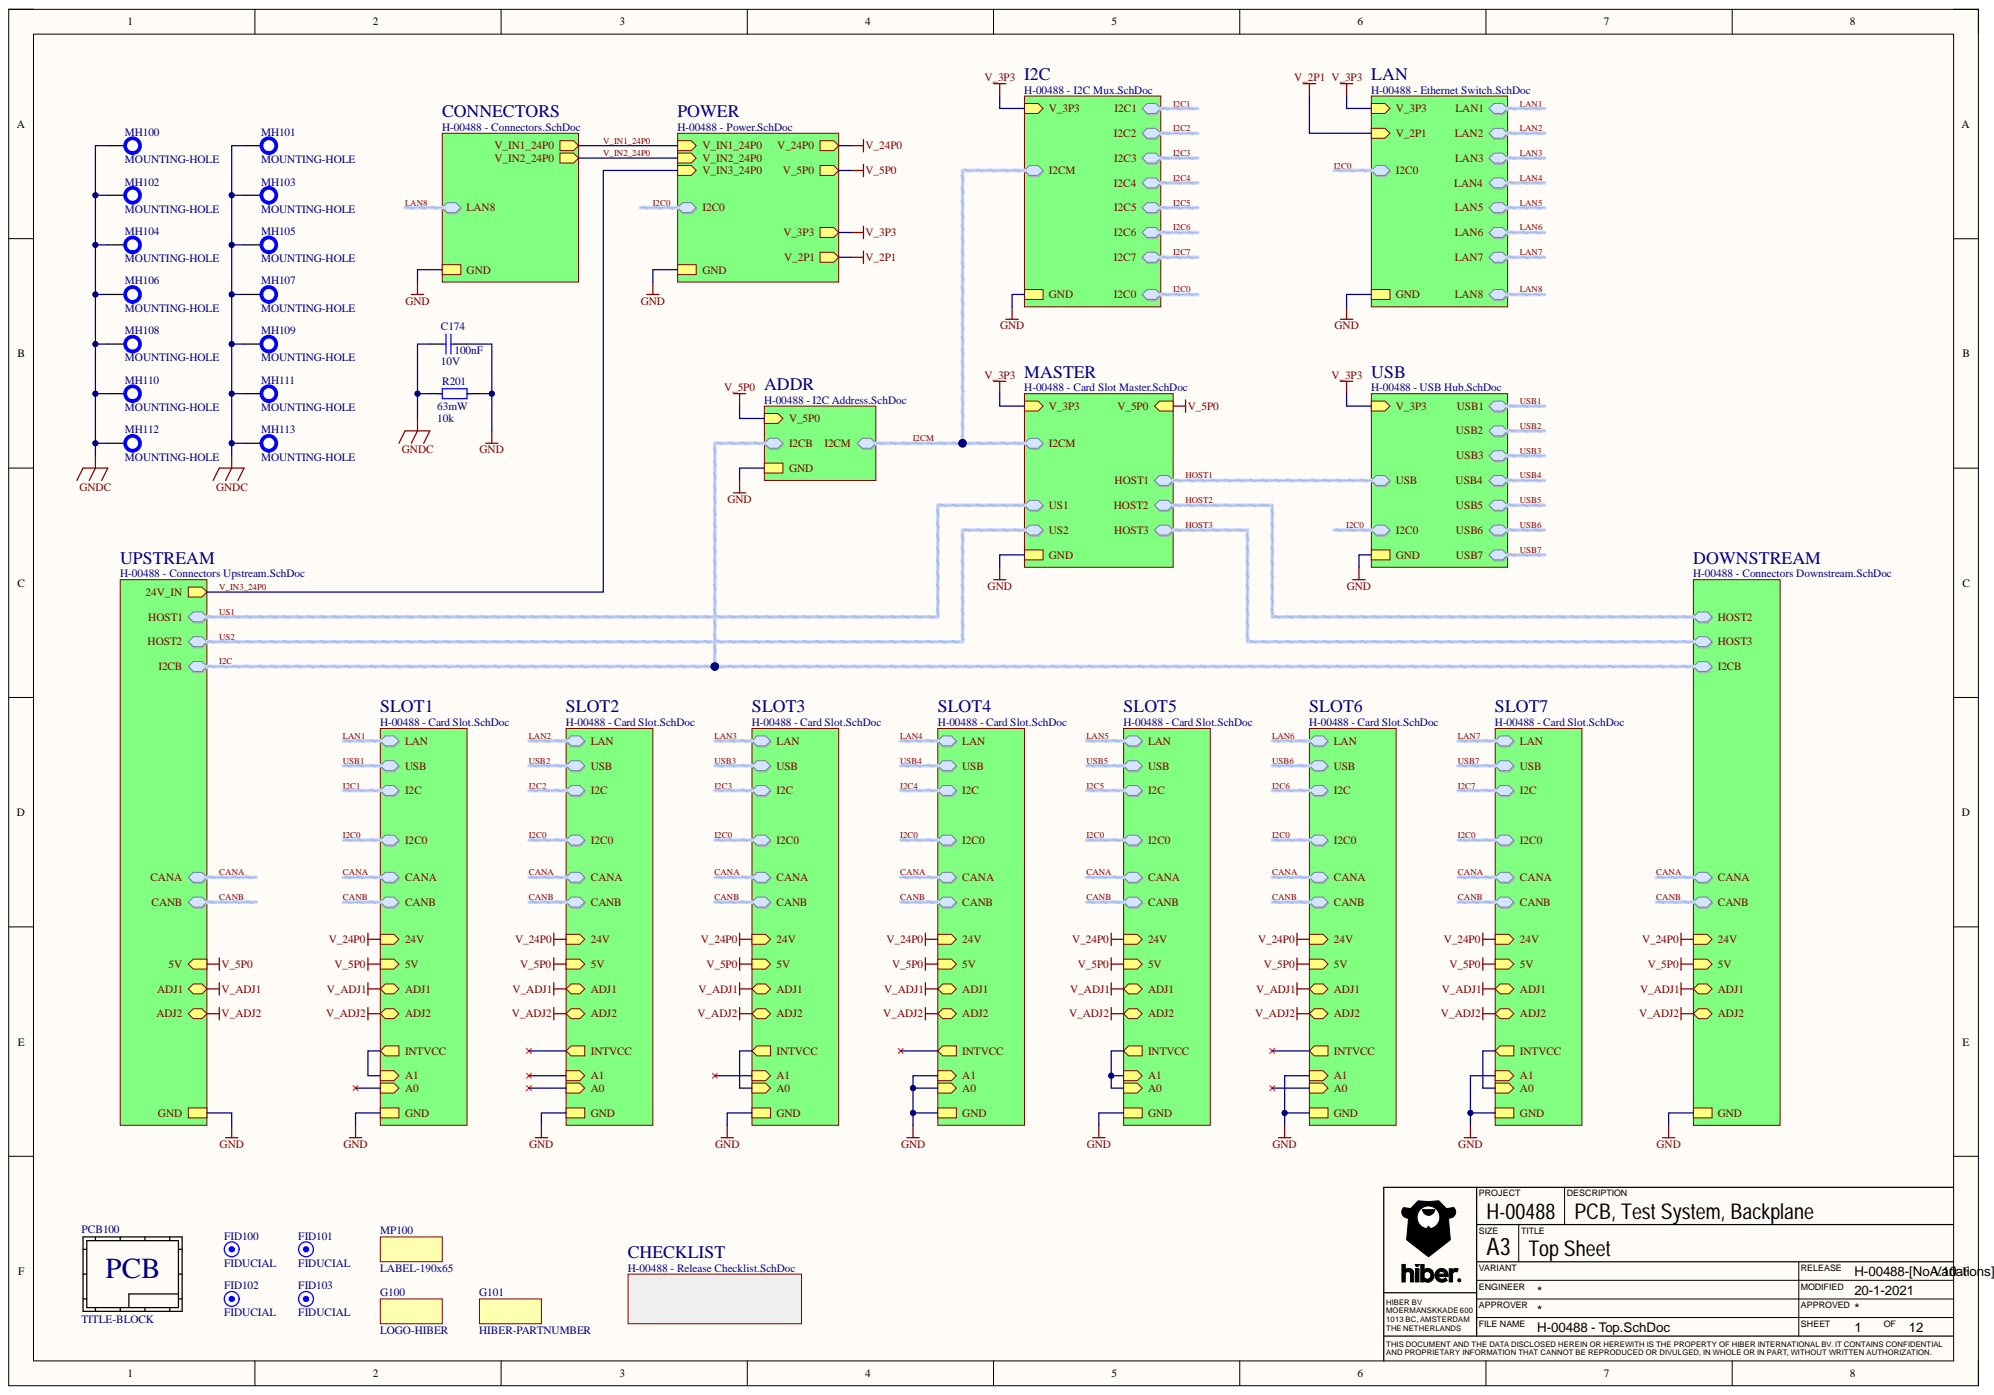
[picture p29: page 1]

MASTER H-00488 - Card Slot Master.SchDoc

USB H-00488 - USB Hub.SchDoc

UPSTREAM H-00488 - Connectors Upstream.SchDoc

DOWNSTREAM H-00488 - Connectors Downstream.SchDoc

DESCRIPTION
PCB, Test System, Backplane

CHECKLIST H-00488 - Release Checklist.SchDoc

THIS DOCUMENT AND THE DATA DISCLOSED HEREIN OR HEREWITH IS THE PROPERTY OF HIBER INTERNATIONAL BV. IT CONTAINS CONFIDENTIAL
AND PROPRIETARY INFORMATION THAT CANNOT BE REPRODUCED OR DIVULGED, IN WHOLE OR IN PART, WITHOUT WRITTEN AUTHORIZATION.

F | F
E | E
D | D
C | C
B | B
A | A

A3

### H-00488 - Release Checklist.SchDoc

SIZE

APPROVED -

H-00488

PROJECT

# PCB, Test System, Backplane

DESCRIPTION

# Release Checklist

TITLE

VARIANT | RELEASE | H-00488-[No Variations]- A.10

A

# Project

### Project Settings

### [ ] Net Identifier Scope is Strict Hierarchical (Local Power Ports)

### [ ] Project Parameters "ProjectDescription" and "ProjectName" Are set

### Variants

### Outjobs

### [ ] Project has at least one variant

### [ ] Each Variant has parameter VariantName (2 digit number, typically 01)

### [ ] Each Variant has parameter VariantDescription (typically "Assembly")

[ ] Project is using the most recent Managed Assembly / Fabrication Outjob (Under Project Options→Managed Outjobs)

### Documentation

[ ] The Top Level sheet contains documentation to guide (firmware) team member towards the information they need.

### [ ] Project contains Label Placeholder component

### [ ] Project contains Partnumber component

### [ ] Project contains logo component

# Schematics

### Style

[ ] All schematic sheets are using the Hiber Sheet Template (A2/A3/A4; A3 is HIGHLY preferred)

[ ] All schematic sheets are named H-12345 - Sheet Name.SchDoc (Except for managed sheets)

### [ ] All sheets are numbered (Tools → Annotation → Number Schematic Sheets)

### [ ] All sheets have the Title field set in the Title Block (Properties → Params)

### Best Practices

### [ ] All nets and connections should be on 100mil grid

### [ ] No 4-way junctions

### Data integrity

### [ ] All parts have unique 3-digit designators

[ ] Designators are logically organised (For example sheet 1 starting with 100, Tools→ Annotation→ Annotate Schematics)

### [ ] All components are managed by the Hiber Server

### [ ] All components are up-to-date (and not obsolete)

### Net Naming

### [ ] Ideally all nets should be named (to avoid names like NetP101_9)

[ ] All nets should be fully uppercase, using underscore as separator.

[ ] All Power nets are named: V_<name>_<voltage>: e.g.: V_MCU_3P3, V_IN_BAT, V_CORE_1P8, V_PA_BIAS_12N0

### Common Mistakes

### [ ] All I2C's have pull-ups with an appropriate value

### [ ] Checked all serial ports for RX/TX swaps

# Board

### Documentation

[ ] Run "UpdateAssemblyDesignators" Script to automatically size and center designators (on Assembly layer)

[ ] Main Grid and Dimensions are Metric.

[ ] Where possible defining features should be placed on a mm grid. (e.g. Mounting holes, Fiducials)

[ ] Make sure the Mechanical Naming structure is followed (Go to Panels→View Configuration).

### [ ] Teardrops are added

### [ ] Default hiber PCB specification / acceptance notes are present

### Design For manufacturing

### [ ] If possible all surface mount components should be placed on one side

### [ ] All heavy components are placed don the same side

### [ ] Board contains dimensions on Drill Drawing layer indicating defining dimensions

### 10 Commandments of PCB Design

### [ ] Never ignore the return current

### [ ] Minimize via perforation of planes under BGAs

### [ ] Never route a high speed signal over a slit in ref plane

### [ ] Extreme care when routing HS signal between layers

[ ] Don't leave your vias open (consider only tenting component side, so bottom can be used for probing)

### [ ] Cutout the ground in critical locations

### [ ] Avoid routing DDR memory on outer layers

### [ ] Always double check your gerbers with a viewer

### [ ] Don't break a board from the panel by hand

### [ ] Don't try to annotate everything on the silkscreen
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

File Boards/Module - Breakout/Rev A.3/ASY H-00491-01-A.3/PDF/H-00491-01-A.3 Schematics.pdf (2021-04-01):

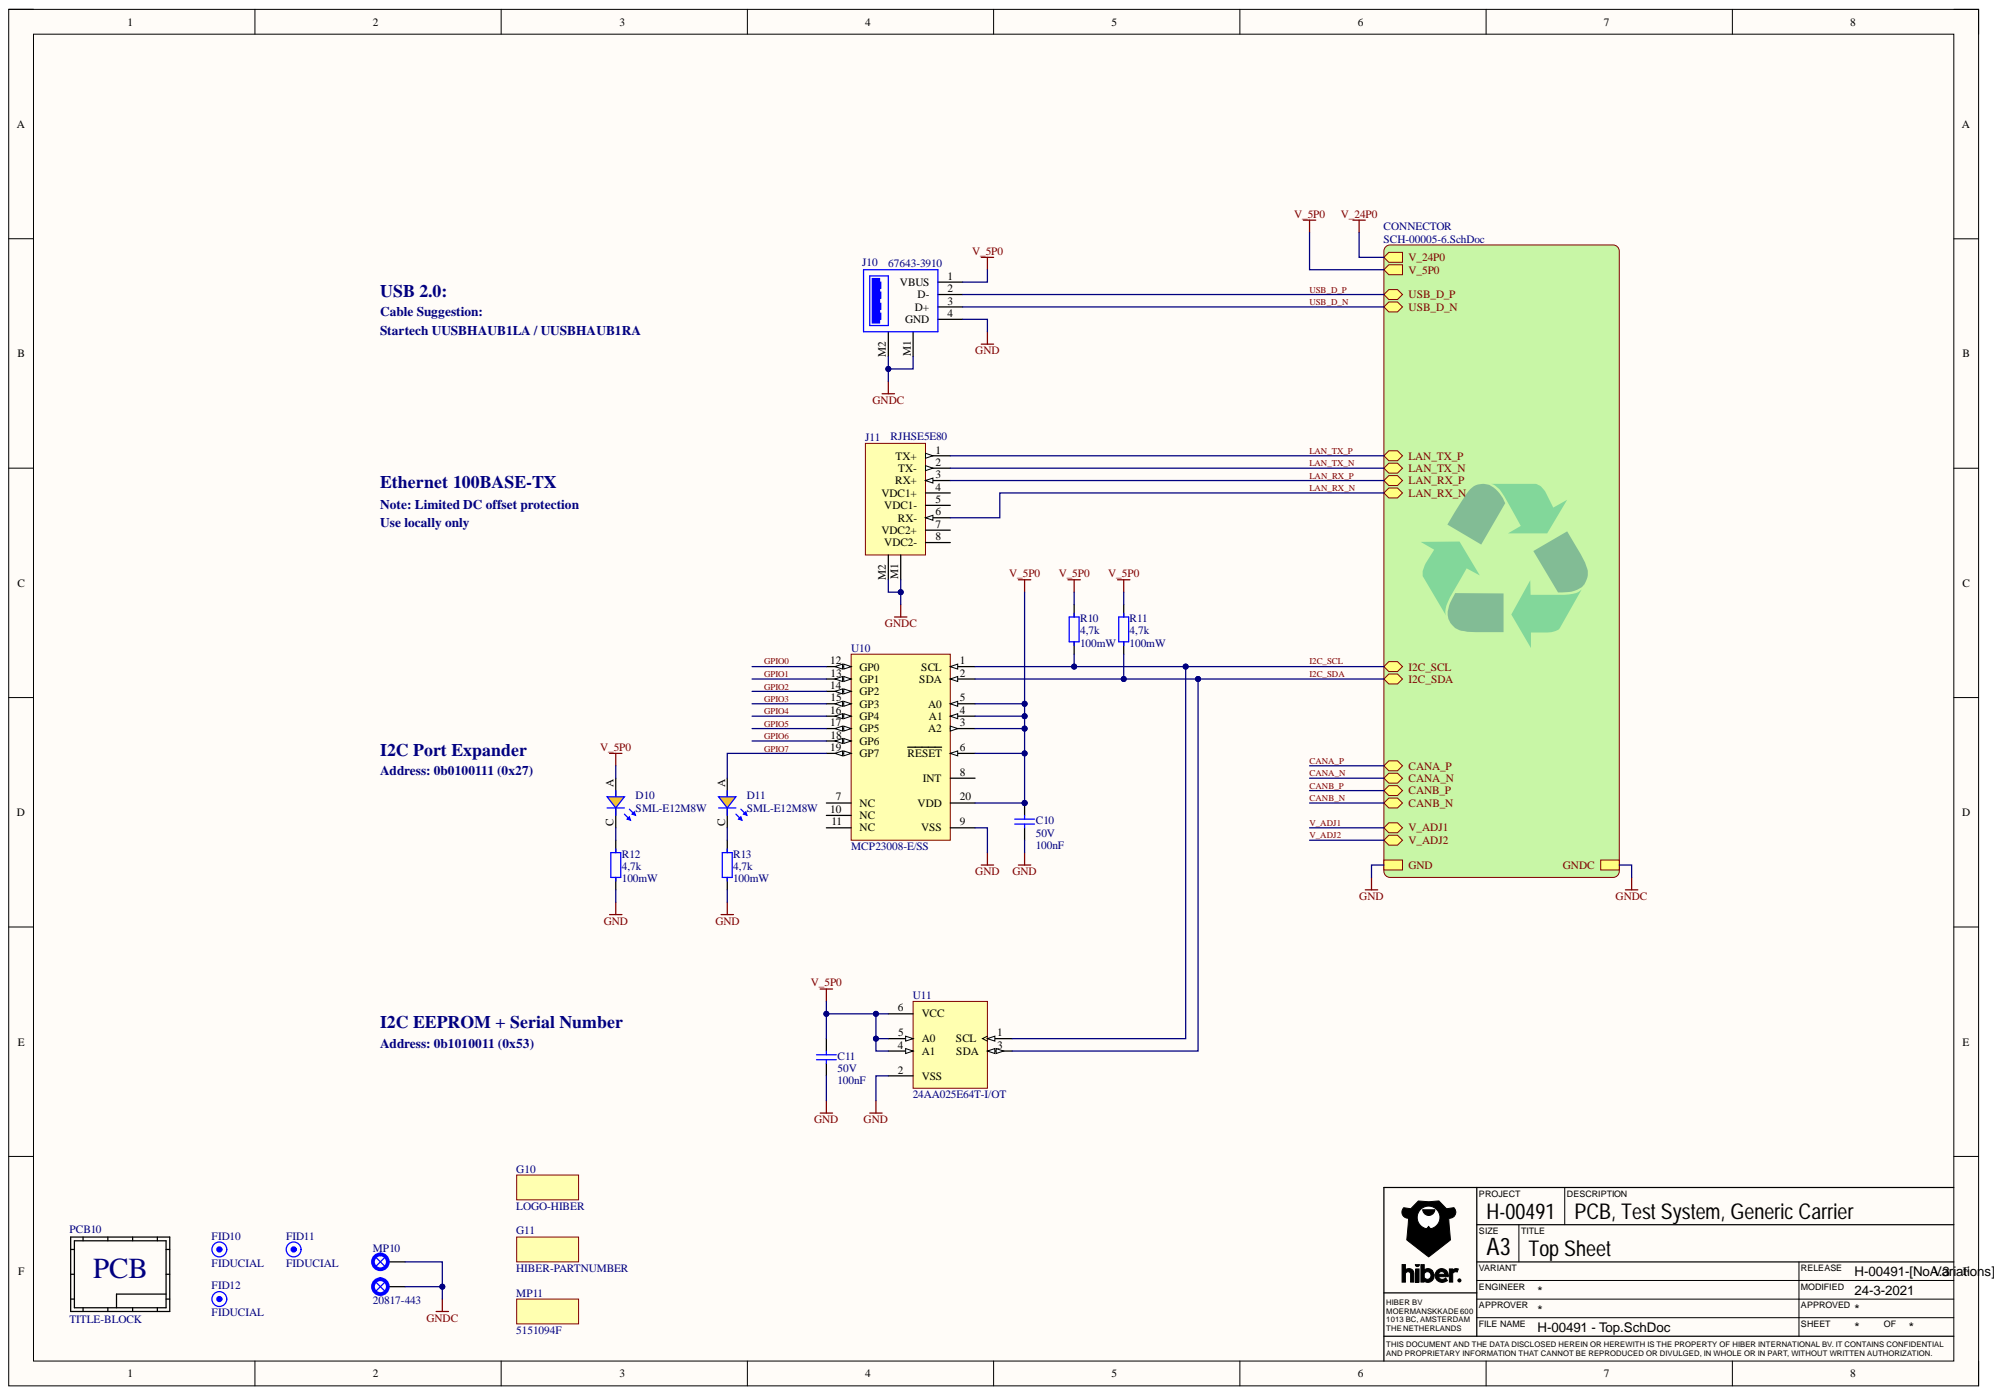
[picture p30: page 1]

TIO
PCB, Test System, Generic Carrier

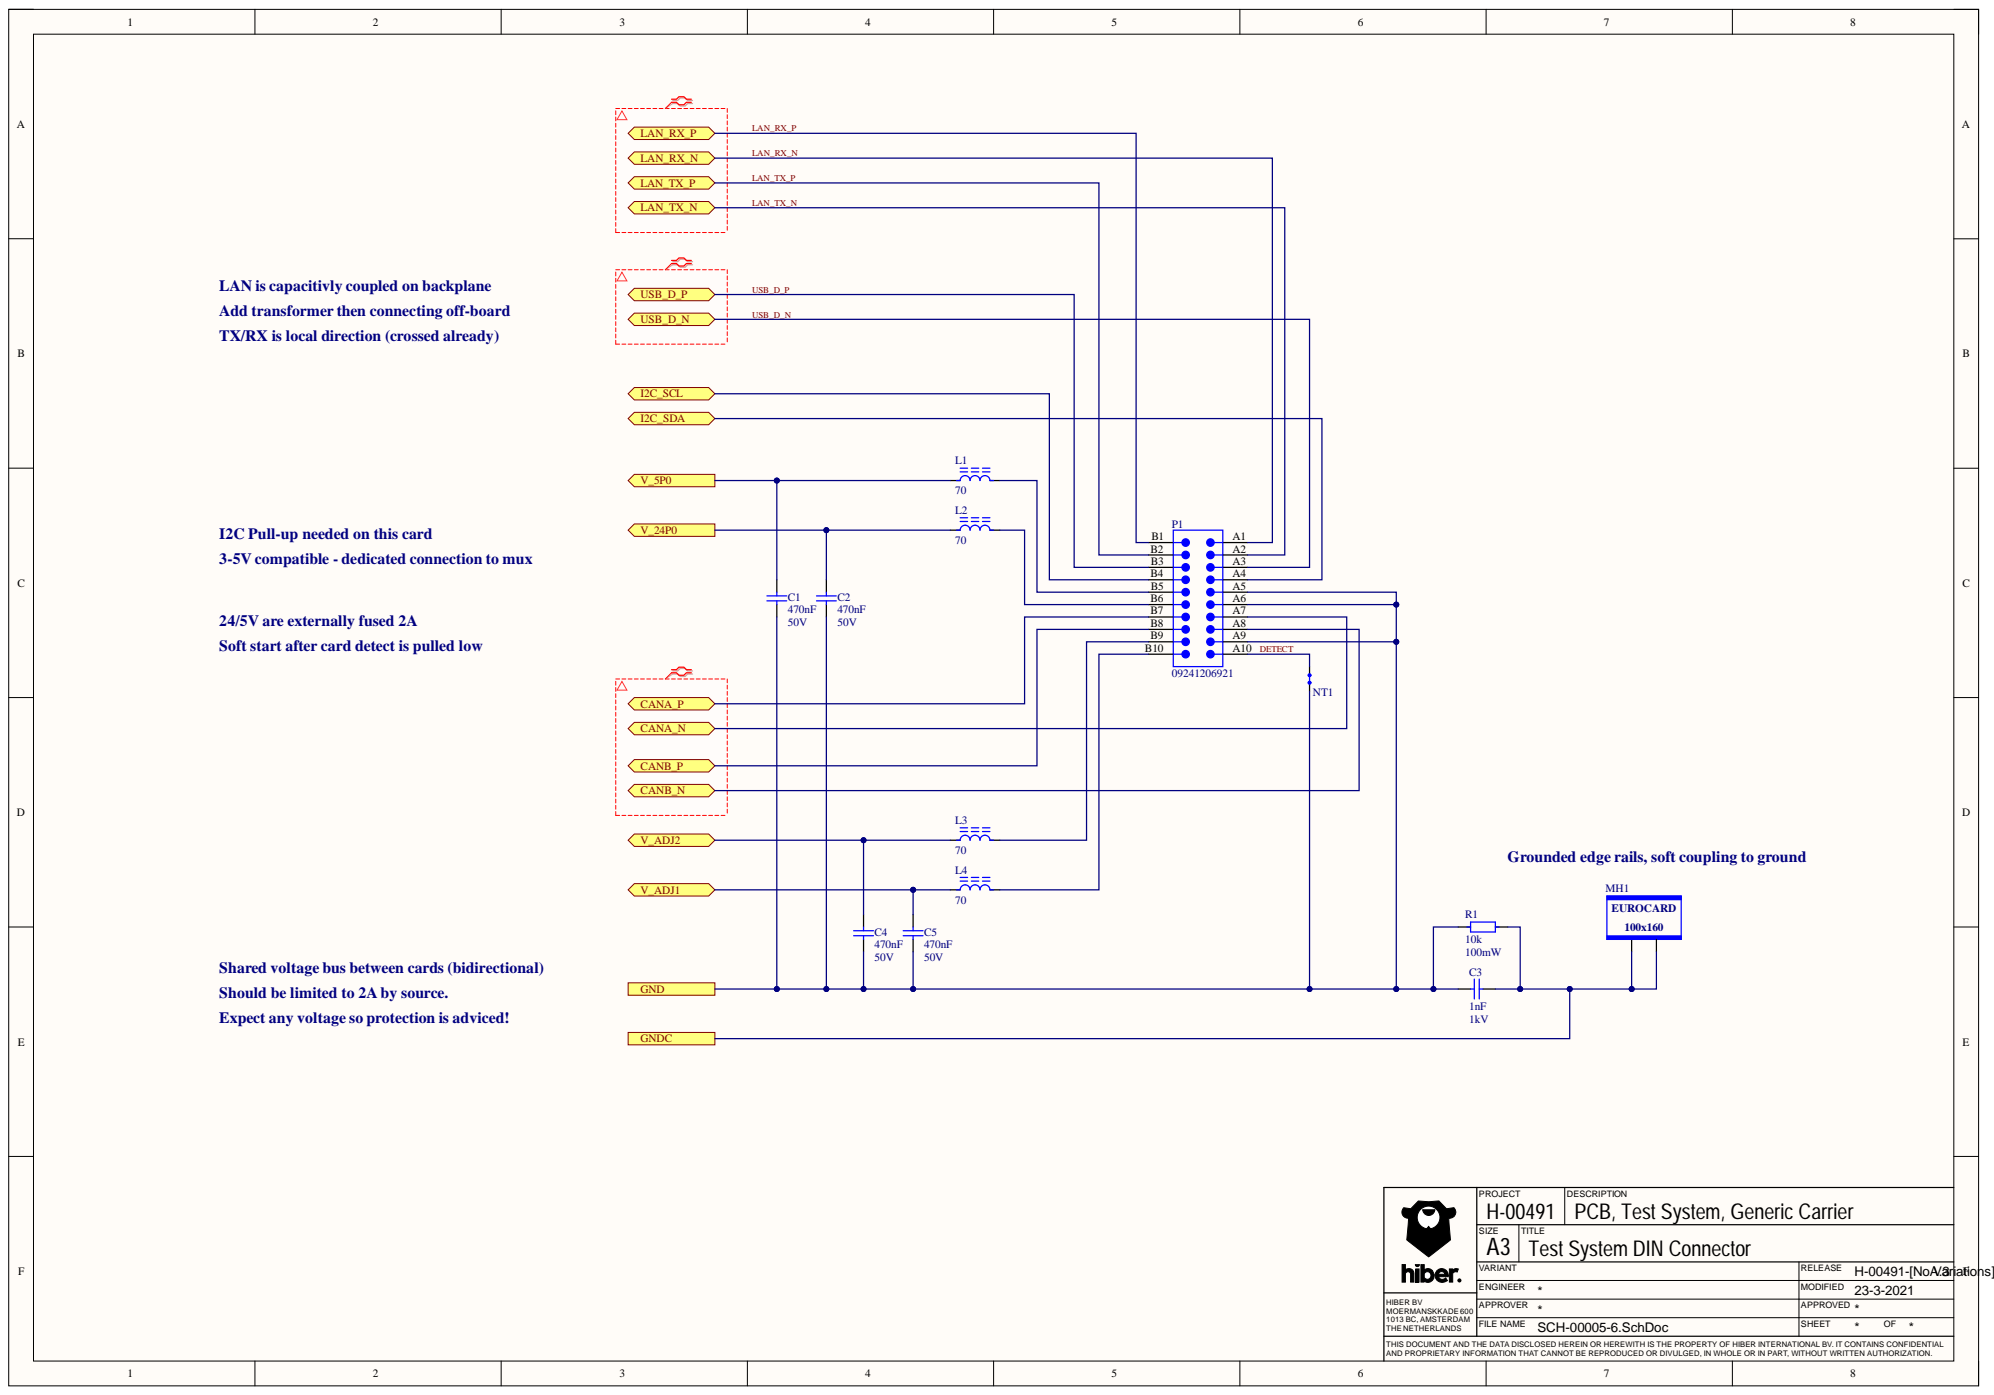
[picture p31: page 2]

LAN_RX_N

LAN_TX_P

LAN_TX_N

LAN is capacitivly coupled on backplane
Add transformer then connecting off-board
TX/RX is local direction (crossed already)

I2C Pull-up needed on this card
3-5V compatible - dedicated connection to mux

B2 | A2
B3 | A3
B4 | A4

24/5V are externally fused 2A
Soft start after card detect is pulled low

DETECT

Grounded edge rails, soft coupling to ground

Shared voltage bus between cards (bidirectional)
Should be limited to 2A by source.
Expect any voltage so protection is adviced!

DESCRIPTION
PCB, Test System, Generic Carrier

THIS DOCUMENT AND THE DATA DISCLOSED HEREIN OR HEREWITH IS THE PROPERTY OF HIBER INTERNATIONAL BV. IT CONTAINS CONFIDENTIAL
AND PROPRIETARY INFORMATION THAT CANNOT BE REPRODUCED OR DIVULGED, IN WHOLE OR IN PART, WITHOUT WRITTEN AUTHORIZATION.

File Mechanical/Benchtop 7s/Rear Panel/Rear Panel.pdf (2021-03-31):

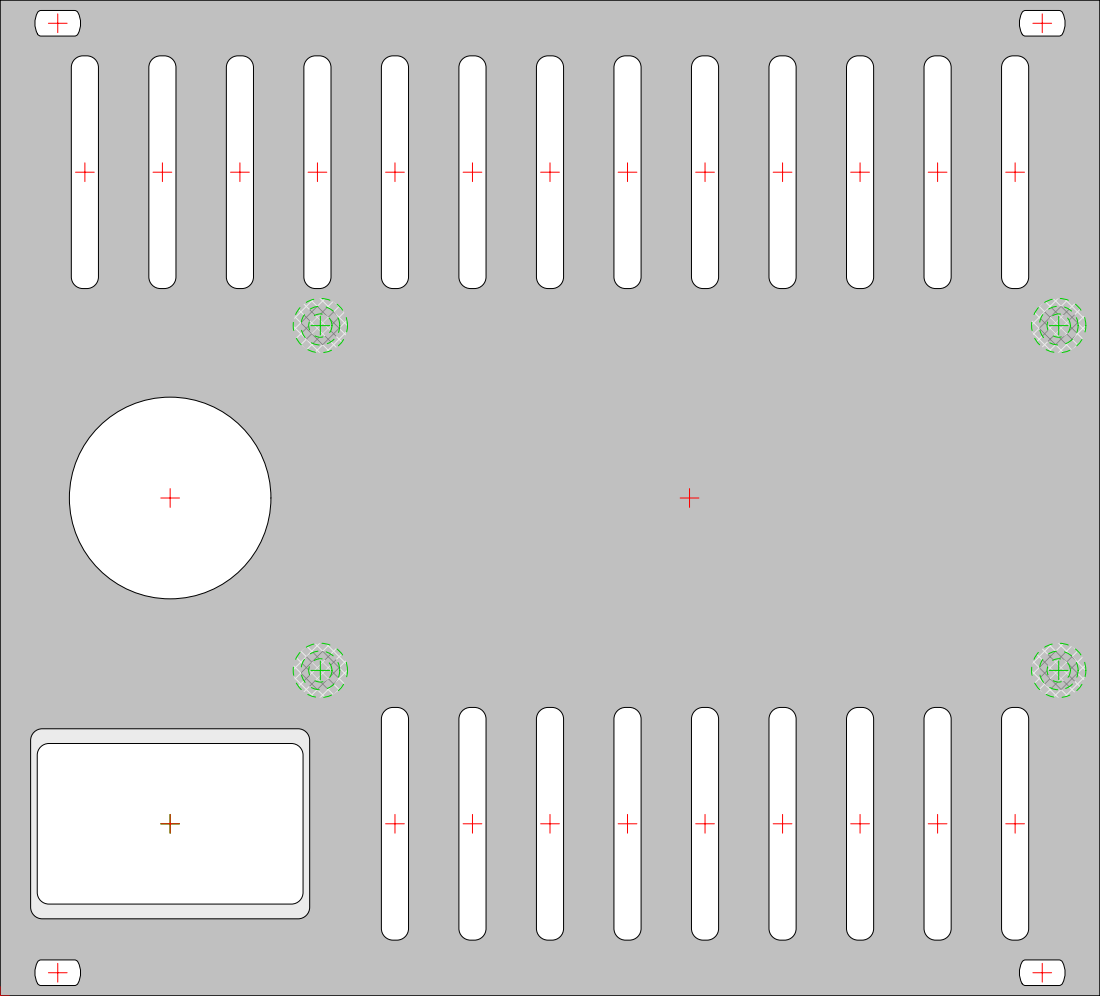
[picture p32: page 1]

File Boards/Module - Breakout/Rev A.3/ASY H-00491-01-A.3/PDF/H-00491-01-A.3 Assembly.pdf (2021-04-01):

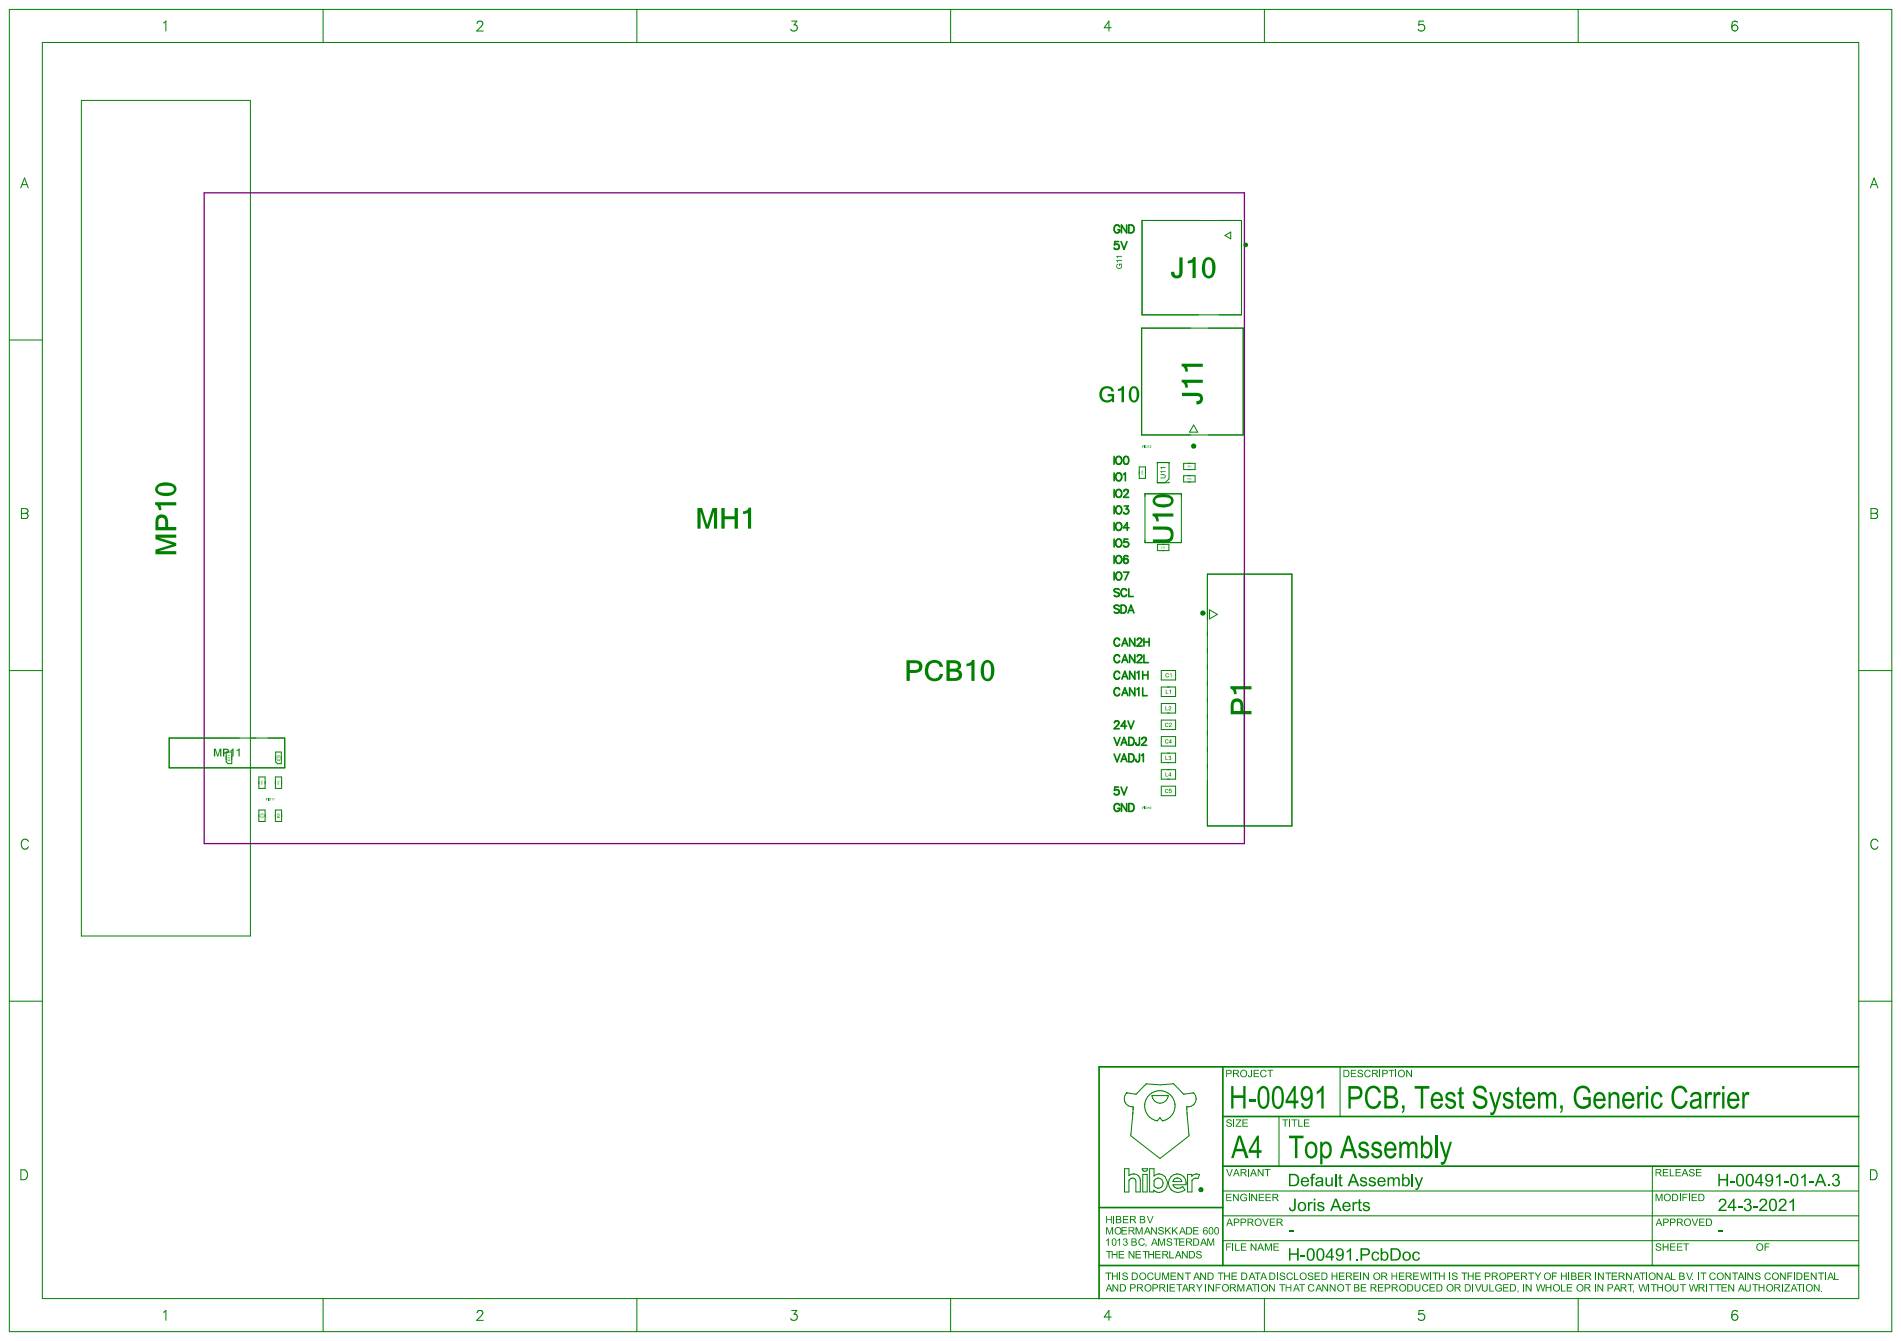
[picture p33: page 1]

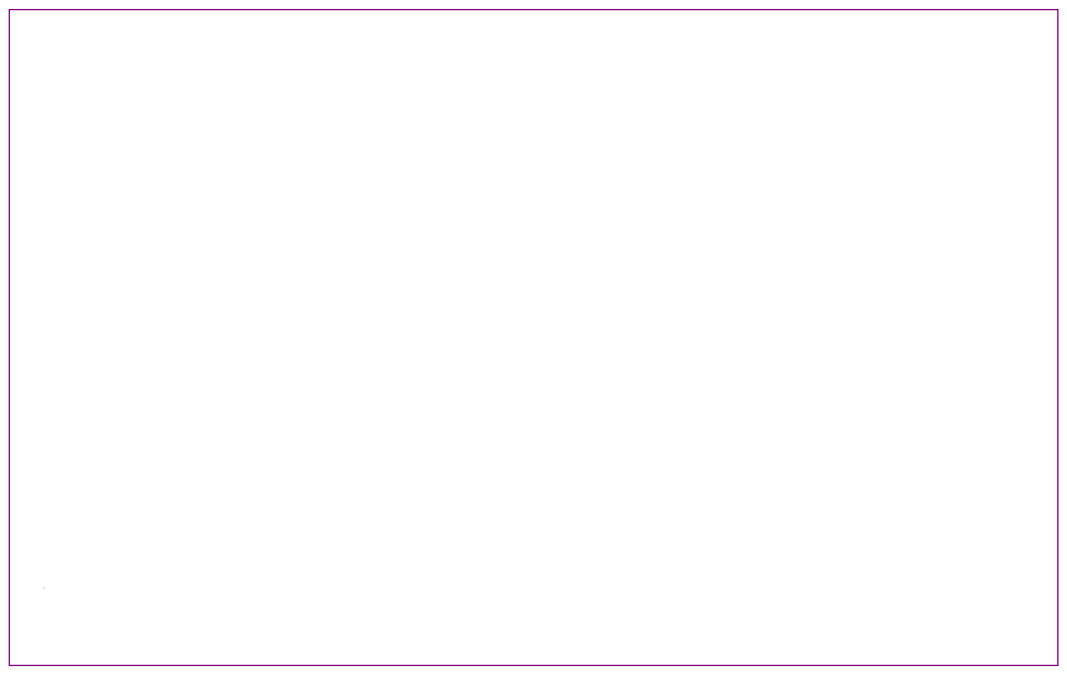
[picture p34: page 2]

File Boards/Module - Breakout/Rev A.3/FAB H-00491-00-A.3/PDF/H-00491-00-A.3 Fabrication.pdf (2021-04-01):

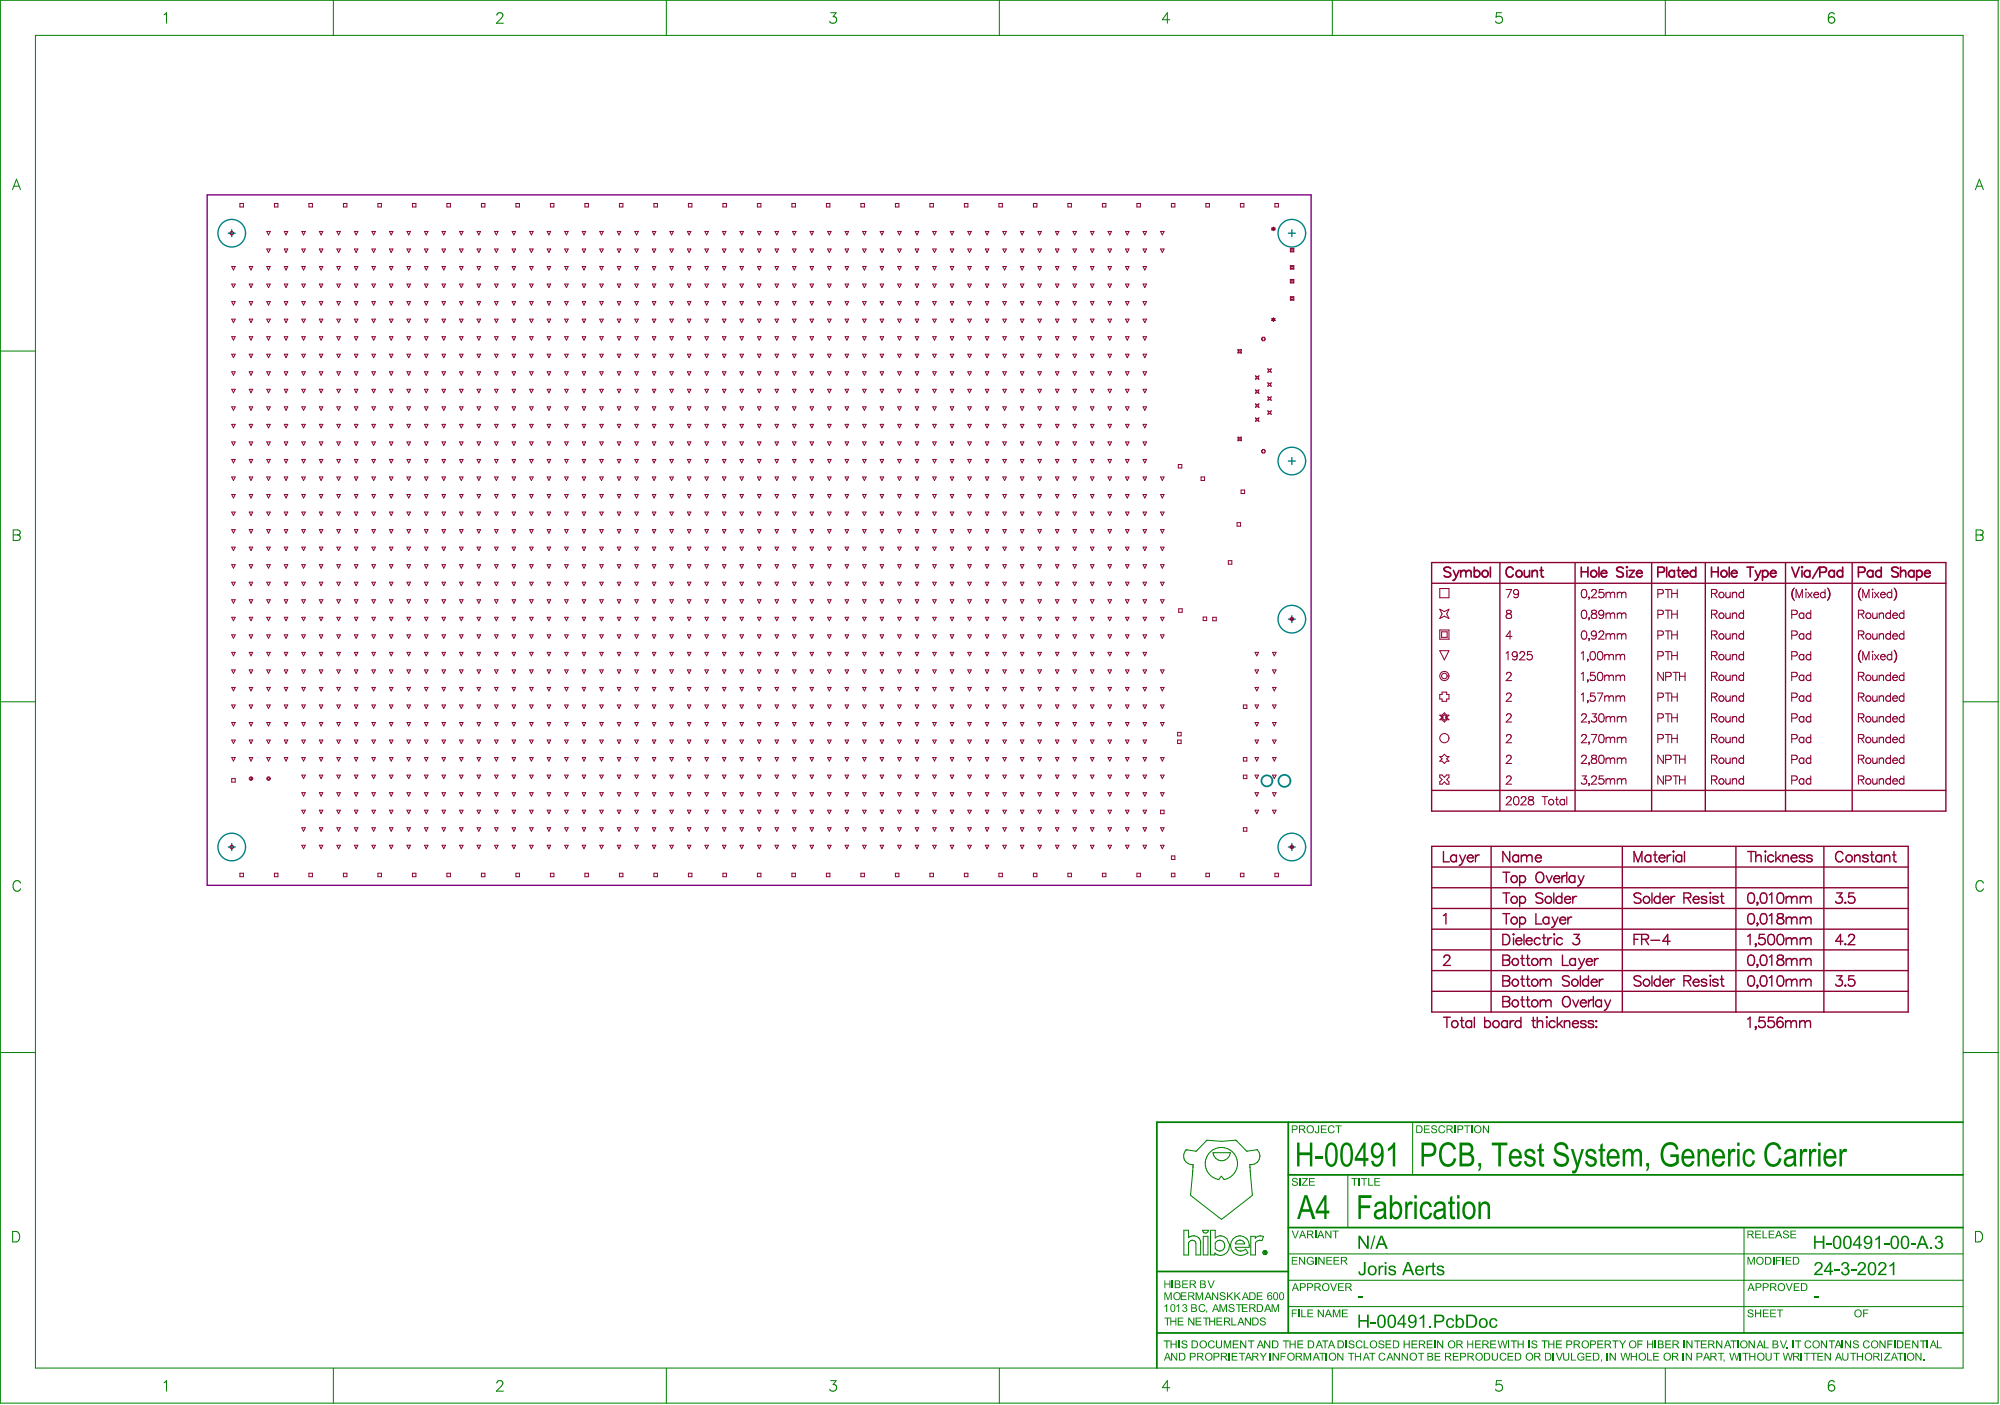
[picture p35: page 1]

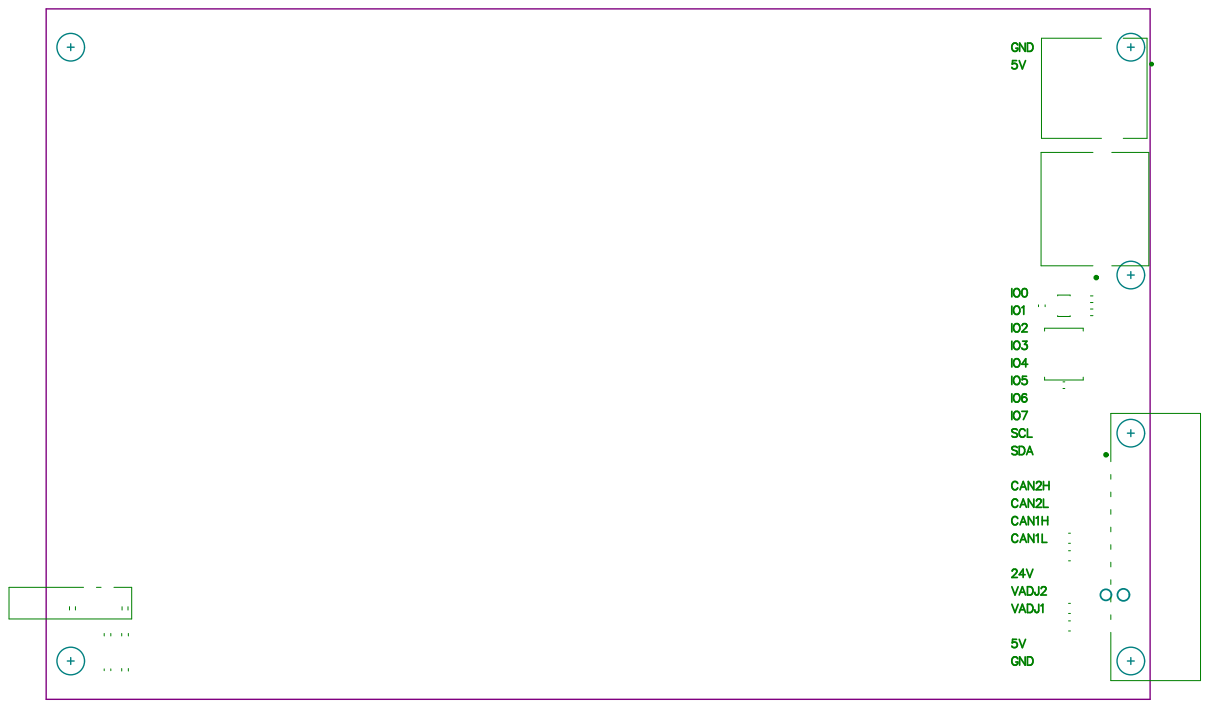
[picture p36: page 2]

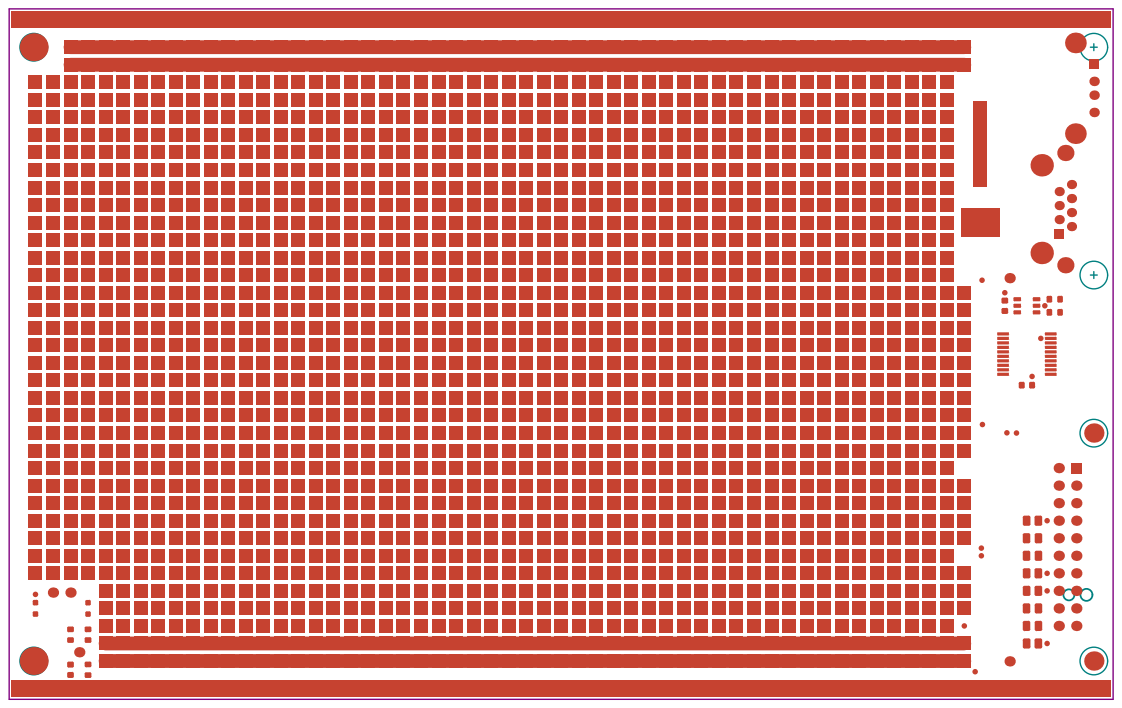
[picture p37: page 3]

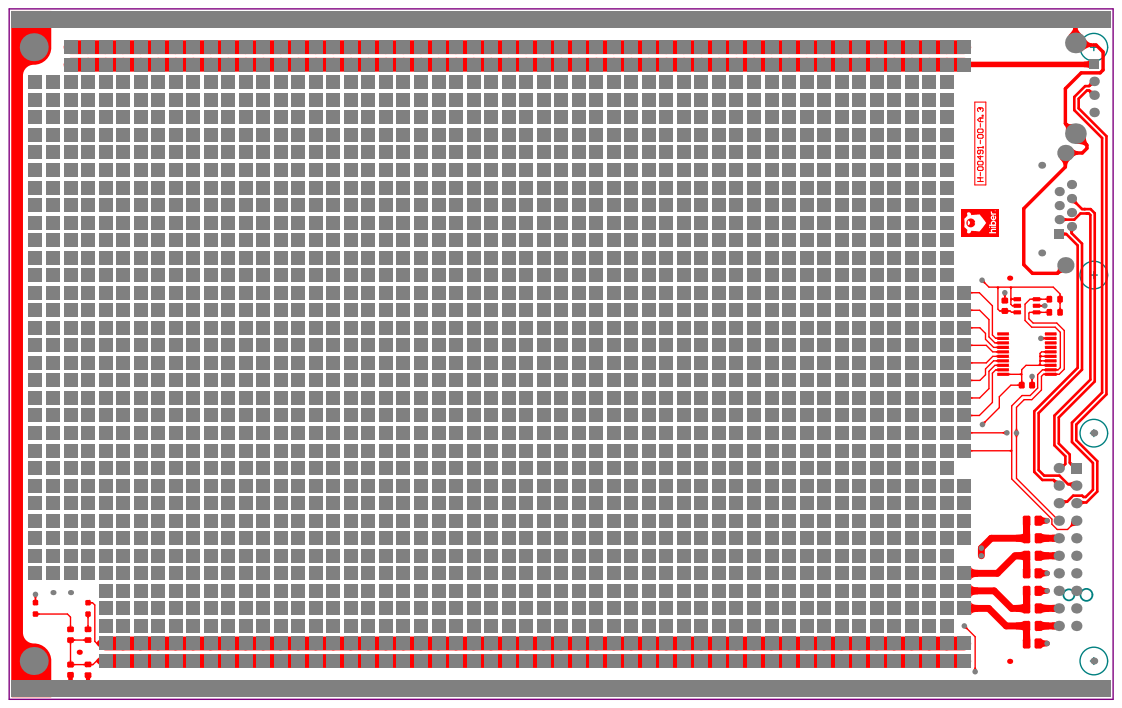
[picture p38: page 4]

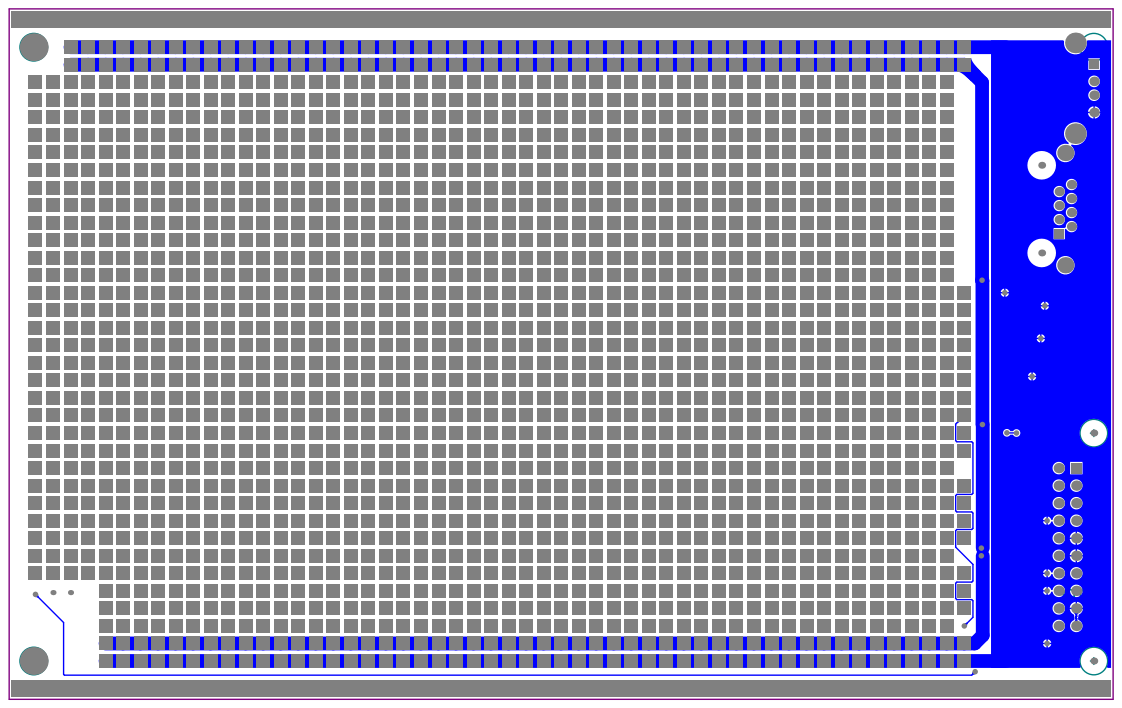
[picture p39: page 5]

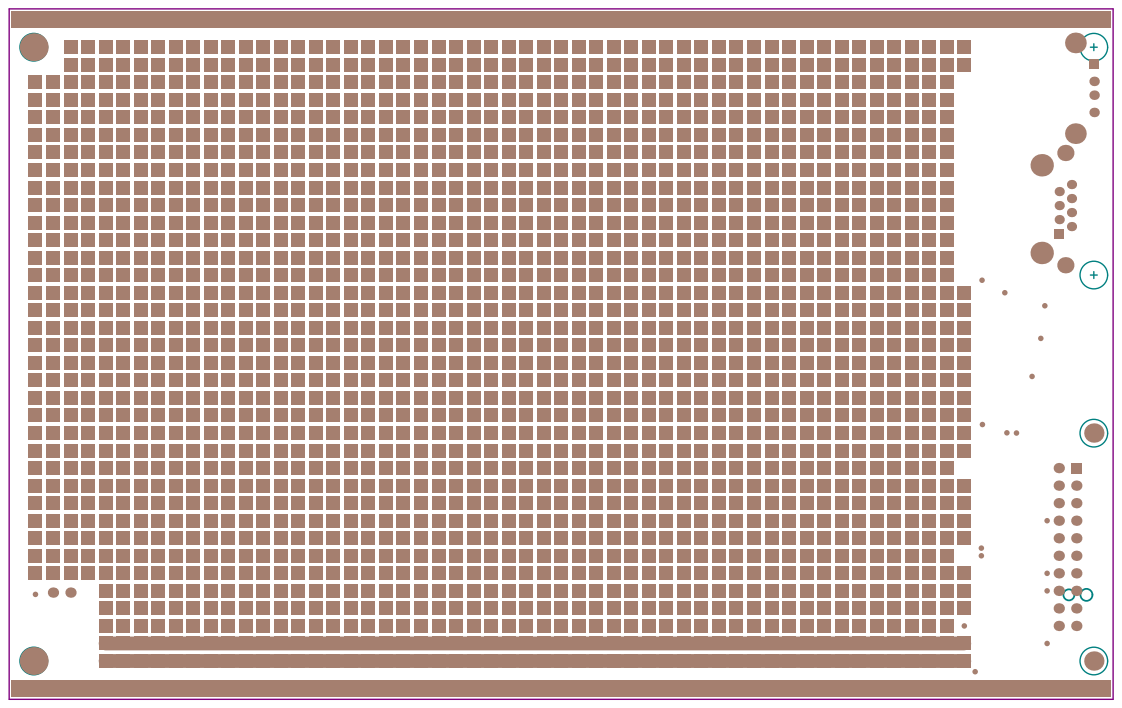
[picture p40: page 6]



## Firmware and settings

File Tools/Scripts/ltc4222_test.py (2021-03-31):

import smbus
import time

# I2C channel 1 is connected to the GPIO pins
I2C_CHANNEL = 1

# Board Configurations
POSITION_ALONE  = "alone"
POSITION_LEFT   = "left"
POSITION_MIDDLE = "middle"
POSITION_RIGHT  = "right"

MUX_ADDRESS = {
    POSITION_ALONE :  0x71,
    POSITION_LEFT :   0x70,
    POSITION_MIDDLE : 0x72,
    POSITION_RIGHT :  0x73,
}

HOTSWAP_ADDRESS =                                               {
    POSITION_ALONE :  [0x70, 0x70, 0x70, 0x70, 0x70, 0x70, 0x70, 0x70],
    POSITION_LEFT :   [0x54, 0x55, 0x56, 0x57, 0x5c, 0x5d, 0x5e, 0x5f],
    POSITION_MIDDLE : [0x64, 0x65, 0x66, 0x67, 0x6c, 0x6d, 0x6e, 0x6f],
    POSITION_RIGHT :  [0x44, 0x45, 0x46, 0x47, 0x4c, 0x4d, 0x4e, 0x4f],
}



def BIT(num):
    return 1 << num

class LTC4222:
    # Registers
    LTC4222_CONTROL1    = 0xd0
    LTC4222_ALERT1      = 0xd1
    LTC4222_STATUS1     = 0xd2
    LTC4222_FAULT1      = 0xd3
    LTC4222_CONTROL2    = 0xd4
    LTC4222_ALERT2      = 0xd5
    LTC4222_STATUS2     = 0xd6
    LTC4222_FAULT2      = 0xd7
    LTC4222_SOURCE1     = 0xd8
    LTC4222_SOURCE2     = 0xda
    LTC4222_ADIN1       = 0xdc
    LTC4222_ADIN2       = 0xde
    LTC4222_SENSE1      = 0xe0
    LTC4222_SENSE2      = 0xe2
    LTC4222_ADC_CONTROL = 0xe4

    # Fault register bits
    FAULT_OV            = BIT(0)
    FAULT_UV            = BIT(1)
    FAULT_OC            = BIT(2)
    FAULT_POWER_BAD     = BIT(3)
    FAULT_FET_BAD       = BIT(5)

    # Constants (in mv)
    RES_ADIN_MV         = 0.00125
    RES_SOURCE_MA       = 0.03125
    RES_SENSE_MV        = 0.0000625

    def __init__(self, bus, address, shunt_value):
        self.bus = bus
        self.address = address
        self.shunt_value = shunt_value

    # Return the voltage from the given register in mV or mA
    def get_value(self, reg):
        # Read word, Endianness swap, Shift right to remove padding
        val = self.bus.read_word_data(self.address, reg)
        val = ((val & 0xFF) << 8) + ((val & 0xFF00) >> 8)
        val = val >> 6

        if(reg in [self.LTC4222_ADIN1, self.LTC4222_ADIN2]):
            val = val * self.RES_ADIN_MV

        elif(reg in [self.LTC4222_SOURCE1, self.LTC4222_SOURCE2]):
            val = val * self.RES_SOURCE_MA

        elif(reg in [self.LTC4222_SENSE1, self.LTC4222_SENSE2]):
            val = val * self.RES_SENSE_MV

        else:
            raise ValueError

        return val;

    def get_voltage(self, channel):
        return self.get_value(self.LTC4222_SOURCE1 if channel == 1 else self.LTC4222_SOURCE2)

    def get_current(self, channel):
        return self.get_value(self.LTC4222_SENSE1 if channel == 1 else self.LTC4222_SENSE2) / self.shunt_value

    def get_status(self, channel):
        return self.bus.read_byte_data(self.address, self.LTC4222_STATUS1 if channel == 1 else self.LTC4222_STATUS2)

    def print_status(self, name):
        voltage1 = self.get_voltage(1)
        voltage2 = self.get_voltage(2)
        current1 = self.get_current(1)
        current2 = self.get_current(2)
        enabled1 = "X" if self.get_status(1) & 0x10 else "-"
        enabled2 = "X" if self.get_status(1) & 0x10 else "-"

        name = "{} [{:02x}]".format(name, self.address)

        return "{:} {} {:10.3f}V {:10.3f}A / {} {:10.3f}V {:10.3f}A\n".format(name, enabled1, voltage1, current1, enabled2, voltage2, current2)


class TCA9548:
    def __init__(self, bus, address):
        self.bus = bus
        self.address = address

    def set(self, value):
        self.bus.write_byte(self.address, value)

    def get(self):
        return self.bus.read_byte(self.address)

class Backplane:
    BOARDS = [POSITION_RIGHT, POSITION_MIDDLE, POSITION_LEFT]
    SHUNT_VALUE_MAIN = 0.01
    SHUNT_VALUE_SLOT = 0.025

    def __init__(self, bus):
        slots = sum([HOTSWAP_ADDRESS[x][1:8] for x in self.BOARDS], [])
        self.mux = [TCA9548(bus, MUX_ADDRESS[x]) for x in self.BOARDS]
        self.main = [LTC4222(bus, HOTSWAP_ADDRESS[x][0], self.SHUNT_VALUE_MAIN) for x in self.BOARDS]
        self.slots = [LTC4222(bus, s, self.SHUNT_VALUE_SLOT) for s in slots]

    def mux_status(self):
        for m in self.mux:
            print("Mux {:02x} = {:02x}".format(m.address, m.get()))

    def power_status(self):
        buf = "----------\n"

        for num, m in enumerate(self.main):
            buf += m.print_status("M{}--".format(num))
        for num, s in enumerate(self.slots):
            seg = int(num / 7)
            pos = num % 7
            if pos == 0:
                buf += "\n"
            buf += s.print_status("S{:}-{:}".format(seg+1, pos+1))

        print(buf)

# Initialize I2C (SMBus)
bus = smbus.SMBus(I2C_CHANNEL)

plane = Backplane(bus)
plane.mux_status()

while 1:
    plane.power_status()
    time.sleep(0.5)

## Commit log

2021-03-31 Check-in files
    [Front Panel ELW2106AA.stp, H-00488 - Card Slot Master.SchDoc, H-00488 - Card Slot.SchDoc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]
2021-03-31 Updated CM4 Frontpanel
    [Front Panel ELW2106AA.dxf, Front Panel ELW2106AA.stp]
2021-03-31 Update CM4 Frontpanel
    [20817443 Hardware Only.stp, ELW2106AA A.1.stp]
2021-04-01 Add output files for breakout module
    [H-00491 - Top.SchDoc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]
2021-04-06 Include Backplane fab/asy outputs
    [H-00488 - Card Slot Master.SchDoc, H-00488 - Card Slot.SchDoc, H-00488 - Connectors Downstream.SchDoc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]
2021-04-07 Add breakout board known issue
